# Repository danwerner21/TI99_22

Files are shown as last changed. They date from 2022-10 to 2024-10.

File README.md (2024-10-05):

# Texas Instruments TI99/4A Clone(ish) Project

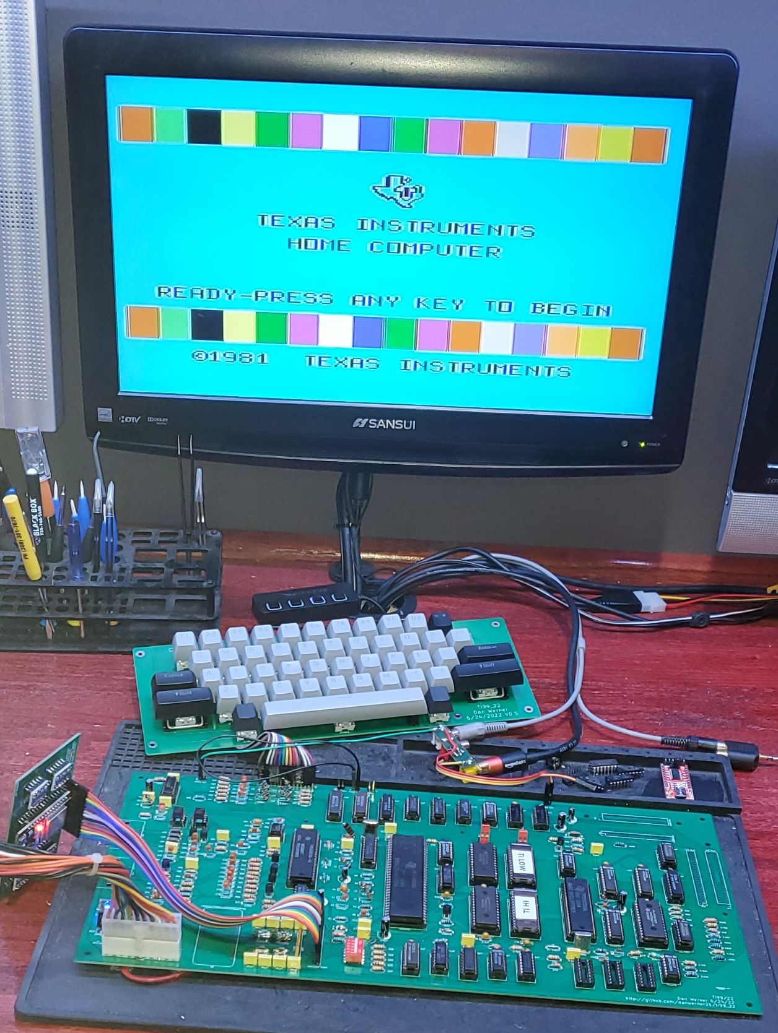
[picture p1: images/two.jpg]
System


Note that this is not a fully tested project at this point. . . .

This is based Rob Krenicki's design that is based on the HackMac KiCAD schematics.  I have made several changes to the original design including:

* Placing 32K of 16bit wide fast ram on the board to fully populate the address space
* Placing an EPROM on the main board that can be used as an on-board cartridge ROM
* adding a header to allow a microcontroller to replace the GROM chips (hopefully this can be moved on-board soon)
* replacing the video DRAM with SRAM
* Updating the Keyboard header to support a soft caps lock switch on the keyboard PCB
* designing a Cherry MX keyboard
* adding headers for the GROM and expansion port to support riser cards for these ports

If there are any questions, I can be reached at vic2020Dan at gmail dot com.

## ToDo
* Cleanup/Documentation
Possible Future Thoughts:
* Redo the Board in an ATX form factor with PEB slots on board
* Add Support for the Pico9918 on-board
* Add Support for a Tang Nano FPGA TMS9918 replacement 
* Add Hex-bus port
* Add a DIN 5-pin Composite video/Audio out. 
* Add built in speech synthesis
* Clone Disk IO card
* Relocate all the ports to the back of the motherboard

* It has been suggested that we also have a console style version of the next revision as not everyone has a desire for a larger PE style machine
* Also perhaps add some keys to the keyboard

## DIP Switch Settings
The DIP switch on the main board allows one to configure which bank areas are populated with RAM.

RAM0 enables RAM to addresses >2000-3FFF (Lo Memory Expansion)
RAM1 enables RAM to addresses >A000-BFFF (Hi Memory Expansion)
RAM2 enables RAM to addresses >C000-DFFF (Hi Memory Expansion)
RAM3 enables RAM to addresses >E000-FFFF  (Hi Memory Expansion)
RAM4 enables RAM to addresses >8000-83FF (Normal TI Scratch Pad RAM)

Note that I have never actually tested off-board 8 bit RAM, so this is new territory and might need some debugging 😊   
also on-board RAM is 16 bit – so all of those external RAM sources will be slower. 

## Bugs
* on rev 0.95 R36-40 are listed as 100K ohm, they are actually 100 ohm
* on rev 0.95 the joystick and cassette connectors are mirrored and need to be mounted on the bottom side of the board to function
* Both of these are corrected in 0.96

* The reset button J1 should be attached to pin 5 of U1 not Pin 4

## Bill of Materials
### Console
Qty|Reference(s)|Part
---|------------|----
6|C1, C9, C11, C58, C73, C75|0.001uF
1|C2|22pF
3|C3, C5, C59|22uF
12|C4, C7, C13, C14, C20, C54, C55, C62, C64, C68, C71, C74|0.1uF
1|C6|1uF
7|C8, C52, C63, C65, C66, C67, C72|0.01uF
1|C10|100uF
1|C12|0.01uF
7|C15, C16, C17, C19, C21, C22, C60|100uF
30|C18, C23, C24, C25, C26, C27, C28, C29, C30, C31, C32, C33, C34, C35, C36, C37, C38, C39, C40, C41, C42, C43, C44, C45, C46, C47, C48, C49, C50, C51|0.1uF
1|C53|100uF
1|C56|12pF
1|C57|56pF
1|C61|220uF
1|C69|220pF
1|C70|0.022uF
2|CR1, CR4|1N4148
2|CR2, CR3|1N914B
1|D1|LED
1|J1|Connector PinHeader 2.54mm:PinHeader 1x02 P2.54mm Vertical
1|J2|Connector PinHeader 2.54mm:PinHeader 1x02 P2.54mm Vertical
1|J3|TerminalBlock RND:TerminalBlock RND 205-00278 1x04 P5.00mm Vertical
1|J4|Connector PinHeader 2.54mm:PinHeader 1x16 P2.54mm Vertical
2|J5, J6|Connector PinHeader 2.54mm:PinHeader 1x03 P2.54mm Vertical
1|J7|Connector PinHeader 2.54mm:PinHeader 1x03 P2.54mm Vertical
1|J8|Connector PinHeader 2.54mm:PinHeader 1x02 P2.54mm Vertical
1|J9|Connector PinHeader 2.54mm:PinHeader 1x02 P2.54mm Vertical
1|J10|Connector Dsub:DSUB-9 Female Horizontal P2.77x2.84mm EdgePinOffset4.94mm Housed MountingHolesOffset7.48mm
1|J11|Connector PinHeader 2.54mm:PinHeader 1x18 P2.54mm Vertical
1|J12|Connector PinHeader 2.54mm:PinHeader 2x22 P2.54mm Vertical
1|J13|WernerCustomLibrary:44 Pin Card Edge
1|J14|Library:CardEdge 34Pin 2.54mm Vertical
1|J15|Connector PinHeader 2.54mm:PinHeader 2x18 P2.54mm Vertical
1|J16|Connector PinSocket 2.54mm:PinSocket 1x03 P2.54mm Vertical
1|J17|Connector PinSocket 2.54mm:PinSocket 1x03 P2.54mm Vertical
1|J18|Connector Dsub:DSUB-9 Female Horizontal P2.77x2.84mm EdgePinOffset4.94mm Housed MountingHolesOffset7.48mm
1|L1|0.33uH
2|L4, L5|6.8uH
1|L7|5.8uH
1|L8|INDUCTOR (Ferrite BEAD)
7|L10, L11, L12, L13, L14, L15, L16|8.2uH
3|Q1, Q3, Q4|TIS92
1|Q2|2N3904
1|R1|150k
7|R2, R9, R11, R18, R34, R35, R46|1k
1|R3|12k
1|R4|47k
4|R5, R6, R7, R8|22
5|R10, R26, R45, R52, R53|4.7k
5|R12, R13, R14, R15, R16|1K
3|R17, R48, R50|2.2k
2|R19, R30|470
1|R20|270
1|R21|1.5k x 9 SIP bussed
1|R22|361
3|R23, R73, R75|5.6k
2|R24, R27|10
1|R25|150
1|R28|470k
1|R29|0
2|R31, R33|75
1|R32|470
4|R41, R42, R43, R44|62
1|R47|3.3k
9|R36, R37, R38, R39, R40, R49, R51, R54, R56|100
1|R55|330
1|R57|10k
1|R58|6.8k
1|R59|39k
1|R60|6.8k
4|R61, R62, R67, R68|1K
1|R63|120k
1|R64|2.7k
3|R65, R66, R76|220
1|R69|10K
1|R70|9.1k
2|R71, R72|10k
1|R74|5.6K
1|R77|15
2|RN1, RN2|10K x 9 SIP Bussed
1|SW1|DIP switchx05
1|SW2|Pin Header 01x02 Male
1|U1|TMS9904 (note this needs to be a 9904 not 9904ANL.  If the 9904ANL is used, Y1 needs to be substituted with 12Mhz, L1 needs to be substituted with 3.3uh and C2 needs to be substituted with 50pf)
1|U2|TMS9900
4|U3, U15, U22, U24|74LS04
2|U4, U9|74LS32
2|U5, U8|74LS138
1|U6|74LS03
1|U7|74LS08
3|U10, U14, U18|74LS00
2|U11, U41|74LS244
1|U12|74LS373
1|U13|74LS245
1|U16|74LS74
1|U17|74LS194
1|U19|LM2901
1|U20|LM7905 TO220
1|U21|LM2903
3|U26, U27, U28|TMC0430
3|U29, U30, U37|HM62256BLP
2|U31, U32|27C64
1|U33|SN76489
1|U34|TMS9918
3|U35, U36, U38|74LS574
1|U39|TMS9901
1|U40|74LS156
2|U42, U43|74LS367
1|U44|74LS379
1|U45|27C010
1|U46|RC4558
1|U47|74LS06
2|U48, U49|TIL119
1|Y1|48.000 MHz Crystal
1|Y2|10.7MHz Crystal

# Keyboard
Qty|Reference(s)|Value|Part
---|------------|-----|----
1|C1|0.1uF|Capacitor
1|D1|LED|LED
1|D2|LED|LED
1|J1|Pin Header 1x18 male|Pin Header 1x18 male
2|R1, R2|470 ohm|Resistor
1|R3|1K ohm|Resistor
48|SW1-SW48|Mechanical Switch|Cherry MX Switch (or compatible)
1|U1|ATtiny13A-P|IC
1|U2|74LS125|IC
3||Switch Stabilizer 2.25|
1||Switch Stabilizer 6.25|
1||Optional Alignment frame (will need modified)|
|||
|Stabilizers (frame not used):|https://www.amazon.com/Genuine-Cherry-PCB-Snap-Stabilizers/dp/B085T8QZJC|
|Stabilizers (Frame used)|https://www.amazon.com/dp/B082X4V9VC|
|Frame:|https://www.amazon.com/gp/product/B07MMB33WG|

# Cartridge Riser
Qty|Reference(s)|Part|Type
---|------------|----|----
1|J1|Pin Header 01x18 Male|Pin Header 01x18 Male
1|J2|36 Pin Edge Connector|CONN EDGE DUAL FMALE 36POS 0.100 spacing

# IO Riser
Qty|Reference(s)|Part|Type
---|------------|----|----
1|J1|Pin Header 2x22 Male|Pin Header 2x22 Male

# UNICORN BOARD
Qty|Reference(s)|Part|Type
---|------------|----|----
1|J1|Pin Header Socket 01x16 Female Right Angle|Pin Header Socket 01x16 Female Right Angle
4|U1-U4|Level Shifter|https://www.amazon.com/KeeYees-Channels-Converter-Bi-Directional-Shifter/dp/B07LG646VS
1|U5|ESP32 Devkit|https://www.amazon.com/Development-Microcontroller-Integrated-Antenna-Amplifiers/dp/B09GK74F7N

## License

The original project was licensed under the Creative Commons - Attribution - ShareAlike 3.0 License

## Attribution

This board was derrived from works by, uses design elements from, or contains sofware writen by the following:
* Rob Krenicki (https://github.com/rkrenicki/TI99-Motherboard)
* HackMac (https://bitbucket.org/hackmac/ti-schematics/wiki/Home)

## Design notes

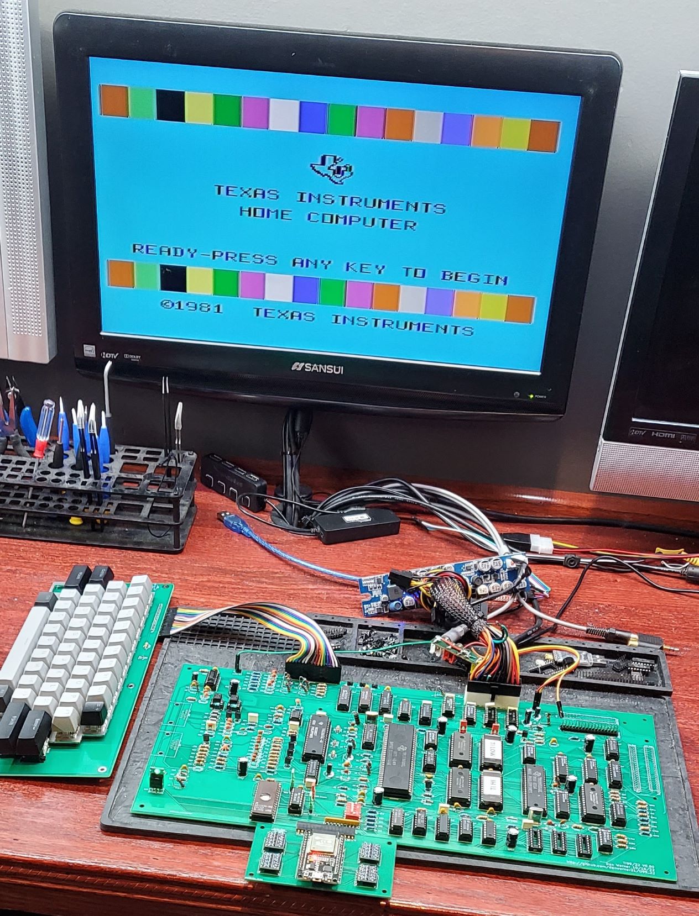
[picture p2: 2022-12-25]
images/three.jpg

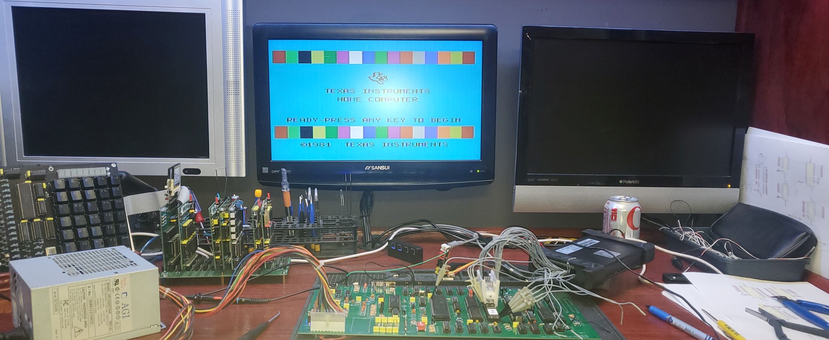
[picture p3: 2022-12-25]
images/one.jpg

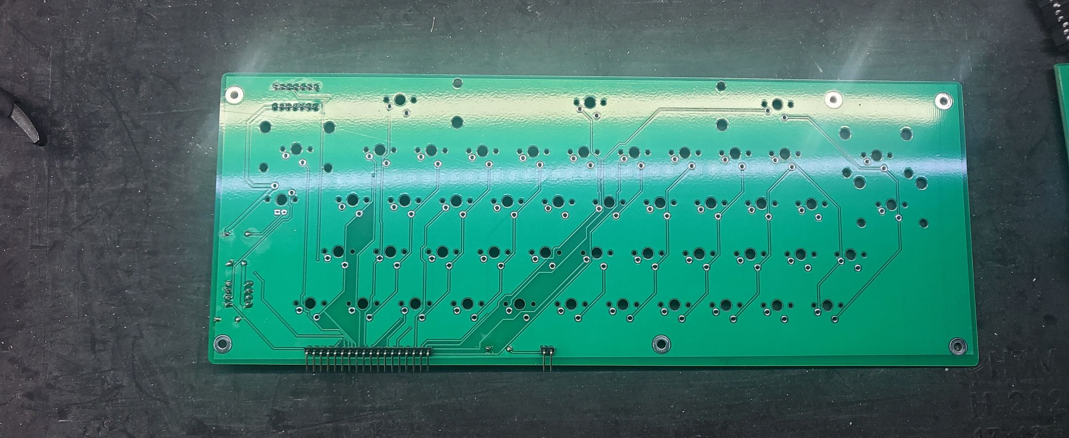
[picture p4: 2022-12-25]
images/a.jpg

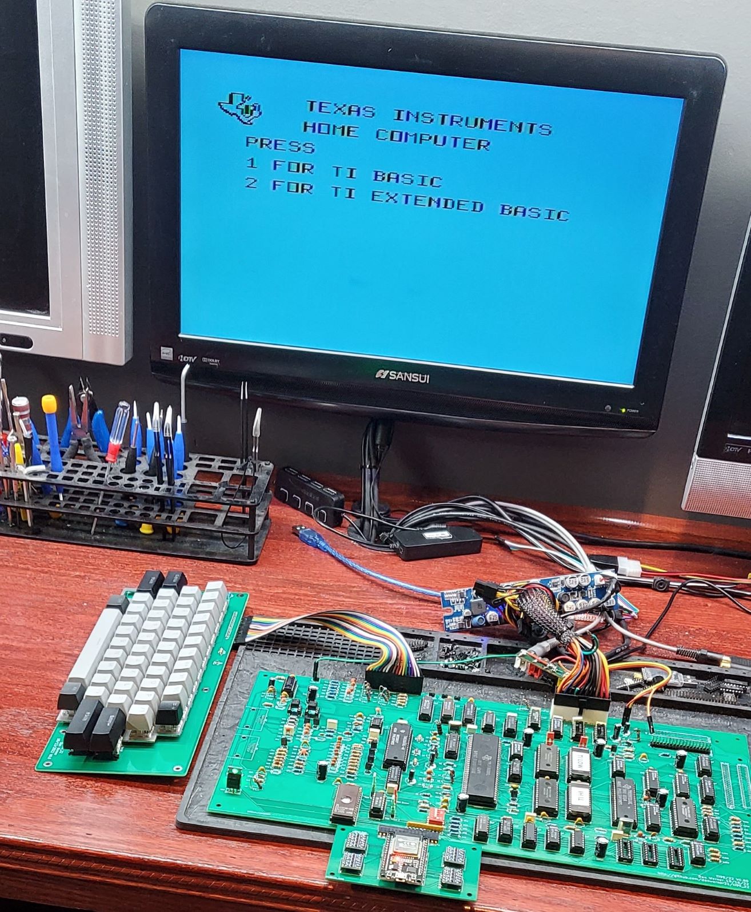
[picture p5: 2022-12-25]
images/four.jpg

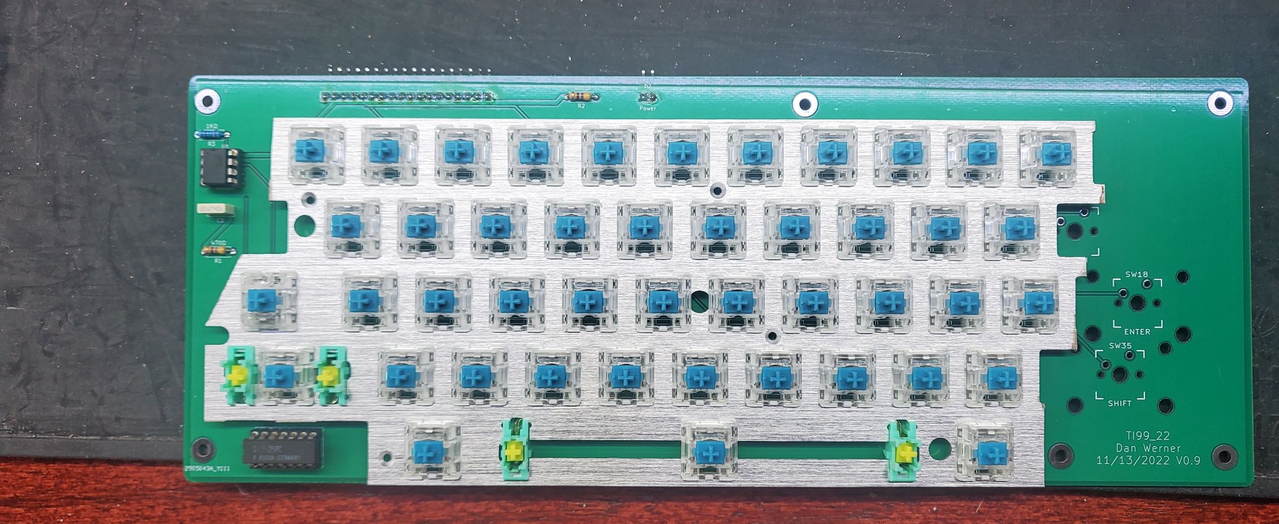
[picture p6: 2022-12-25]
images/c.jpg

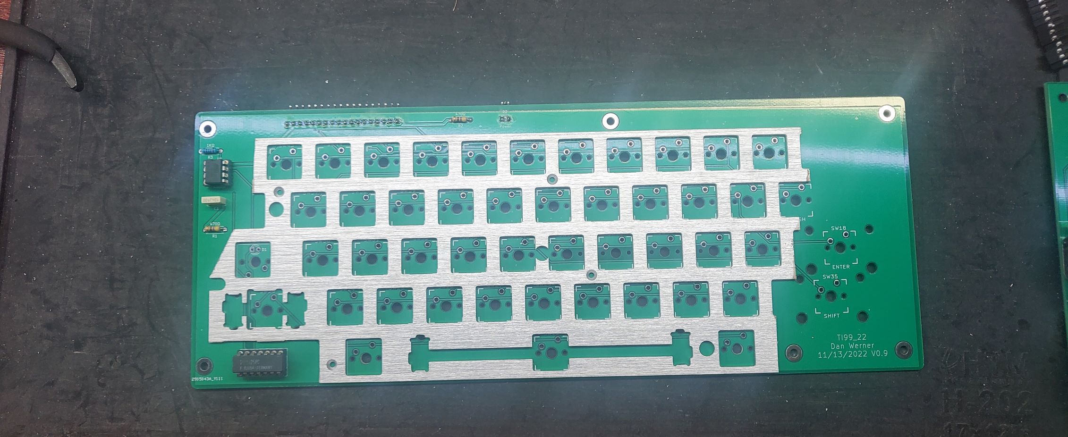
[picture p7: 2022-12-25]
images/b.jpg

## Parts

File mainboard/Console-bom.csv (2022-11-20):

Qty | Reference(s) | Part | Type
--- | ------------ | ---- | ----
30 | C1, C9, C11, C57, C63, C70, C71, C72, C73, C74, C75, C76, C77, C78, C80, C81, C82, C84, C85, C86, C87, C88, C89, C90, C91, C92, C93, C94, C95, C96 | 0.001uF | Capacitor
1 | C2 | 22pF | Capacitor
3 | C3, C5, C58 | 22uF electroyltic | Electrolytic Capacitor
38 | C4, C7, C13, C14, C19, C22, C23, C24, C25, C26, C27, C28, C29, C30, C31, C32, C33, C34, C35, C36, C37, C38, C39, C40, C41, C42, C43, C44, C45, C46, C47, C48, C49, C50, C53, C54, C66, C69 | 0.1uF | Capacitor
1 | C6 | 1uF | Capacitor
8 | C8, C12, C51, C62, C64, C65, C79, C83 | 0.01uF | Capacitor
1 | C10 | 100uF | Capacitor
6 | C15, C16, C17, C18, C20, C21,C52,C59 | 100uF electrolytic | Electrolytic Capacitor
1 | C55 | 12pF | Capacitor
1 | C56 | 56pF | Capacitor
1 | C60 | 220uF electrolytic | Electrolytic Capacitor
1 | C61 | 0.1uF | Capacitor
1 | C67 | 220pF | Capacitor
1 | C68 | 0.022uF | Capacitor
2 | CR1, CR4 | 1N4148 | Diode
2 | CR2, CR3 | 1N914B | Diode
1 | D1 | LED | LED
1 | J1 | Pin Header 01x02 Male | Pin Header 01x02 Male
1 | J2 | Pin Header 01x02 Male | Pin Header 01x02 Male
1 | J3 | Screw Terminal 1x4 | Screw Terminal 1x4
1 | J4 | Pin Header 01x16 Male | Pin Header 01x16 Male
2 | J5, J6 | Pin Header 01x02 Male | Pin Header 01x02 Male
1 | J7 | Pin Header 01x02 Male | Pin Header 01x02 Male
1 | J8 | Pin Header 01x02 Male | Pin Header 01x02 Male
1 | J9 | DB9 Connector Right Angle Male | DB9 Connector Right Angle Male
1 | J10 | DB9 Connector Right Angle Male | DB9 Connector Right Angle Male
1 | J11 | Pin Header 01x18 Male | Pin Header 01x18 Male
1 | J12 | Pin Header 2x22 Male | Pin Header 2x22 Male
1 | J14 | 36 Pin Edge Connector | CONN EDGE DUAL FMALE 36POS 0.100 spacing
1 | J15 | Pin Header 02x18 Male | Pin Header 02x18 Male
1 | J16 | Pin Header 01x03 Male | Pin Header 01x03 Male
1 | J17 | Pin Header 01x03 Male | Pin Header 01x03 Male
1 | L1 | 0.33uH Inductor | Inductor
9 | L2, L3, L4, L12, L13, L14, L15, L16, L17 | 6.8uH Inductor | Inductor
4 | L5, L6, L7, L11 | 6.8uH Inductor | Inductor
1 | L8 | 2- 4.5uH Inductor | Variable Inductor
1 | L9 | 5.8uH Inductor | Inductor
1 | L10, L18, L19, L20, L21 | INDUCTOR (BEAD) | Ferrite Bead
8 | Q1, Q3, Q4, Q5, Q6, Q7, Q8, Q9 | TIS92 Transistor | Transistor
1 | Q2 | 2N3904 Transistor | Transistor
1 | R1 | 150kohm | Resistor
11 | R2, R9, R11, R18, R51, R52, R53, R54, R55, R56, R89 | 1kohm | Resistor
1 | R3 | 12kohm | Resistor
1 | R4 | 47kohm | Resistor
4 | R5, R6, R7, R8 | 22ohm | Resistor
5 | R10, R26, R88, R95, R96 | 4.7kohm | Resistor
5 | R12, R13, R14, R15, R16 | 1Kohm | Resistor
3 | R17, R91, R93 | 2.2kohm | Resistor
11 | R19, R30, R63, R65, R67, R69, R71, R75, R77, R79, R82 | 470ohm | Resistor
1 | R20 | 270ohm | Resistor
1 | R21 | 1.5kohm | Resistor Network 9 pin
1 | R22 | 361ohm | Resistor
4 | R23, R35, R60, R81 | 5.6kohm | Resistor
4 | R24, R27, R80, R83 | 10ohm | Resistor
1 | R25 | 150ohm | Resistor
1 | R28 | 470kohm | Resistor
1 | R29 | 0ohm | Resistor
2 | R31, R33 | 75ohm | Resistor
1 | R32 | 470ohm | Resistor
11 | R34, R40, R41, R42, R43, R44, R45, R46, R47, R48, R100 | 10kohm | Resistor
2 | R36, R58 | 6.8kohm | Resistor
1 | R37 | 2.2kohm | Resistor
1 | R38 | 200ohm | Resistor
1 | R39 | 120kohm | Resistor
1 | R49 | 39kohm | Resistor
1 | R50 | 6.8kohm | Resistor
1 | R57 | 12kohm | Resistor
1 | R59 | 15ohm | Resistor
2 | R61, R62 | 10kohm | Resistor
2 | R64, R72 | 1kohm | Resistor
2 | R66, R76 | 1.5kohm | Resistor
2 | R68, R78 | 270ohm | Resistor
1 | R70 | 9.1kohm | Resistor
2 | R73, R74 | 220ohm | Resistor
4 | R84, R85, R86, R87 | 62ohm | Resistor
1 | R90 | 3.3kohm | Resistor
4 | R92, R94, R97, R99 | 100ohm | Resistor
1 | R98 | 330ohm | Resistor
1 | SW1 | Dip Switch 6 pos | Dip Switch 6 pos
1 | SW2 | Pin Header 01x02 Male | Pin Header 01x02 Male
1 | U1 | TIM9904 | IC
1 | U2 | TMS9900 | IC
4 | U3, U15, U20, U21 | 74LS04 | IC
2 | U4, U9 | 74LS32 | IC
2 | U5, U8 | 74LS138 | IC
1 | U6 | 74LS03 | IC
1 | U7 | 74LS08 | IC
3 | U10, U14, U18 | 74LS00 | IC
2 | U11, U40 | 74LS244 | IC
1 | U12 | 74LS373 | IC
1 | U13 | 74LS245 | IC
1 | U16 | 74LS74 | IC
1 | U17 | 74LS194 | IC
1 | U19 | LM7905_TO220 | IC
3 | U22, U23, U24 | TMC0430 | IC (optional, replaced by Unicorn Board only known source is from TI/994a console)
3 | U25, U26, U33 | HM62256BLP | IC
2 | U27, U28 | 27C64 | IC
1 | U29 | SN76489 | IC
1 | U30 | TMS9918 | IC
3 | U31, U32, U34 | 74LS574 | IC
1 | U35 | TMS9901 | IC
1 | U36 | RC4558 | IC
1 | U37 | 74LS156 | IC
2 | U38, U39 | TIL119 | IC
2 | U41, U42 | 74LS367 | IC
1 | U43 | 74LS379 | IC
1 | U44 | 27C010 | IC
1 | Y1 | 48.000 MHz Crystal | Crystal
1 | Y2 | 10.7MHz Crystal | Crystal

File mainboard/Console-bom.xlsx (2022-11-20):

Qty | Reference(s) | Part | LibPart | Footprint
30 | C1, C9, C11, C57, C63, C70, C71, C72, C73, C74, C75, C76, C77, C78, C80, C81, C82, C84, C85, C86, C87, C88, C89, C90, C91, C92, C93, C94, C95, C96 | 0.001uF | TI-Customs:C_Small | Capacitor_THT:C_Rect_L7.0mm_W2.0mm_P5.00mm
1 | C2 | 22pF | TI-Customs:C_Small | Capacitor_THT:C_Rect_L7.0mm_W2.0mm_P5.00mm
3 | C3, C5, C58 | 22uF electroyltic | HC3-rescue:CP | Capacitor_THT:CP_Radial_D7.5mm_P2.50mm
38 | C4, C7, C13, C14, C19, C22, C23, C24, C25, C26, C27, C28, C29, C30, C31, C32, C33, C34, C35, C36, C37, C38, C39, C40, C41, C42, C43, C44, C45, C46, C47, C48, C49, C50, C53, C54, C66, C69 | 0.1uF | TI-Customs:C_Small | Capacitor_THT:C_Rect_L7.0mm_W2.0mm_P5.00mm
1 | C6 | 1uF | TI-Customs:C_Small | Capacitor_THT:C_Rect_L7.0mm_W2.0mm_P5.00mm
8 | C8, C12, C51, C62, C64, C65, C79, C83 | 0.01uF | TI-Customs:C_Small | Capacitor_THT:C_Rect_L7.0mm_W2.0mm_P5.00mm
1 | C10 | 100uF | Device:CP_Small | Capacitor_THT:CP_Radial_D7.5mm_P2.50mm
6 | C15, C16, C17, C18, C20, C21,C52,C59 | 100uF electrolytic | Device:C_Polarized | Capacitor_THT:CP_Radial_D7.5mm_P2.50mm
1 | C55 | 12pF | TI-Customs:C_Small | Capacitor_THT:C_Rect_L7.0mm_W2.0mm_P5.00mm
1 | C56 | 56pF | TI-Customs:C_Small | Capacitor_THT:C_Rect_L7.0mm_W2.0mm_P5.00mm
1 | C60 | 220uF electrolytic | HC3-rescue:CP | Capacitor_THT:CP_Radial_D7.5mm_P2.50mm
1 | C61 | 0.1uF | HC3-rescue:C | Capacitor_THT:C_Rect_L7.0mm_W2.0mm_P5.00mm
1 | C67 | 220pF | TI-Customs:C_Small | Capacitor_THT:C_Rect_L7.0mm_W2.0mm_P5.00mm
1 | C68 | 0.022uF | TI-Customs:C_Small | Capacitor_THT:C_Rect_L7.0mm_W2.0mm_P5.00mm
2 | CR1, CR4 | 1N4148 | Console-rescue:D | Diode_THT:D_A-405_P7.62mm_Horizontal
2 | CR2, CR3 | 1N914B | Console-rescue:D | Diode_THT:D_A-405_P7.62mm_Horizontal
1 | D1 | LED | Device:LED | LED_THT:LED_D5.0mm
1 | J1 | Pin Header 01x02 Male | Connector:Conn_01x02_Male | Connector_PinHeader_2.54mm:PinHeader_1x02_P2.54mm_Vertical
1 | J2 | Pin Header 01x02 Male | Connector:Conn_01x02_Male | Connector_PinHeader_2.54mm:PinHeader_1x02_P2.54mm_Vertical
1 | J3 | Screw Terminal 1x4 | Connector:Screw_Terminal_01x04 | TerminalBlock_RND:TerminalBlock_RND_205-00278_1x04_P5.00mm_Vertical
1 | J4 | Pin Header 01x16 Male | Connector:Conn_01x16_Male | Connector_PinHeader_2.54mm:PinHeader_1x16_P2.54mm_Vertical
2 | J5, J6 | Pin Header 01x02 Male | Connector:Conn_01x03_Male | Connector_PinHeader_2.54mm:PinHeader_1x03_P2.54mm_Vertical
1 | J7 | Pin Header 01x02 Male | Connector:Conn_01x02_Male | Connector_PinHeader_2.54mm:PinHeader_1x02_P2.54mm_Vertical
1 | J8 | Pin Header 01x02 Male | Connector:Conn_01x02_Male | Connector_PinHeader_2.54mm:PinHeader_1x02_P2.54mm_Vertical
1 | J9 | DB9 Connector Right Angle Male | Connector:DB9_Male_MountingHoles | Connector_Dsub:DSUB-9_Female_Horizontal_P2.77x2.84mm_EdgePinOffset4.94mm_Housed_MountingHolesOffset7.48mm
1 | J10 | DB9 Connector Right Angle Male | Connector:DB9_Male_MountingHoles | Connector_Dsub:DSUB-9_Female_Horizontal_P2.77x2.84mm_EdgePinOffset4.94mm_Housed_MountingHolesOffset7.48mm
1 | J11 | Pin Header 01x18 Male | Connector_Generic:Conn_01x18 | Connector_PinHeader_2.54mm:PinHeader_1x18_P2.54mm_Vertical
1 | J12 | Pin Header 2x22 Male | Connector_Generic:Conn_02x22_Odd_Even | Connector_PinHeader_2.54mm:PinHeader_2x22_P2.54mm_Vertical
1 | J14 | 34 Pin Edge Connector | Connector_Generic:Conn_02x18_Odd_Even | Library:CardEdge_34Pin_2.54mm_Vertical
1 | J15 | Pin Header 02x18 Male | Connector_Generic:Conn_02x18_Odd_Even | Connector_PinHeader_2.54mm:PinHeader_2x18_P2.54mm_Vertical
1 | J16 | Pin Header 01x03 Male | Connector:Conn_01x03_Male | Connector_PinSocket_2.54mm:PinSocket_1x03_P2.54mm_Vertical
1 | J17 | Pin Header 01x03 Male | Connector:Conn_01x03_Male | Connector_PinSocket_2.54mm:PinSocket_1x03_P2.54mm_Vertical
1 | L1 | 0.33uH Inductor | Console-rescue:L_Small | Resistor_THT:R_Axial_DIN0207_L6.3mm_D2.5mm_P7.62mm_Horizontal
9 | L2, L3, L4, L12, L13, L14, L15, L16, L17 | 6.8uH Inductor | Console-rescue:L_Small | Resistor_THT:R_Axial_DIN0207_L6.3mm_D2.5mm_P7.62mm_Horizontal
4 | L5, L6, L7, L11 | 6.8uH Inductor | Console-rescue:INDUCTOR_SMALL | Resistor_THT:R_Axial_DIN0207_L6.3mm_D2.5mm_P7.62mm_Horizontal
1 | L8 | 2- 4.5uH Inductor | Console-rescue:INDUCTANCE_Adjustable_RevE_Date03Aug2010 | Resistor_THT:R_Axial_DIN0207_L6.3mm_D2.5mm_P7.62mm_Horizontal
1 | L9 | 5.8uH Inductor | Console-rescue:INDUCTOR_SMALL | Resistor_THT:R_Axial_DIN0207_L6.3mm_D2.5mm_P7.62mm_Horizontal
1 | L10, L18, L19, L20, L21 | INDUCTOR (BEAD) | HC3-rescue:INDUCTOR | Resistor_THT:R_Axial_DIN0207_L6.3mm_D2.5mm_P10.16mm_Horizontal
8 | Q1, Q3, Q4, Q5, Q6, Q7, Q8, Q9 | TIS92 Transistor | Console-rescue:S8050 | Package_TO_SOT_THT:TO-92_HandSolder
1 | Q2 | 2N3904 Transistor | HC3-rescue:NPN | Package_TO_SOT_THT:TO-92L_HandSolder
1 | R1 | 150kohm | Console-rescue:R | Resistor_THT:R_Axial_DIN0207_L6.3mm_D2.5mm_P7.62mm_Horizontal
11 | R2, R9, R11, R18, R51, R52, R53, R54, R55, R56, R89 | 1kohm | Console-rescue:R | Resistor_THT:R_Axial_DIN0207_L6.3mm_D2.5mm_P7.62mm_Horizontal
1 | R3 | 12kohm | Console-rescue:R | Resistor_THT:R_Axial_DIN0207_L6.3mm_D2.5mm_P7.62mm_Horizontal
1 | R4 | 47kohm | Console-rescue:R | Resistor_THT:R_Axial_DIN0207_L6.3mm_D2.5mm_P7.62mm_Horizontal
4 | R5, R6, R7, R8 | 22ohm | Console-rescue:R | Resistor_THT:R_Axial_DIN0207_L6.3mm_D2.5mm_P7.62mm_Horizontal
5 | R10, R26, R88, R95, R96 | 4.7kohm | Console-rescue:R | Resistor_THT:R_Axial_DIN0207_L6.3mm_D2.5mm_P7.62mm_Horizontal
5 | R12, R13, R14, R15, R16 | 1Kohm | Device:R | Resistor_THT:R_Axial_DIN0207_L6.3mm_D2.5mm_P7.62mm_Horizontal
3 | R17, R91, R93 | 2.2kohm | Console-rescue:R | Resistor_THT:R_Axial_DIN0207_L6.3mm_D2.5mm_P7.62mm_Horizontal
11 | R19, R30, R63, R65, R67, R69, R71, R75, R77, R79, R82 | 470ohm | Console-rescue:R | Resistor_THT:R_Axial_DIN0207_L6.3mm_D2.5mm_P7.62mm_Horizontal
1 | R20 | 270ohm | Console-rescue:R | Resistor_THT:R_Axial_DIN0207_L6.3mm_D2.5mm_P7.62mm_Horizontal
1 | R21 | 1.5kohm | Device:R_Network09 | Resistor_THT:R_Array_SIP10
1 | R22 | 361ohm | Console-rescue:R_Small | Resistor_THT:R_Axial_DIN0207_L6.3mm_D2.5mm_P7.62mm_Horizontal
4 | R23, R35, R60, R81 | 5.6kohm | Console-rescue:R_Small | Resistor_THT:R_Axial_DIN0207_L6.3mm_D2.5mm_P7.62mm_Horizontal
4 | R24, R27, R80, R83 | 10ohm | Console-rescue:R_Small | Resistor_THT:R_Axial_DIN0207_L6.3mm_D2.5mm_P7.62mm_Horizontal
1 | R25 | 150ohm | Console-rescue:R_Small | Resistor_THT:R_Axial_DIN0207_L6.3mm_D2.5mm_P7.62mm_Horizontal
1 | R28 | 470kohm | Console-rescue:R | Resistor_THT:R_Axial_DIN0207_L6.3mm_D2.5mm_P7.62mm_Horizontal
1 | R29 | 0ohm | HC3-rescue:R | Resistor_THT:R_Axial_DIN0207_L6.3mm_D2.5mm_P7.62mm_Horizontal
2 | R31, R33 | 75ohm | HC3-rescue:R | Resistor_THT:R_Axial_DIN0207_L6.3mm_D2.5mm_P7.62mm_Horizontal
1 | R32 | 470ohm | Console-rescue:R_Small | Resistor_THT:R_Axial_DIN0207_L6.3mm_D2.5mm_P7.62mm_Horizontal
11 | R34, R40, R41, R42, R43, R44, R45, R46, R47, R48, R100 | 10kohm | Device:R | Resistor_THT:R_Axial_DIN0207_L6.3mm_D2.5mm_P7.62mm_Horizontal
2 | R36, R58 | 6.8kohm | Console-rescue:R_Small | Resistor_THT:R_Axial_DIN0207_L6.3mm_D2.5mm_P7.62mm_Horizontal
1 | R37 | 2.2kohm | Console-rescue:R_Small | Resistor_THT:R_Axial_DIN0207_L6.3mm_D2.5mm_P7.62mm_Horizontal
1 | R38 | 200ohm | Console-rescue:R_Small | Resistor_THT:R_Axial_DIN0207_L6.3mm_D2.5mm_P7.62mm_Horizontal
1 | R39 | 120kohm | Console-rescue:R_Small | Resistor_THT:R_Axial_DIN0207_L6.3mm_D2.5mm_P7.62mm_Horizontal
1 | R49 | 39kohm | Console-rescue:R_Small | Resistor_THT:R_Axial_DIN0207_L6.3mm_D2.5mm_P7.62mm_Horizontal
1 | R50 | 6.8kohm | Console-rescue:R | Resistor_THT:R_Axial_DIN0207_L6.3mm_D2.5mm_P7.62mm_Horizontal
1 | R57 | 12kohm | Console-rescue:R_Small | Resistor_THT:R_Axial_DIN0207_L6.3mm_D2.5mm_P7.62mm_Horizontal
1 | R59 | 15ohm | Console-rescue:R_Small | Resistor_THT:R_Axial_DIN0207_L6.3mm_D2.5mm_P7.62mm_Horizontal
2 | R61, R62 | 10kohm | Console-rescue:R_Small | Resistor_THT:R_Axial_DIN0207_L6.3mm_D2.5mm_P7.62mm_Horizontal
2 | R64, R72 | 1kohm | Console-rescue:R_Small | Resistor_THT:R_Axial_DIN0207_L6.3mm_D2.5mm_P7.62mm_Horizontal
2 | R66, R76 | 1.5kohm | Console-rescue:R_Small | Resistor_THT:R_Axial_DIN0207_L6.3mm_D2.5mm_P7.62mm_Horizontal
2 | R68, R78 | 270ohm | Console-rescue:R_Small | Resistor_THT:R_Axial_DIN0207_L6.3mm_D2.5mm_P7.62mm_Horizontal
1 | R70 | 9.1kohm | Console-rescue:R_Small | Resistor_THT:R_Axial_DIN0207_L6.3mm_D2.5mm_P7.62mm_Horizontal
2 | R73, R74 | 220ohm | Console-rescue:R_Small | Resistor_THT:R_Axial_DIN0207_L6.3mm_D2.5mm_P7.62mm_Horizontal
4 | R84, R85, R86, R87 | 62ohm | Console-rescue:R | Resistor_THT:R_Axial_DIN0207_L6.3mm_D2.5mm_P7.62mm_Horizontal
1 | R90 | 3.3kohm | Console-rescue:R | Resistor_THT:R_Axial_DIN0207_L6.3mm_D2.5mm_P7.62mm_Horizontal
4 | R92, R94, R97, R99 | 100ohm | Console-rescue:R | Resistor_THT:R_Axial_DIN0207_L6.3mm_D2.5mm_P7.62mm_Horizontal
1 | R98 | 330ohm | Console-rescue:R | Resistor_THT:R_Axial_DIN0207_L6.3mm_D2.5mm_P7.62mm_Horizontal
1 | SW1 | Dip Switch 6 pos | Switch:SW_DIP_x05 | Package_DIP:DIP-10_W7.62mm_Socket_LongPads
1 | SW2 | Pin Header 01x02 Male | Switch:SW_DIP_x01 | Connector_PinHeader_2.54mm:PinHeader_1x02_P2.54mm_Vertical
1 | U1 | TIM9904 | TI-Customs:TIM9904 | Package_DIP:DIP-20_W7.62mm_Socket_LongPads
1 | U2 | TMS9900 | TI-Customs:TMS9900 | Package_DIP:DIP-64_W22.86mm_Socket_LongPads
4 | U3, U15, U20, U21 | 74LS04 | 74xx:74LS04 | Package_DIP:DIP-14_W7.62mm_Socket_LongPads
2 | U4, U9 | 74LS32 | 74xx:74LS32 | Package_DIP:DIP-14_W7.62mm_Socket_LongPads
2 | U5, U8 | 74LS138 | 74xx:74LS138 | Package_DIP:DIP-16_W7.62mm_Socket_LongPads
1 | U6 | 74LS03 | 74xx:74LS03 | Package_DIP:DIP-14_W7.62mm_Socket_LongPads
1 | U7 | 74LS08 | 74xx:74LS08 | Package_DIP:DIP-14_W7.62mm_Socket_LongPads
3 | U10, U14, U18 | 74LS00 | 74xx:74LS00 | Package_DIP:DIP-14_W7.62mm_Socket_LongPads
2 | U11, U40 | 74LS244 | 74xx:74LS244 | Package_DIP:DIP-20_W7.62mm_Socket_LongPads
1 | U12 | 74LS373 | 74xx:74LS373 | Package_DIP:DIP-20_W7.62mm_Socket_LongPads
1 | U13 | 74LS245 | 74xx:74LS245 | Package_DIP:DIP-20_W7.62mm_Socket_LongPads
1 | U16 | 74LS74 | 74xx:74LS74 | Package_DIP:DIP-14_W7.62mm_Socket_LongPads
1 | U17 | 74LS194 | 74xx:74LS194 | Package_DIP:DIP-16_W7.62mm_Socket_LongPads
1 | U19 | LM7905_TO220 | Regulator_Linear:LM7905_TO220 | Package_TO_SOT_THT:TO-220-3_Vertical
3 | U22, U23, U24 | TMC0430 | TI-Customs:TMC0430 | Package_DIP:DIP-16_W7.62mm_Socket_LongPads
3 | U25, U26, U33 | HM62256BLP | Memory_RAM:HM62256BLP | Package_DIP:DIP-28_W15.24mm_Socket_LongPads
2 | U27, U28 | 27C64 | Memory_EPROM:27C64 | Package_DIP:DIP-28_W15.24mm_Socket_LongPads
1 | U29 | SN76489 | TI-Customs:SN76489 | Package_DIP:DIP-16_W7.62mm_Socket_LongPads
1 | U30 | TMS9918 | TI:TMS9918 | Package_DIP:DIP-40_W15.24mm_Socket_LongPads
3 | U31, U32, U34 | 74LS574 | 74xx:74LS574 | Package_DIP:DIP-20_W7.62mm_Socket_LongPads
1 | U35 | TMS9901 | TI-Customs:TMS9901 | Package_DIP:DIP-40_W15.24mm_Socket_LongPads
1 | U36 | RC4558 | Console-rescue:LM358 | Package_DIP:DIP-8_W7.62mm_Socket_LongPads
1 | U37 | 74LS156 | 74xx:74LS156 | Package_DIP:DIP-16_W7.62mm_Socket_LongPads
2 | U38, U39 | TIL119 | Console-rescue:TIL111 | Package_DIP:DIP-6_W7.62mm_Socket_LongPads
2 | U41, U42 | 74LS367 | 74xx:74LS367 | Package_DIP:DIP-16_W7.62mm_Socket_LongPads
1 | U43 | 74LS379 | 74xx:74LS379 | Package_DIP:DIP-16_W7.62mm_Socket_LongPads
1 | U44 | 27C010 | Werner_custom:27C010-C | Package_DIP:DIP-32_W15.24mm_Socket_LongPads
1 | Y1 | 48.000 MHz Crystal | Console-rescue:Crystal | Crystal:Crystal_HC49-U_Vertical
1 | Y2 | 10.7MHz Crystal | Console-rescue:XTAL_2-TERMINAL_RevE_Date15jun2010 | Crystal:Crystal_HC49-U_Vertical

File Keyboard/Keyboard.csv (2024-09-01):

Source: | N:\Vintage\Projects\TI99_22\Keyboard\Keyboard.kicad_sch
Date: | 4/13/2024 9:07:25 AM
Tool: | Eeschema (6.0.11)
Generator: | C:\Program Files\KiCad\6.0\bin\scripting\plugins/bom_csv_grouped_by_value.py
Component Count: | 63
Individual Components:
Item | Qty | Reference(s) | Value | LibPart | Footprint | Datasheet
 |  | C1 | 0.1µF | Device:C | Capacitor_THT:C_Disc_D7.0mm_W2.5mm_P5.00mm | ~
 |  | D1 | Alpha | Device:LED | LED_THT:LED_D3.0mm | ~
 |  | D2 | Power | Device:LED | LED_THT:LED_D3.0mm | ~
 |  | H1 | MountingHole | Mechanical:MountingHole | MountingHole:MountingHole_3.2mm_M3_Pad | ~
 |  | H2 | MountingHole | Mechanical:MountingHole | MountingHole:MountingHole_3.2mm_M3_Pad | ~
 |  | H3 | MountingHole | Mechanical:MountingHole | MountingHole:MountingHole_3.2mm_M3_Pad | ~
 |  | H4 | MountingHole | Mechanical:MountingHole | MountingHole:MountingHole_3.2mm_M3_Pad | ~
 |  | H5 | MountingHole | Mechanical:MountingHole | MountingHole:MountingHole_3.2mm_M3_Pad | ~
 |  | H6 | MountingHole | Mechanical:MountingHole | MountingHole:MountingHole_3.2mm_M3_Pad | ~
 |  | J1 | Computer | Connector_Generic:Conn_01x18 | Connector_PinHeader_2.54mm:PinHeader_1x18_P2.54mm_Vertical | ~
 |  | R1 | 470Ω | Device:R | Resistor_THT:R_Axial_DIN0207_L6.3mm_D2.5mm_P7.62mm_Horizontal | ~
 |  | R2 | 470Ω | Device:R | Resistor_THT:R_Axial_DIN0207_L6.3mm_D2.5mm_P7.62mm_Horizontal | ~
 |  | R3 | 1KΩ | Device:R | Resistor_THT:R_Axial_DIN0207_L6.3mm_D2.5mm_P7.62mm_Horizontal | ~
 |  | SW1 | SLASH | Switch:SW_Push_45deg | Cherry_MX:CHERRY_PCB_100H | ~
 |  | SW2 | PERIOD | Switch:SW_Push_45deg | Cherry_MX:CHERRY_PCB_100H | ~
 |  | SW3 | COMMA | Switch:SW_Push_45deg | Cherry_MX:CHERRY_PCB_100H | ~
 |  | SW4 | M | Switch:SW_Push_45deg | Cherry_MX:CHERRY_PCB_100H | ~
 |  | SW5 | N | Switch:SW_Push_45deg | Cherry_MX:CHERRY_PCB_100H | ~
 |  | SW6 | EQUALS | Switch:SW_Push_45deg | Cherry_MX:CHERRY_PCB_100H | ~
 |  | SW7 | COLON | Switch:SW_Push_45deg | Cherry_MX:CHERRY_PCB_100H | ~
 |  | SW8 | L | Switch:SW_Push_45deg | Cherry_MX:CHERRY_PCB_100H | ~
 |  | SW9 | K | Switch:SW_Push_45deg | Cherry_MX:CHERRY_PCB_100H | ~
 |  | SW10 | J | Switch:SW_Push_45deg | Cherry_MX:CHERRY_PCB_100H | ~
 |  | SW11 | H | Switch:SW_Push_45deg | Cherry_MX:CHERRY_PCB_100H | ~
 |  | SW12 | SPACE | Switch:SW_Push_45deg | Cherry_MX:CHERRY_PCB_625H | ~
 |  | SW13 | P | Switch:SW_Push_45deg | Cherry_MX:CHERRY_PCB_100H | ~
 |  | SW14 | O | Switch:SW_Push_45deg | Cherry_MX:CHERRY_PCB_100H | ~
 |  | SW15 | I | Switch:SW_Push_45deg | Cherry_MX:CHERRY_PCB_100H | ~
 |  | SW16 | U | Switch:SW_Push_45deg | Cherry_MX:CHERRY_PCB_100H | ~
 |  | SW17 | Y | Switch:SW_Push_45deg | Cherry_MX:CHERRY_PCB_100H | ~
 |  | SW18 | ENTER | Switch:SW_Push_45deg | Cherry_MX:CHERRY_PCB_225H | ~
 |  | SW19 | 0 | Switch:SW_Push_45deg | Cherry_MX:CHERRY_PCB_100H | ~
 |  | SW20 | 9 | Switch:SW_Push_45deg | Cherry_MX:CHERRY_PCB_100H | ~
 |  | SW21 | 8 | Switch:SW_Push_45deg | Cherry_MX:CHERRY_PCB_100H | ~
 |  | SW22 | 7 | Switch:SW_Push_45deg | Cherry_MX:CHERRY_PCB_100H | ~
 |  | SW23 | 6 | Switch:SW_Push_45deg | Cherry_MX:CHERRY_PCB_100H | ~
 |  | SW24 | Z | Switch:SW_Push_45deg | Cherry_MX:CHERRY_PCB_100H | ~
 |  | SW25 | X | Switch:SW_Push_45deg | Cherry_MX:CHERRY_PCB_100H | ~
 |  | SW26 | C | Switch:SW_Push_45deg | Cherry_MX:CHERRY_PCB_100H | ~
 |  | SW27 | V | Switch:SW_Push_45deg | Cherry_MX:CHERRY_PCB_100H | ~
 |  | SW28 | B | Switch:SW_Push_45deg | Cherry_MX:CHERRY_PCB_100H | ~
 |  | SW29 | LOCK | Switch:SW_Push_45deg | Button_Switch_Keyboard:SW_Cherry_MX_1.75u_PCB | ~
 |  | SW30 | A | Switch:SW_Push_45deg | Cherry_MX:CHERRY_PCB_100H | ~
 |  | SW31 | S | Switch:SW_Push_45deg | Cherry_MX:CHERRY_PCB_100H | ~
 |  | SW32 | D | Switch:SW_Push_45deg | Cherry_MX:CHERRY_PCB_100H | ~
 |  | SW33 | F | Switch:SW_Push_45deg | Cherry_MX:CHERRY_PCB_100H | ~
 |  | SW34 | G | Switch:SW_Push_45deg | Cherry_MX:CHERRY_PCB_100H | ~
 |  | SW35 | SHIFT | Switch:SW_Push_45deg | Cherry_MX:CHERRY_PCB_275H | ~
 |  | SW36 | SHIFT | Switch:SW_Push_45deg | Cherry_MX:CHERRY_PCB_225H | ~
 |  | SW37 | Q | Switch:SW_Push_45deg | Cherry_MX:CHERRY_PCB_100H | ~
 |  | SW38 | W | Switch:SW_Push_45deg | Cherry_MX:CHERRY_PCB_100H | ~
 |  | SW39 | E | Switch:SW_Push_45deg | Cherry_MX:CHERRY_PCB_100H | ~
 |  | SW40 | R | Switch:SW_Push_45deg | Cherry_MX:CHERRY_PCB_100H | ~
 |  | SW41 | T | Switch:SW_Push_45deg | Cherry_MX:CHERRY_PCB_100H | ~
 |  | SW42 | CTRL | Switch:SW_Push_45deg | Button_Switch_Keyboard:SW_Cherry_MX_1.25u_PCB | ~
 |  | SW43 | 1 | Switch:SW_Push_45deg | Cherry_MX:CHERRY_PCB_100H | ~
 |  | SW44 | 2 | Switch:SW_Push_45deg | Cherry_MX:CHERRY_PCB_100H | ~
 |  | SW45 | 3 | Switch:SW_Push_45deg | Cherry_MX:CHERRY_PCB_100H | ~
 |  | SW46 | 4 | Switch:SW_Push_45deg | Cherry_MX:CHERRY_PCB_100H | ~
 |  | SW47 | 5 | Switch:SW_Push_45deg | Cherry_MX:CHERRY_PCB_100H | ~
 |  | SW48 | FNCT | Switch:SW_Push_45deg | Button_Switch_Keyboard:SW_Cherry_MX_1.25u_PCB | ~
 |  | U1 | ATtiny13A-P | MCU_Microchip_ATtiny:ATtiny13A-P | Package_DIP:DIP-8_W7.62mm_LongPads | http://ww1.microchip.com/downloads/en/DeviceDoc/doc8126.pdf
 |  | U2 | 74LS125 | 74xx:74LS125 | Package_DIP:DIP-14_W7.62mm_Socket_LongPads | http://www.ti.com/lit/gpn/sn74LS125
Collated Components:
Item | Qty | Reference(s) | Value | LibPart | Footprint | Datasheet
1 | 1 | C1 | 0.1µF | Device:C | Capacitor_THT:C_Disc_D7.0mm_W2.5mm_P5.00mm | ~
2 | 1 | D1 | Alpha | Device:LED | LED_THT:LED_D3.0mm | ~
3 | 1 | D2 | Power | Device:LED | LED_THT:LED_D3.0mm | ~
4 | 6 | H1, H2, H3, H4, H5, H6 | MountingHole | Mechanical:MountingHole | MountingHole:MountingHole_3.2mm_M3_Pad | ~
5 | 1 | J1 | Computer | Connector_Generic:Conn_01x18 | Connector_PinHeader_2.54mm:PinHeader_1x18_P2.54mm_Vertical | ~
6 | 2 | R1, R2 | 470Ω | Device:R | Resistor_THT:R_Axial_DIN0207_L6.3mm_D2.5mm_P7.62mm_Horizontal | ~
7 | 1 | R3 | 1KΩ | Device:R | Resistor_THT:R_Axial_DIN0207_L6.3mm_D2.5mm_P7.62mm_Horizontal | ~
8 | 1 | SW1 | SLASH | Switch:SW_Push_45deg | Cherry_MX:CHERRY_PCB_100H | ~
9 | 1 | SW2 | PERIOD | Switch:SW_Push_45deg | Cherry_MX:CHERRY_PCB_100H | ~
10 | 1 | SW3 | COMMA | Switch:SW_Push_45deg | Cherry_MX:CHERRY_PCB_100H | ~
11 | 1 | SW4 | M | Switch:SW_Push_45deg | Cherry_MX:CHERRY_PCB_100H | ~
12 | 1 | SW5 | N | Switch:SW_Push_45deg | Cherry_MX:CHERRY_PCB_100H | ~
13 | 1 | SW6 | EQUALS | Switch:SW_Push_45deg | Cherry_MX:CHERRY_PCB_100H | ~
14 | 1 | SW7 | COLON | Switch:SW_Push_45deg | Cherry_MX:CHERRY_PCB_100H | ~
15 | 1 | SW8 | L | Switch:SW_Push_45deg | Cherry_MX:CHERRY_PCB_100H | ~
16 | 1 | SW9 | K | Switch:SW_Push_45deg | Cherry_MX:CHERRY_PCB_100H | ~
17 | 1 | SW10 | J | Switch:SW_Push_45deg | Cherry_MX:CHERRY_PCB_100H | ~
18 | 1 | SW11 | H | Switch:SW_Push_45deg | Cherry_MX:CHERRY_PCB_100H | ~
19 | 1 | SW12 | SPACE | Switch:SW_Push_45deg | Cherry_MX:CHERRY_PCB_625H | ~
20 | 1 | SW13 | P | Switch:SW_Push_45deg | Cherry_MX:CHERRY_PCB_100H | ~
21 | 1 | SW14 | O | Switch:SW_Push_45deg | Cherry_MX:CHERRY_PCB_100H | ~
22 | 1 | SW15 | I | Switch:SW_Push_45deg | Cherry_MX:CHERRY_PCB_100H | ~
23 | 1 | SW16 | U | Switch:SW_Push_45deg | Cherry_MX:CHERRY_PCB_100H | ~
24 | 1 | SW17 | Y | Switch:SW_Push_45deg | Cherry_MX:CHERRY_PCB_100H | ~
25 | 1 | SW18 | ENTER | Switch:SW_Push_45deg | Cherry_MX:CHERRY_PCB_225H | ~
26 | 1 | SW19 | 0 | Switch:SW_Push_45deg | Cherry_MX:CHERRY_PCB_100H | ~
27 | 1 | SW20 | 9 | Switch:SW_Push_45deg | Cherry_MX:CHERRY_PCB_100H | ~
28 | 1 | SW21 | 8 | Switch:SW_Push_45deg | Cherry_MX:CHERRY_PCB_100H | ~
29 | 1 | SW22 | 7 | Switch:SW_Push_45deg | Cherry_MX:CHERRY_PCB_100H | ~
30 | 1 | SW23 | 6 | Switch:SW_Push_45deg | Cherry_MX:CHERRY_PCB_100H | ~
31 | 1 | SW24 | Z | Switch:SW_Push_45deg | Cherry_MX:CHERRY_PCB_100H | ~
32 | 1 | SW25 | X | Switch:SW_Push_45deg | Cherry_MX:CHERRY_PCB_100H | ~
33 | 1 | SW26 | C | Switch:SW_Push_45deg | Cherry_MX:CHERRY_PCB_100H | ~
34 | 1 | SW27 | V | Switch:SW_Push_45deg | Cherry_MX:CHERRY_PCB_100H | ~
35 | 1 | SW28 | B | Switch:SW_Push_45deg | Cherry_MX:CHERRY_PCB_100H | ~
36 | 1 | SW29 | LOCK | Switch:SW_Push_45deg | Button_Switch_Keyboard:SW_Cherry_MX_1.75u_PCB | ~
37 | 1 | SW30 | A | Switch:SW_Push_45deg | Cherry_MX:CHERRY_PCB_100H | ~
38 | 1 | SW31 | S | Switch:SW_Push_45deg | Cherry_MX:CHERRY_PCB_100H | ~
39 | 1 | SW32 | D | Switch:SW_Push_45deg | Cherry_MX:CHERRY_PCB_100H | ~
40 | 1 | SW33 | F | Switch:SW_Push_45deg | Cherry_MX:CHERRY_PCB_100H | ~
41 | 1 | SW34 | G | Switch:SW_Push_45deg | Cherry_MX:CHERRY_PCB_100H | ~
42 | 1 | SW35 | SHIFT | Switch:SW_Push_45deg | Cherry_MX:CHERRY_PCB_275H | ~
43 | 1 | SW36 | SHIFT | Switch:SW_Push_45deg | Cherry_MX:CHERRY_PCB_225H | ~
44 | 1 | SW37 | Q | Switch:SW_Push_45deg | Cherry_MX:CHERRY_PCB_100H | ~
45 | 1 | SW38 | W | Switch:SW_Push_45deg | Cherry_MX:CHERRY_PCB_100H | ~
46 | 1 | SW39 | E | Switch:SW_Push_45deg | Cherry_MX:CHERRY_PCB_100H | ~
47 | 1 | SW40 | R | Switch:SW_Push_45deg | Cherry_MX:CHERRY_PCB_100H | ~
48 | 1 | SW41 | T | Switch:SW_Push_45deg | Cherry_MX:CHERRY_PCB_100H | ~
49 | 1 | SW42 | CTRL | Switch:SW_Push_45deg | Button_Switch_Keyboard:SW_Cherry_MX_1.25u_PCB | ~
50 | 1 | SW43 | 1 | Switch:SW_Push_45deg | Cherry_MX:CHERRY_PCB_100H | ~
51 | 1 | SW44 | 2 | Switch:SW_Push_45deg | Cherry_MX:CHERRY_PCB_100H | ~
52 | 1 | SW45 | 3 | Switch:SW_Push_45deg | Cherry_MX:CHERRY_PCB_100H | ~
53 | 1 | SW46 | 4 | Switch:SW_Push_45deg | Cherry_MX:CHERRY_PCB_100H | ~
54 | 1 | SW47 | 5 | Switch:SW_Push_45deg | Cherry_MX:CHERRY_PCB_100H | ~
55 | 1 | SW48 | FNCT | Switch:SW_Push_45deg | Button_Switch_Keyboard:SW_Cherry_MX_1.25u_PCB | ~
56 | 1 | U1 | ATtiny13A-P | MCU_Microchip_ATtiny:ATtiny13A-P | Package_DIP:DIP-8_W7.62mm_LongPads | http://ww1.microchip.com/downloads/en/DeviceDoc/doc8126.pdf
57 | 1 | U2 | 74LS125 | 74xx:74LS125 | Package_DIP:DIP-14_W7.62mm_Socket_LongPads | http://www.ti.com/lit/gpn/sn74LS125

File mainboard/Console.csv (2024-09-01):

Source: | N:\Vintage\Projects\TI99_22\mainboard\Console.kicad_sch
Date: | 4/13/2024 9:06
Tool: | Eeschema (6.0.11)
Generator: | C:\Program Files\KiCad\6.0\bin\scripting\plugins/bom_csv_grouped_by_value.py
Component Count: | 251
Individual Components:
Item | Qty | Reference(s) | Value | LibPart | Footprint | Datasheet
 |  | C1 | 0.001uf | Device:C | Capacitor_THT:C_Rect_L7.0mm_W2.0mm_P5.00mm | ~
 |  | C2 | 22pF | Device:C | Capacitor_THT:C_Rect_L7.0mm_W2.0mm_P5.00mm | ~
 |  | C3 | 22uf | Device:C_Polarized | Capacitor_THT:CP_Radial_D7.5mm_P2.50mm | ~
 |  | C4 | 0.1uf | Device:C | Capacitor_THT:C_Rect_L7.0mm_W2.0mm_P5.00mm | ~
 |  | C5 | 22uf | Device:C_Polarized | Capacitor_THT:CP_Radial_D7.5mm_P2.50mm | ~
 |  | C6 | 1uf | Device:C | Capacitor_THT:C_Rect_L7.0mm_W2.0mm_P5.00mm | ~
 |  | C7 | 0.1uf | Device:C | Capacitor_THT:C_Rect_L7.0mm_W2.0mm_P5.00mm | ~
 |  | C8 | 0.01uf | Device:C | Capacitor_THT:C_Rect_L7.0mm_W2.0mm_P5.00mm | ~
 |  | C9 | 0.001uf | Device:C | Capacitor_THT:C_Rect_L7.0mm_W2.0mm_P5.00mm | ~
 |  | C10 | 100uf | Device:C_Polarized_Small | Capacitor_THT:CP_Radial_D7.5mm_P2.50mm | ~
 |  | C11 | 0.001uf | Device:C | Capacitor_THT:C_Rect_L7.0mm_W2.0mm_P5.00mm | ~
 |  | C12 | 0.01uf | Device:C_Small | Capacitor_THT:C_Rect_L7.0mm_W2.0mm_P5.00mm | ~
 |  | C13 | 0.1uf | Device:C | Capacitor_THT:C_Rect_L7.0mm_W2.0mm_P5.00mm | ~
 |  | C14 | 0.1uf | Device:C | Capacitor_THT:C_Rect_L7.0mm_W2.0mm_P5.00mm | ~
 |  | C15 | 100uf | Device:C_Polarized | Capacitor_THT:CP_Radial_D7.5mm_P2.50mm | ~
 |  | C16 | 100uf | Device:C_Polarized | Capacitor_THT:CP_Radial_D7.5mm_P2.50mm | ~
 |  | C17 | 100uf | Device:C_Polarized | Capacitor_THT:CP_Radial_D7.5mm_P2.50mm | ~
 |  | C18 | 0.1uf | Device:C_Small | Capacitor_THT:C_Rect_L7.0mm_W2.0mm_P5.00mm | ~
 |  | C19 | 100uf | Device:C_Polarized | Capacitor_THT:CP_Radial_D7.5mm_P2.50mm | ~
 |  | C20 | 0.1uf | Device:C | Capacitor_THT:C_Rect_L7.0mm_W2.0mm_P5.00mm | ~
 |  | C21 | 100uf | Device:C_Polarized | Capacitor_THT:CP_Radial_D7.5mm_P2.50mm | ~
 |  | C22 | 100uf | Device:C_Polarized | Capacitor_THT:CP_Radial_D7.5mm_P2.50mm | ~
 |  | C23 | 0.1uf | Device:C_Small | Capacitor_THT:C_Rect_L7.0mm_W2.0mm_P5.00mm | ~
 |  | C24 | 0.1uf | Device:C_Small | Capacitor_THT:C_Rect_L7.0mm_W2.0mm_P5.00mm | ~
 |  | C25 | 0.1uf | Device:C_Small | Capacitor_THT:C_Rect_L7.0mm_W2.0mm_P5.00mm | ~
 |  | C26 | 0.1uf | Device:C_Small | Capacitor_THT:C_Rect_L7.0mm_W2.0mm_P5.00mm | ~
 |  | C27 | 0.1uf | Device:C_Small | Capacitor_THT:C_Rect_L7.0mm_W2.0mm_P5.00mm | ~
 |  | C28 | 0.1uf | Device:C_Small | Capacitor_THT:C_Rect_L7.0mm_W2.0mm_P5.00mm | ~
 |  | C29 | 0.1uf | Device:C_Small | Capacitor_THT:C_Rect_L7.0mm_W2.0mm_P5.00mm | ~
 |  | C30 | 0.1uf | Device:C_Small | Capacitor_THT:C_Rect_L7.0mm_W2.0mm_P5.00mm | ~
 |  | C31 | 0.1uf | Device:C_Small | Capacitor_THT:C_Rect_L7.0mm_W2.0mm_P5.00mm | ~
 |  | C32 | 0.1uf | Device:C_Small | Capacitor_THT:C_Rect_L7.0mm_W2.0mm_P5.00mm | ~
 |  | C33 | 0.1uf | Device:C_Small | Capacitor_THT:C_Rect_L7.0mm_W2.0mm_P5.00mm | ~
 |  | C34 | 0.1uf | Device:C_Small | Capacitor_THT:C_Rect_L7.0mm_W2.0mm_P5.00mm | ~
 |  | C35 | 0.1uf | Device:C_Small | Capacitor_THT:C_Rect_L7.0mm_W2.0mm_P5.00mm | ~
 |  | C36 | 0.1uf | Device:C_Small | Capacitor_THT:C_Rect_L7.0mm_W2.0mm_P5.00mm | ~
 |  | C37 | 0.1uf | Device:C_Small | Capacitor_THT:C_Rect_L7.0mm_W2.0mm_P5.00mm | ~
 |  | C38 | 0.1uf | Device:C_Small | Capacitor_THT:C_Rect_L7.0mm_W2.0mm_P5.00mm | ~
 |  | C39 | 0.1uf | Device:C_Small | Capacitor_THT:C_Rect_L7.0mm_W2.0mm_P5.00mm | ~
 |  | C40 | 0.1uf | Device:C_Small | Capacitor_THT:C_Rect_L7.0mm_W2.0mm_P5.00mm | ~
 |  | C41 | 0.1uf | Device:C_Small | Capacitor_THT:C_Rect_L7.0mm_W2.0mm_P5.00mm | ~
 |  | C42 | 0.1uf | Device:C_Small | Capacitor_THT:C_Rect_L7.0mm_W2.0mm_P5.00mm | ~
 |  | C43 | 0.1uf | Device:C_Small | Capacitor_THT:C_Rect_L7.0mm_W2.0mm_P5.00mm | ~
 |  | C44 | 0.1uf | Device:C_Small | Capacitor_THT:C_Rect_L7.0mm_W2.0mm_P5.00mm | ~
 |  | C45 | 0.1uf | Device:C_Small | Capacitor_THT:C_Rect_L7.0mm_W2.0mm_P5.00mm | ~
 |  | C46 | 0.1uf | Device:C_Small | Capacitor_THT:C_Rect_L7.0mm_W2.0mm_P5.00mm | ~
 |  | C47 | 0.1uf | Device:C_Small | Capacitor_THT:C_Rect_L7.0mm_W2.0mm_P5.00mm | ~
 |  | C48 | 0.1uf | Device:C_Small | Capacitor_THT:C_Rect_L7.0mm_W2.0mm_P5.00mm | ~
 |  | C49 | 0.1uf | Device:C_Small | Capacitor_THT:C_Rect_L7.0mm_W2.0mm_P5.00mm | ~
 |  | C50 | 0.1uf | Device:C_Small | Capacitor_THT:C_Rect_L7.0mm_W2.0mm_P5.00mm | ~
 |  | C51 | 0.1uf | Device:C_Small | Capacitor_THT:C_Rect_L7.0mm_W2.0mm_P5.00mm | ~
 |  | C52 | 0.01uf | Device:C | Capacitor_THT:C_Rect_L7.0mm_W2.0mm_P5.00mm | ~
 |  | C53 | 100uf | Device:C_Polarized_Small | Capacitor_THT:CP_Radial_D5.0mm_P2.00mm | ~
 |  | C54 | 0.1uf | Device:C | Capacitor_THT:C_Rect_L7.0mm_W2.0mm_P5.00mm | ~
 |  | C55 | 0.1uf | Device:C | Capacitor_THT:C_Rect_L7.0mm_W2.0mm_P5.00mm | ~
 |  | C56 | 12pF | Device:C | Capacitor_THT:C_Rect_L7.0mm_W2.0mm_P5.00mm | ~
 |  | C57 | 56pF | Device:C | Capacitor_THT:C_Rect_L7.0mm_W2.0mm_P5.00mm | ~
 |  | C58 | 0.001uf | Device:C | Capacitor_THT:C_Rect_L7.0mm_W2.0mm_P5.00mm | ~
 |  | C59 | 22uf | Device:C_Polarized | Capacitor_THT:CP_Radial_D7.5mm_P2.50mm | ~
 |  | C60 | 100uf | Device:C_Polarized | Capacitor_THT:CP_Radial_D7.5mm_P2.50mm | ~
 |  | C61 | 220uf | Device:C_Polarized | Capacitor_THT:CP_Radial_D7.5mm_P2.50mm | ~
 |  | C62 | 0.1uf | Device:C | Capacitor_THT:C_Rect_L7.0mm_W2.0mm_P5.00mm | ~
 |  | C63 | 0.01uf | Device:C | Capacitor_THT:C_Rect_L7.0mm_W2.0mm_P5.00mm | ~
 |  | C64 | 0.1uf | Device:C | Capacitor_THT:C_Rect_L7.0mm_W2.0mm_P5.00mm | ~
 |  | C65 | 0.01uf | Device:C | Capacitor_THT:C_Rect_L7.0mm_W2.0mm_P5.00mm | ~
 |  | C66 | 0.01uf | Device:C | Capacitor_THT:C_Rect_L7.0mm_W2.0mm_P5.00mm | ~
 |  | C67 | 0.01uf | Device:C | Capacitor_THT:C_Rect_L7.0mm_W2.0mm_P5.00mm | ~
 |  | C68 | 0.1uf | Device:C | Capacitor_THT:C_Rect_L7.0mm_W2.0mm_P5.00mm | ~
 |  | C69 | 220pF | Device:C | Capacitor_THT:C_Rect_L7.0mm_W2.0mm_P5.00mm | ~
 |  | C70 | 0.022uf | Device:C | Capacitor_THT:C_Rect_L7.0mm_W2.0mm_P5.00mm | ~
 |  | C71 | 0.1uf | Device:C | Capacitor_THT:C_Rect_L7.0mm_W2.0mm_P5.00mm | ~
 |  | C72 | 0.01uf | Device:C | Capacitor_THT:C_Rect_L7.0mm_W2.0mm_P5.00mm | ~
 |  | C73 | 0.001uf | Device:C | Capacitor_THT:C_Rect_L7.0mm_W2.0mm_P5.00mm | ~
 |  | C74 | 0.1uf | Device:C | Capacitor_THT:C_Rect_L7.0mm_W2.0mm_P5.00mm | ~
 |  | C75 | 0.001uf | Device:C | Capacitor_THT:C_Rect_L7.0mm_W2.0mm_P5.00mm | ~
 |  | CR1 | 1N4148 | Device:D | Diode_THT:D_A-405_P7.62mm_Horizontal | ~
 |  | CR2 | 1N914B | Device:D | Diode_THT:D_A-405_P7.62mm_Horizontal | ~
 |  | CR3 | 1N914B | Device:D | Diode_THT:D_A-405_P7.62mm_Horizontal | ~
 |  | CR4 | 1N4148 | Device:D | Diode_THT:D_A-405_P7.62mm_Horizontal | ~
 |  | D1 | LED | Device:LED | LED_THT:LED_D5.0mm | ~
 |  | H1 | MountingHole | Mechanical:MountingHole | MountingHole:MountingHole_3.2mm_M3 | ~
 |  | H2 | MountingHole | Mechanical:MountingHole | MountingHole:MountingHole_3.2mm_M3 | ~
 |  | H3 | MountingHole | Mechanical:MountingHole | MountingHole:MountingHole_3.2mm_M3 | ~
 |  | H4 | MountingHole | Mechanical:MountingHole | MountingHole:MountingHole_3.2mm_M3 | ~
 |  | H5 | MountingHole | Mechanical:MountingHole | MountingHole:MountingHole_3.2mm_M3 | ~
 |  | H6 | MountingHole | Mechanical:MountingHole | MountingHole:MountingHole_3.2mm_M3 | ~
 |  | H7 | MountingHole | Mechanical:MountingHole | MountingHole:MountingHole_3.2mm_M3 | ~
 |  | J1 | Reset | Connector:Conn_01x02_Male | Connector_PinHeader_2.54mm:PinHeader_1x02_P2.54mm_Vertical | ~
 |  | J2 | Power LED | Connector:Conn_01x02_Male | Connector_PinHeader_2.54mm:PinHeader_1x02_P2.54mm_Vertical | ~
 |  | J3 | POWER | Connector:Screw_Terminal_01x04 | TerminalBlock_RND:TerminalBlock_RND_205-00278_1x04_P5.00mm_Vertical | ~
 |  | J4 | UNICORN PORT | Connector:Conn_01x16_Male | Connector_PinHeader_2.54mm:PinHeader_1x16_P2.54mm_Vertical | ~
 |  | J5 | ROM Select | Connector:Conn_01x03_Male | Connector_PinHeader_2.54mm:PinHeader_1x03_P2.54mm_Vertical | ~
 |  | J6 | ROM Select | Connector:Conn_01x03_Male | Connector_PinHeader_2.54mm:PinHeader_1x03_P2.54mm_Vertical | ~
 |  | J7 | Sound Clock Select | Connector:Conn_01x03_Male | Connector_PinHeader_2.54mm:PinHeader_1x03_P2.54mm_Vertical | ~
 |  | J8 | AUDIO OUT | Connector:Conn_01x02_Male | Connector_PinHeader_2.54mm:PinHeader_1x02_P2.54mm_Vertical | ~
 |  | J9 | VIDEO OUT | Connector:Conn_01x02_Male | Connector_PinHeader_2.54mm:PinHeader_1x02_P2.54mm_Vertical | ~
 |  | J10 | Joystick | Connector:DB9_Male_MountingHoles | Connector_Dsub:DSUB-9_Male_Horizontal_P2.77x2.84mm_EdgePinOffset4.94mm_Housed_MountingHolesOffset7.48mm | ~
 |  | J11 | Keyboard | Connector_Generic:Conn_01x18 | Connector_PinHeader_2.54mm:PinHeader_1x18_P2.54mm_Vertical | ~
 |  | J12 | I/O Port | Connector_Generic:Conn_02x22_Odd_Even | Connector_PinHeader_2.54mm:PinHeader_2x22_P2.54mm_Vertical | ~
 |  | J13 | I/O Port | Connector_Generic:Conn_02x22_Odd_Even | WernerCustomLibrary:44 Pin Card Edge | ~
 |  | J14 | GROM Port | Connector_Generic:Conn_02x18_Odd_Even | Library:CardEdge_34Pin_2.54mm_Vertical | ~
 |  | J15 | GROM Port | Connector_Generic:Conn_02x18_Odd_Even | Connector_PinHeader_2.54mm:PinHeader_2x18_P2.54mm_Vertical | ~
 |  | J16 | Rom Select 1 | Connector:Conn_01x03_Male | Connector_PinSocket_2.54mm:PinSocket_1x03_P2.54mm_Vertical | ~
 |  | J17 | Rom Select 2 | Connector:Conn_01x03_Male | Connector_PinSocket_2.54mm:PinSocket_1x03_P2.54mm_Vertical | ~
 |  | J18 | Cassette | Connector:DB9_Male_MountingHoles | Connector_Dsub:DSUB-9_Male_Horizontal_P2.77x2.84mm_EdgePinOffset4.94mm_Housed_MountingHolesOffset7.48mm | ~
 |  | L1 | 0.33uH | Device:L_Small | Resistor_THT:R_Axial_DIN0207_L6.3mm_D2.5mm_P15.24mm_Horizontal | ~
 |  | L4 | 6.8uH | Device:L | Resistor_THT:R_Axial_DIN0207_L6.3mm_D2.5mm_P15.24mm_Horizontal | ~
 |  | L5 | 6.8uH | Device:L | Resistor_THT:R_Axial_DIN0207_L6.3mm_D2.5mm_P15.24mm_Horizontal | ~
 |  | L7 | 5.8uH | Device:L | Resistor_THT:R_Axial_DIN0207_L6.3mm_D2.5mm_P15.24mm_Horizontal | ~
 |  | L8 | INDUCTOR (BEAD) | Device:L_Ferrite | Resistor_THT:R_Axial_DIN0207_L6.3mm_D2.5mm_P10.16mm_Horizontal | ~
 |  | L10 | 8.2uH | Device:L_Small | Resistor_THT:R_Axial_DIN0207_L6.3mm_D2.5mm_P15.24mm_Horizontal | ~
 |  | L11 | 8.2uH | Device:L_Small | Resistor_THT:R_Axial_DIN0207_L6.3mm_D2.5mm_P15.24mm_Horizontal | ~
 |  | L12 | 8.2uH | Device:L_Small | Resistor_THT:R_Axial_DIN0207_L6.3mm_D2.5mm_P15.24mm_Horizontal | ~
 |  | L13 | 8.2uH | Device:L_Small | Resistor_THT:R_Axial_DIN0207_L6.3mm_D2.5mm_P15.24mm_Horizontal | ~
 |  | L14 | 8.2uH | Device:L_Small | Resistor_THT:R_Axial_DIN0207_L6.3mm_D2.5mm_P15.24mm_Horizontal | ~
 |  | L15 | 8.2uH | Device:L_Small | Resistor_THT:R_Axial_DIN0207_L6.3mm_D2.5mm_P15.24mm_Horizontal | ~
 |  | L16 | 8.2uH | Device:L_Small | Resistor_THT:R_Axial_DIN0207_L6.3mm_D2.5mm_P15.24mm_Horizontal | ~
 |  | Q1 | TIS92 | Device:Q_NPN_EBC | Package_TO_SOT_THT:TO-92_HandSolder | ~
 |  | Q2 | 2N3904 | Device:Q_NPN_EBC | Package_TO_SOT_THT:TO-92L_HandSolder | ~
 |  | Q3 | TIS92 | Device:Q_NPN_EBC | Package_TO_SOT_THT:TO-92_HandSolder | ~
 |  | Q4 | TIS92 | Device:Q_NPN_EBC | Package_TO_SOT_THT:TO-92_HandSolder | ~
 |  | R1 | 150k | Device:R | Resistor_THT:R_Axial_DIN0207_L6.3mm_D2.5mm_P7.62mm_Horizontal | ~
 |  | R2 | 1k | Device:R | Resistor_THT:R_Axial_DIN0207_L6.3mm_D2.5mm_P7.62mm_Horizontal | ~
 |  | R3 | 12k | Device:R | Resistor_THT:R_Axial_DIN0207_L6.3mm_D2.5mm_P7.62mm_Horizontal | ~
 |  | R4 | 47k | Device:R | Resistor_THT:R_Axial_DIN0207_L6.3mm_D2.5mm_P7.62mm_Horizontal | ~
 |  | R5 | 22 | Device:R | Resistor_THT:R_Axial_DIN0207_L6.3mm_D2.5mm_P7.62mm_Horizontal | ~
 |  | R6 | 22 | Device:R | Resistor_THT:R_Axial_DIN0207_L6.3mm_D2.5mm_P7.62mm_Horizontal | ~
 |  | R7 | 22 | Device:R | Resistor_THT:R_Axial_DIN0207_L6.3mm_D2.5mm_P7.62mm_Horizontal | ~
 |  | R8 | 22 | Device:R | Resistor_THT:R_Axial_DIN0207_L6.3mm_D2.5mm_P7.62mm_Horizontal | ~
 |  | R9 | 1k | Device:R | Resistor_THT:R_Axial_DIN0207_L6.3mm_D2.5mm_P7.62mm_Horizontal | ~
 |  | R10 | 4.7k | Device:R | Resistor_THT:R_Axial_DIN0207_L6.3mm_D2.5mm_P7.62mm_Horizontal | ~
 |  | R11 | 1k | Device:R | Resistor_THT:R_Axial_DIN0207_L6.3mm_D2.5mm_P7.62mm_Horizontal | ~
 |  | R12 | 1K | Device:R | Resistor_THT:R_Axial_DIN0207_L6.3mm_D2.5mm_P7.62mm_Horizontal | ~
 |  | R13 | 1K | Device:R | Resistor_THT:R_Axial_DIN0207_L6.3mm_D2.5mm_P7.62mm_Horizontal | ~
 |  | R14 | 1K | Device:R | Resistor_THT:R_Axial_DIN0207_L6.3mm_D2.5mm_P7.62mm_Horizontal | ~
 |  | R15 | 1K | Device:R | Resistor_THT:R_Axial_DIN0207_L6.3mm_D2.5mm_P7.62mm_Horizontal | ~
 |  | R16 | 1K | Device:R | Resistor_THT:R_Axial_DIN0207_L6.3mm_D2.5mm_P7.62mm_Horizontal | ~
 |  | R17 | 2.2k | Device:R | Resistor_THT:R_Axial_DIN0207_L6.3mm_D2.5mm_P7.62mm_Horizontal | ~
 |  | R18 | 1k | Device:R | Resistor_THT:R_Axial_DIN0207_L6.3mm_D2.5mm_P7.62mm_Horizontal | ~
 |  | R19 | 470 | Device:R | Resistor_THT:R_Axial_DIN0207_L6.3mm_D2.5mm_P7.62mm_Horizontal | ~
 |  | R20 | 270 | Device:R | Resistor_THT:R_Axial_DIN0207_L6.3mm_D2.5mm_P7.62mm_Horizontal | ~
 |  | R21 | 1.5k | Device:R_Network09 | Resistor_THT:R_Array_SIP10 | http://www.vishay.com/docs/31509/csc.pdf
 |  | R22 | 361 | Device:R_Small | Resistor_THT:R_Axial_DIN0207_L6.3mm_D2.5mm_P7.62mm_Horizontal | ~
 |  | R23 | 5.6k | Device:R_Small | Resistor_THT:R_Axial_DIN0207_L6.3mm_D2.5mm_P7.62mm_Horizontal | ~
 |  | R24 | 10 | Device:R_Small | Resistor_THT:R_Axial_DIN0207_L6.3mm_D2.5mm_P7.62mm_Horizontal | ~
 |  | R25 | 150 | Device:R_Small | Resistor_THT:R_Axial_DIN0207_L6.3mm_D2.5mm_P7.62mm_Horizontal | ~
 |  | R26 | 4.7k | Device:R | Resistor_THT:R_Axial_DIN0207_L6.3mm_D2.5mm_P7.62mm_Horizontal | ~
 |  | R27 | 10 | Device:R_Small | Resistor_THT:R_Axial_DIN0207_L6.3mm_D2.5mm_P7.62mm_Horizontal | ~
 |  | R28 | 470k | Device:R | Resistor_THT:R_Axial_DIN0207_L6.3mm_D2.5mm_P7.62mm_Horizontal | ~
 |  | R29 | 0 | Device:R | Resistor_THT:R_Axial_DIN0207_L6.3mm_D2.5mm_P7.62mm_Horizontal | ~
 |  | R30 | 470 | Device:R | Resistor_THT:R_Axial_DIN0207_L6.3mm_D2.5mm_P7.62mm_Horizontal | ~
 |  | R31 | 75 | Device:R | Resistor_THT:R_Axial_DIN0207_L6.3mm_D2.5mm_P7.62mm_Horizontal | ~
 |  | R32 | 470 | Device:R_Small | Resistor_THT:R_Axial_DIN0207_L6.3mm_D2.5mm_P7.62mm_Horizontal | ~
 |  | R33 | 75 | Device:R | Resistor_THT:R_Axial_DIN0207_L6.3mm_D2.5mm_P7.62mm_Horizontal | ~
 |  | R34 | 1k | Device:R | Resistor_THT:R_Axial_DIN0207_L6.3mm_D2.5mm_P7.62mm_Horizontal | ~
 |  | R35 | 1k | Device:R | Resistor_THT:R_Axial_DIN0207_L6.3mm_D2.5mm_P7.62mm_Horizontal | ~
 |  | R36 | 100 | Device:R | Resistor_THT:R_Axial_DIN0207_L6.3mm_D2.5mm_P7.62mm_Horizontal | ~
 |  | R37 | 100 | Device:R | Resistor_THT:R_Axial_DIN0207_L6.3mm_D2.5mm_P7.62mm_Horizontal | ~
 |  | R38 | 100 | Device:R | Resistor_THT:R_Axial_DIN0207_L6.3mm_D2.5mm_P7.62mm_Horizontal | ~
 |  | R39 | 100 | Device:R | Resistor_THT:R_Axial_DIN0207_L6.3mm_D2.5mm_P7.62mm_Horizontal | ~
 |  | R40 | 100 | Device:R | Resistor_THT:R_Axial_DIN0207_L6.3mm_D2.5mm_P7.62mm_Horizontal | ~
 |  | R41 | 62 | Device:R | Resistor_THT:R_Axial_DIN0207_L6.3mm_D2.5mm_P7.62mm_Horizontal | ~
 |  | R42 | 62 | Device:R | Resistor_THT:R_Axial_DIN0207_L6.3mm_D2.5mm_P7.62mm_Horizontal | ~
 |  | R43 | 62 | Device:R | Resistor_THT:R_Axial_DIN0207_L6.3mm_D2.5mm_P7.62mm_Horizontal | ~
 |  | R44 | 62 | Device:R | Resistor_THT:R_Axial_DIN0207_L6.3mm_D2.5mm_P7.62mm_Horizontal | ~
 |  | R45 | 4.7k | Device:R | Resistor_THT:R_Axial_DIN0207_L6.3mm_D2.5mm_P7.62mm_Horizontal | ~
 |  | R46 | 1k | Device:R | Resistor_THT:R_Axial_DIN0207_L6.3mm_D2.5mm_P7.62mm_Horizontal | ~
 |  | R47 | 3.3k | Device:R | Resistor_THT:R_Axial_DIN0207_L6.3mm_D2.5mm_P7.62mm_Horizontal | ~
 |  | R48 | 2.2k | Device:R | Resistor_THT:R_Axial_DIN0207_L6.3mm_D2.5mm_P7.62mm_Horizontal | ~
 |  | R49 | 100 | Device:R | Resistor_THT:R_Axial_DIN0207_L6.3mm_D2.5mm_P7.62mm_Horizontal | ~
 |  | R50 | 2.2k | Device:R | Resistor_THT:R_Axial_DIN0207_L6.3mm_D2.5mm_P7.62mm_Horizontal | ~
 |  | R51 | 100 | Device:R | Resistor_THT:R_Axial_DIN0207_L6.3mm_D2.5mm_P7.62mm_Horizontal | ~
 |  | R52 | 4.7k | Device:R | Resistor_THT:R_Axial_DIN0207_L6.3mm_D2.5mm_P7.62mm_Horizontal | ~
 |  | R53 | 4.7k | Device:R | Resistor_THT:R_Axial_DIN0207_L6.3mm_D2.5mm_P7.62mm_Horizontal | ~
 |  | R54 | 100 | Device:R | Resistor_THT:R_Axial_DIN0207_L6.3mm_D2.5mm_P7.62mm_Horizontal | ~
 |  | R55 | 330 | Device:R | Resistor_THT:R_Axial_DIN0207_L6.3mm_D2.5mm_P7.62mm_Horizontal | ~
 |  | R56 | 100 | Device:R | Resistor_THT:R_Axial_DIN0207_L6.3mm_D2.5mm_P7.62mm_Horizontal | ~
 |  | R57 | 10k | Device:R | Resistor_THT:R_Axial_DIN0207_L6.3mm_D2.5mm_P7.62mm_Horizontal | ~
 |  | R58 | 6.8k | Device:R_Small | Resistor_THT:R_Axial_DIN0207_L6.3mm_D2.5mm_P7.62mm_Horizontal | ~
 |  | R59 | 39k | Device:R_Small | Resistor_THT:R_Axial_DIN0207_L6.3mm_D2.5mm_P7.62mm_Horizontal | ~
 |  | R60 | 6.8k | Device:R | Resistor_THT:R_Axial_DIN0207_L6.3mm_D2.5mm_P7.62mm_Horizontal | ~
 |  | R61 | 1K | Device:R_Small | Resistor_THT:R_Axial_DIN0207_L6.3mm_D2.5mm_P7.62mm_Horizontal | ~
 |  | R62 | 1K | Device:R_Small | Resistor_THT:R_Axial_DIN0207_L6.3mm_D2.5mm_P7.62mm_Horizontal | ~
 |  | R63 | 120k | Device:R_Small | Resistor_THT:R_Axial_DIN0207_L6.3mm_D2.5mm_P7.62mm_Horizontal | ~
 |  | R64 | 2.7k | Device:R_Small | Resistor_THT:R_Axial_DIN0207_L6.3mm_D2.5mm_P7.62mm_Horizontal | ~
 |  | R65 | 220 | Device:R_Small | Resistor_THT:R_Axial_DIN0207_L6.3mm_D2.5mm_P7.62mm_Horizontal | ~
 |  | R66 | 220 | Device:R_Small | Resistor_THT:R_Axial_DIN0207_L6.3mm_D2.5mm_P7.62mm_Horizontal | ~
 |  | R67 | 1K | Device:R_Small | Resistor_THT:R_Axial_DIN0207_L6.3mm_D2.5mm_P7.62mm_Horizontal | ~
 |  | R68 | 1K | Device:R_Small | Resistor_THT:R_Axial_DIN0207_L6.3mm_D2.5mm_P7.62mm_Horizontal | ~
 |  | R69 | 10K | Device:R_Small | Resistor_THT:R_Axial_DIN0207_L6.3mm_D2.5mm_P7.62mm_Horizontal | ~
 |  | R70 | 9.1k | Device:R_Small | Resistor_THT:R_Axial_DIN0207_L6.3mm_D2.5mm_P7.62mm_Horizontal | ~
 |  | R71 | 10k | Device:R_Small | Resistor_THT:R_Axial_DIN0207_L6.3mm_D2.5mm_P7.62mm_Horizontal | ~
 |  | R72 | 10k | Device:R_Small | Resistor_THT:R_Axial_DIN0207_L6.3mm_D2.5mm_P7.62mm_Horizontal | ~
 |  | R73 | 5.6k | Device:R_Small | Resistor_THT:R_Axial_DIN0207_L6.3mm_D2.5mm_P7.62mm_Horizontal | ~
 |  | R74 | 5.6K | Device:R_Small | Resistor_THT:R_Axial_DIN0207_L6.3mm_D2.5mm_P7.62mm_Horizontal | ~
 |  | R75 | 5.6k | Device:R_Small | Resistor_THT:R_Axial_DIN0207_L6.3mm_D2.5mm_P7.62mm_Horizontal | ~
 |  | R76 | 220 | Device:R_Small | Resistor_THT:R_Axial_DIN0207_L6.3mm_D2.5mm_P7.62mm_Horizontal | ~
 |  | R77 | 15 | Device:R_Small | Resistor_THT:R_Axial_DIN0207_L6.3mm_D2.5mm_P7.62mm_Horizontal | ~
 |  | RN1 | 10K | Device:R_Network09 | Resistor_THT:R_Array_SIP10 | http://www.vishay.com/docs/31509/csc.pdf
 |  | RN2 | 10K | Device:R_Network09 | Resistor_THT:R_Array_SIP10 | http://www.vishay.com/docs/31509/csc.pdf
 |  | SW1 | RAM Size | Switch:SW_DIP_x05 | Package_DIP:DIP-10_W7.62mm_Socket_LongPads | ~
 |  | SW2 | Internal Cart ROM Enable | Switch:SW_DIP_x01 | Connector_PinHeader_2.54mm:PinHeader_1x02_P2.54mm_Vertical | ~
 |  | U1 | TIM9904 | Werner_custom:TIM9904 | Package_DIP:DIP-20_W7.62mm_Socket_LongPads
 |  | U2 | TMS9900 | Werner_custom:TMS9900 | Package_DIP:DIP-64_W22.86mm_Socket_LongPads
 |  | U3 | 74LS04 | 74xx:74LS04 | Package_DIP:DIP-14_W7.62mm_Socket_LongPads | http://www.ti.com/lit/gpn/sn74LS04
 |  | U4 | 74LS32 | 74xx:74LS32 | Package_DIP:DIP-14_W7.62mm_Socket_LongPads | http://www.ti.com/lit/gpn/sn74LS32
 |  | U5 | 74LS138 | 74xx:74LS138 | Package_DIP:DIP-16_W7.62mm_Socket_LongPads | http://www.ti.com/lit/gpn/sn74LS138
 |  | U6 | 74LS03 | 74xx:74LS03 | Package_DIP:DIP-14_W7.62mm_Socket_LongPads | http://www.ti.com/lit/gpn/sn74LS03
 |  | U7 | 74LS08 | 74xx:74LS08 | Package_DIP:DIP-14_W7.62mm_Socket_LongPads | http://www.ti.com/lit/gpn/sn74LS08
 |  | U8 | 74LS138 | 74xx:74LS138 | Package_DIP:DIP-16_W7.62mm_Socket_LongPads | http://www.ti.com/lit/gpn/sn74LS138
 |  | U9 | 74LS32 | 74xx:74LS32 | Package_DIP:DIP-14_W7.62mm_Socket_LongPads | http://www.ti.com/lit/gpn/sn74LS32
 |  | U10 | 74LS00 | 74xx:74LS00 | Package_DIP:DIP-14_W7.62mm_Socket_LongPads | http://www.ti.com/lit/gpn/sn74ls00
 |  | U11 | 74LS244 | 74xx:74LS244 | Package_DIP:DIP-20_W7.62mm_Socket_LongPads | http://www.ti.com/lit/ds/symlink/sn74ls244.pdf
 |  | U12 | 74LS373 | 74xx:74LS373 | Package_DIP:DIP-20_W7.62mm_Socket_LongPads | http://www.ti.com/lit/gpn/sn74LS373
 |  | U13 | 74LS245 | 74xx:74LS245 | Package_DIP:DIP-20_W7.62mm_Socket_LongPads | http://www.ti.com/lit/gpn/sn74LS245
 |  | U14 | 74LS00 | 74xx:74LS00 | Package_DIP:DIP-14_W7.62mm_Socket_LongPads | http://www.ti.com/lit/gpn/sn74ls00
 |  | U15 | 74LS04 | 74xx:74LS04 | Package_DIP:DIP-14_W7.62mm_Socket_LongPads | http://www.ti.com/lit/gpn/sn74LS04
 |  | U16 | 74LS74 | 74xx:74LS74 | Package_DIP:DIP-14_W7.62mm_Socket_LongPads | 74xx/74hc_hct74.pdf
 |  | U17 | 74LS194 | 74xx:74LS194 | Package_DIP:DIP-16_W7.62mm_Socket_LongPads | http://www.ti.com/lit/gpn/sn74LS194
 |  | U18 | 74LS00 | 74xx:74LS00 | Package_DIP:DIP-14_W7.62mm_Socket_LongPads | http://www.ti.com/lit/gpn/sn74ls00
 |  | U19 | LM2901 | Comparator:LM2901 | Package_DIP:DIP-14_W7.62mm_Socket_LongPads | https://www.st.com/resource/en/datasheet/lm2901.pdf
 |  | U20 | LM7905_TO220 | Regulator_Linear:LM7905_TO220 | Package_TO_SOT_THT:TO-220-3_Vertical | https://www.onsemi.com/pub/Collateral/MC7900-D.PDF
 |  | U21 | LM2903 | Comparator:LM2903 | Package_DIP:DIP-8_W7.62mm_Socket_LongPads | http://www.ti.com/lit/ds/symlink/lm393.pdf
 |  | U22 | 74LS04 | 74xx:74LS04 | Package_DIP:DIP-14_W7.62mm_Socket_LongPads | http://www.ti.com/lit/gpn/sn74LS04
 |  | U24 | 74LS04 | 74xx:74LS04 | Package_DIP:DIP-14_W7.62mm_Socket_LongPads | http://www.ti.com/lit/gpn/sn74LS04
 |  | U26 | TMC0430 | Werner_custom:TMC0430 | Package_DIP:DIP-16_W7.62mm_Socket_LongPads
 |  | U27 | TMC0430 | Werner_custom:TMC0430 | Package_DIP:DIP-16_W7.62mm_Socket_LongPads
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

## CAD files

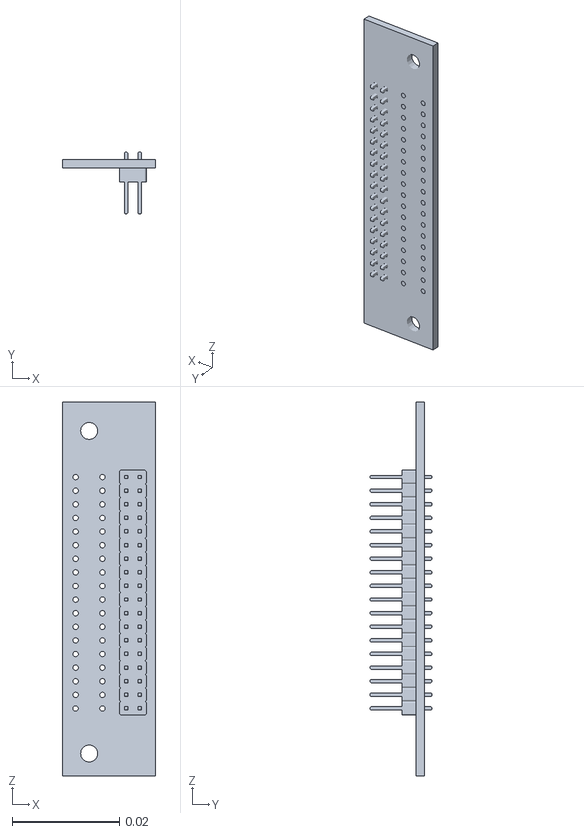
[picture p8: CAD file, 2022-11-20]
CartRiser/CartRiser/Cart_Riser.stl
0.0174 x 0.0115 x 0.0698

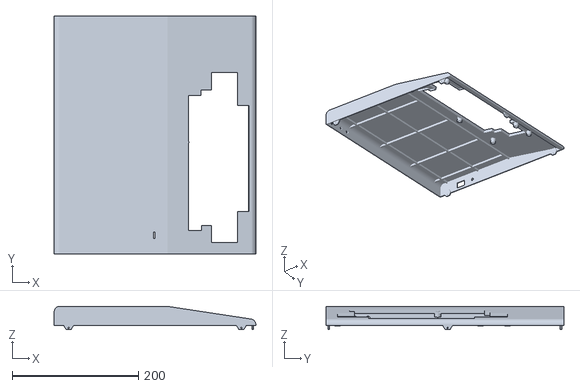
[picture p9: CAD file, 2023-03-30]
Enclosure/TI99Case_top.stl
320.0 x 377.5 x 36.9

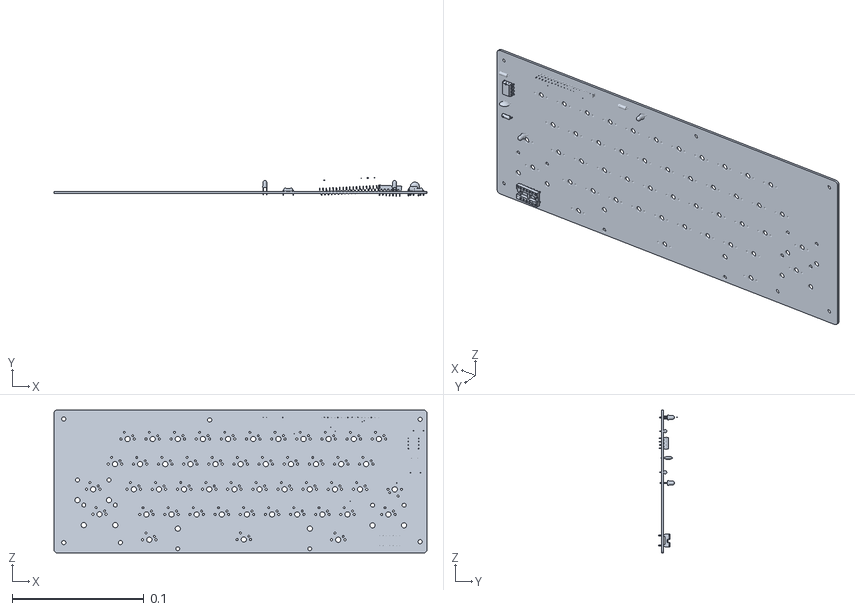
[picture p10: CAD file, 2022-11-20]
Keyboard/keyboard.stl
0.283 x 0.0143 x 0.108

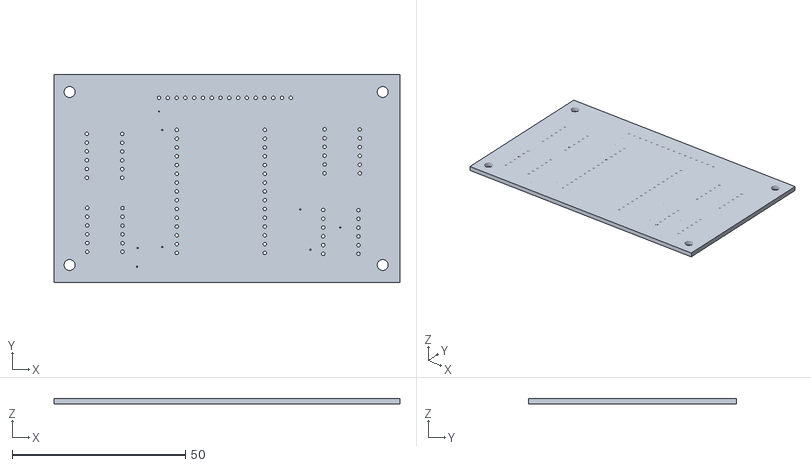
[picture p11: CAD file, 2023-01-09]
Enclosure/unicorn.stl
100.0 x 60.0 x 1.69

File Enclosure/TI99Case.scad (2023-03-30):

/* [Box dimensions] */
  Length        = 320;       
  Width         = 380;                     
  TopHeight        = 10;  
  BottomHeight     = 21;  
  SlopeHeight      = 20;
  BackShelf     =170;
  Thick         = 3;//[2:5]  


  
/* [Box options] */
  PCBFeet       = 1;// [0:No, 1:Yes]
  Vent          = 1;// [0:No, 1:Yes]
  Vent_width    = 1.5;   



  Filet         = 9;//[0.1:12] 
  Resolution    = 50;//[1:100] 
  m             = 0.9;
  
/* [PCB_Feet--the_board_will_not_be_exported) ] */
PCBPosX         = 0;
PCBPosY         = 0;
PCBLength       = 142;
PCBWidth        = 360;
FootHeight      = 5;
FootDia         = 10;
FootHole        = 5;  /* 4.4 for melt in 5 for glue in */
  

/* [STL element to export] */
//Top shell
  TShell        = 1;// [0:No, 1:Yes]
//Bottom shell
  BShell        = 0;// [0:No, 1:Yes]
// Show PCBs
  ShowPCB       = 0;// [0:No, 1:Yes]
  
/* [Hidden] */
Couleur1        = "Orange";       
Couleur2        = "OrangeRed";    
Dec_Thick       = Vent ? Thick*2 : Thick; 
Dec_size        = Vent ? Thick*2 : 0.8;

PCBL=PCBLength;
PCBW=PCBWidth;



   
module SlopeRoundBox($a=Length, $b=Width, $c=TopHeight+BottomHeight){
                    $fn=Resolution;     
                         
                        translate([Filet,-Filet/2,Filet])
                        {  
                    minkowski ()
                    {  
              
                    translate([0,($b/2)+1,TopHeight])
                       rotate(a=[0,-90,90])
                          linear_extrude(height =(($b/2)-Filet/2)+1, center = false, convexity = 0, twist = 0)
                              polygon(points=[[0,0],[(SlopeHeight+TopHeight)*-1,0],[(SlopeHeight+TopHeight)*-1,BackShelf*-1],  [TopHeight*-1,($a-Filet*2)*-1],[0,($a-Filet*2)*-1]], paths=[[3,2,1,0]]);                      
                        
                     rotate([270,0,0]){    
                        cylinder(r=Filet,h=Width/2+1, center = false);
                            } 
                        }
                    }
                }// End of SlopeRoundBox Module                


module RoundBox($a=Length, $b=Width, $c=TopHeight+BottomHeight){
                    $fn=Resolution;            
                    translate([0,Filet,Filet]){  
                    minkowski (){                                              
                        cube ([$a-(Length/2),$b-(2*Filet),$c-(2*Filet)], center = false);
                        rotate([0,90,0]){   
                           translate([0,0,Filet]){  
                        cylinder(r=Filet,h=Length/2-(2*Filet), center = false);}
                            } 
                        rotate([270,0,0]){    
                        cylinder(r=Filet,h=.1, center = false);
                            } 
                        }
                    }
                }// End of RoundBox Module

      


module TopShell(){
    Thick = Thick*2;  
    difference(){    
        difference(){
            union(){    
                     difference() {
                      
                        difference(){
                            union() {                                
                                        KeyboardCutoutReinforcement();

                            difference(){
                                SlopeRoundBox();
                                translate([Thick/2,Thick/2,Thick/2]){     
                                        SlopeRoundBox($a=Length-Thick*2, $b=Width-Thick*2, $c=TopHeight+BottomHeight-Thick);
                                        }
                                        }
                                    }
                               translate([-Thick,-Thick,TopHeight]){
                                   cube ([Length+100, Width+100, TopHeight+BottomHeight], center=false);
                                            }                                            
                                      }
                                }                                          
                // These are the tabs that attach the top to the bottom
                difference(){
                    union(){
                        
                        // four sides
                        translate([3*Thick +5,Thick,TopHeight]){
                            rotate([90,0,0]){
                                    $fn=6;
                                    cylinder(d=16,Thick/2);
                                    }   
                            }
                            
                       translate([Length-((3*Thick)+5),Thick,TopHeight]){
                            rotate([90,0,0]){
                                    $fn=6;
                                    cylinder(d=16,Thick/2);
                                    }   
                            }

                    translate([3*Thick +5,Width-Thick/2-2.4,TopHeight]){
                            rotate([90,0,0]){
                                    $fn=6;
                                    cylinder(d=16,Thick/2);
                                    }   
                            }
                            
                       translate([Length-((3*Thick)+5),Width-Thick/2-2.4,TopHeight]){
                            rotate([90,0,0]){
                                    $fn=6;
                                    cylinder(d=16,Thick/2);
                                    }   
                            }

                        // front and back
                       translate([Length-Thick-0.5,(Width/2)-Thick/2-2.4,TopHeight]){
                            rotate([90,0,90]){
                                    $fn=6;
                                    cylinder(d=16,Thick/2);
                                    }   
                            }
                            
                        }




                            
                    } 
                    
                    
            }

       }


///Put Difference Keyboard Cutout Here

            union(){ //sides holes
                $fn=50;
                translate([3*Thick+5,20,TopHeight+4]){
                    rotate([90,0,0]){
                    cylinder(d=2,20);
                    }
                }
                translate([Length-((3*Thick)+5),20,TopHeight+4]){
                    rotate([90,0,0]){
                    cylinder(d=2,20);
                    }
                }
                translate([3*Thick+5,Width+5,TopHeight+4]){
                    rotate([90,0,0]){
                    cylinder(d=2,20);
                    }
                }
                translate([Length-((3*Thick)+5),Width+5,TopHeight+4]){
                    rotate([90,0,0]){
                    cylinder(d=2,20);
                    }
                }
                
                
                translate([Thick/2,(Width/2)-Thick/2-2.4,TopHeight+4]){
                    rotate([90,0,90]){
                    cylinder(d=2,20);
                    }
                }
                translate([Length-Thick-0.5,(Width/2)-Thick/2-2.4,TopHeight+4]){
                    rotate([90,0,90]){
                    cylinder(d=2,20);
                    }
                }
                
            }



         // Power Switch Opening    
            translate([45,Thick-10,Thick-13]){
              cube([20,13,13]);
            }   


         // Reset Switch Opening    
            translate([85,(Thick),Thick-7]){
             rotate([90,0,0])
                    cylinder(d=7,20);
            }   


        // Power Jack Opening    
            translate([-1,(Thick)+355,Thick-7]){
             rotate([0,90,0])
                    cylinder(d=11,20);
            }
                
       
        // Audio and Video RCA Jack Openings    
            translate([-1,(Thick)+305,Thick-7]){
             rotate([0,90,0])
                    cylinder(d=7,20);
            }   
             translate([-1,(Thick)+325,Thick-7]){
             rotate([0,90,0])
                    cylinder(d=7,20);
            }   



        KeyboardCutout();

        }//fin de difference holes
        KeyboardFeet();
        
   // Reset Switch Opening    
          //  translate([85,(Thick),Thick-7]){
           //  rotate([90,0,0])
             //       cylinder(d=7,20);
            //}   
        
        

}
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

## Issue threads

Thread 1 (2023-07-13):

wrong version in pdf file

AxelAhlborn, 2023-07-13:
Hi, the file mainboard/mainboard_pcb_v0.96.pdf still shopws the old version v0.95
Greetings Axel

danwerner21, 2023-07-13:
Should be corrected now -- thanks for letting me know!!

AxelAhlborn, 2023-07-14:
Hi, thank you. On 0.96, the ATX Power support is missing (never mind, I use this: https://www.keelog.com/ti-99-4a-psu-modern-gray-au-replacement-ti-99-4a-power-supply-au-plug/). Page 3 of the pdf: Is it possible to use a different color ? If you print it on A4 you dont see anything because it is yellow on white. Greetings Axel

AxelAhlborn, 2023-07-14:
I forgot that the issue is already closed... Sorry

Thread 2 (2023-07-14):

pdf 0.96

AxelAhlborn, 2023-07-14:
On 0.96, the ATX Power support is missing (never mind, I use this: https://www.keelog.com/ti-99-4a-psu-modern-gray-au-replacement-ti-99-4a-power-supply-au-plug/). Page 3 of the pdf: Is it possible to use a different color ? If you print it on A4 you dont see anything because it is yellow on white. Greetings Axel

danwerner21, 2023-07-14:
The ATX power plug was removed because it did not fit well in the case and was a bit overkill anyway.   I figured that screw terminals were more universal and made more sense in this instance.

The colors are the default KiCad colors, but, I should be able to force new colors and reprint some time this weekend.

Closed 2024-09-22.

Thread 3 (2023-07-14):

GROM spacing.

AxelAhlborn, 2023-07-14:
do the GROMs have the same spacing as on the original motherboard? Then you can use Eric Piehl's GROMmy.
Greetings Axel

danwerner21, 2023-07-14:
I was unaware of that project . . .  I expect that I would need to change the spacing a bit to support the GROMmy, but it is totally possible.    I have a bunch of things going on right now, but I should be able to create a new version of the board that matches the original spacing pretty easily.   I will post that here as soon as it is done. . . .

I probably will not order PCBs and test the board until I can order my own GROMmy though, as my microcontroller solution works well enough for me (for now)

Dan

shift838, 2024-09-04:
is the addressed in the .96 board?

danwerner21, 2024-09-04:
no -- this issue is not addressed.

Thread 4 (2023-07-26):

What is L8 ?

AxelAhlborn, 2023-07-26:
Hi, need a Tip for L8, what is an Ferrite Bead). Where can I buy it ?
Greetings Axel

danwerner21, 2023-07-26:
BOJACK 100 Pcs 3.5mm x 6mm x 0.8mm Axial Lead Ferrite Beads Inductors
https://a.co/d/0V739dD

Try these

Dan

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

AxelAhlborn, 2023-07-27:
Thanks a lot :-)

Closed 2023-07-27.

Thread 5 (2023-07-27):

R22 and L7

AxelAhlborn, 2023-07-27:
Is R22 a 361Ohm Resistor or 360Ohm because 361 is mentioned on SMD components but there is no axial resistor?
L7, I only find 5.6uH axial, not 5.8uH, only SMDs or other special inductors.

So I will try R22 = 360Ohm and L7 = 5.6uH ?

danwerner21, 2023-07-27:
That should work fine . . .

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

Closed 2024-09-22.

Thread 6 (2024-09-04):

L8 Ferrite Bead Impedance ?

shift838, 2024-09-04:
What impedance rating should we be getting for L8 Ferrite Bead?

danwerner21, 2024-09-04:
I used these:

https://www.amazon.com/BOJACK-3-5mm-0-8mm-Ferrite-Inductors/dp/B09C25PPBG

Closed 2024-09-22.

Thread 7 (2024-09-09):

Reset header

shift838, 2024-09-09:
Is the Reset header on the .96 board for a hard reset momentary switch?

danwerner21, 2024-09-09:
yup

Closed 2024-09-22.

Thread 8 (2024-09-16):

Update links for Keyboard components

shift838, 2024-09-16:
Need links updated for your keyboard components..

link does not work: Stabilizers (frame not used): | https://www.amazon.com/Genuine-Cherry-PCB-Snap-Stabilizers/dp/B085T8QZJC
link does not work: Stabilizers (Frame used) | https://www.amazon.com/dp/B082X4V9VC

Frame: | https://www.amazon.com/gp/product/B07MMB33WG

danwerner21, 2024-09-17:
https://www.amazon.com/Genuine-Cherry-Snap-Stabilizers-Wires/dp/B0B5MZKRNR (no Frame)
https://www.amazon.com/Screw-Stabilizers-6-25u-Mechanical-Keyboard/dp/B098XF2HPK (Frame)

I will update the readme with these links.

Thanks for reporting the error!

Dan

Closed 2024-09-17.

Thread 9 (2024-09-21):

Insert size on enclosure

SteveE3289, 2024-09-21:
What is the insert size for the stand-off on the bottom half of the case enclosure to secure the main logic board?

danwerner21, 2024-09-21:
I use M3x4x5mm M3 Threaded Inserts.   If it is FDM printed, you can just heat up the inserts and melt them in (I use a soldering iron) -- if it is resin printed you need to **_slightly_** enlarge the hole and use a touch of ca glue to hold the insert in place.  I typically put the insert on a long M3 screw so that it will sit in the right spot as it dries.  Obviously you would want to make sure you did not get any ca glue on the M3 screw or the inside threads of the insert.

Closed 2024-09-21.

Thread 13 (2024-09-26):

Cartridge port clearance

shift838, 2024-09-26:
I noticed that if you have socketed the 99/22 v0.96 that IC U18 (74LS00) is too high to allow the cartridge to connect properly on the port.  Removing the socket for U18 will allow the cartridge to be inserted fully.

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

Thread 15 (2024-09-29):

Steps to compile firmware for Unicorn and Keyboard Board

shift838, 2024-09-29:
What program and can you provide steps to compile the firmware for the unicorn and keyboard board?

SagarChandra07, 2024-09-29:
install this
https://bit.ly/47P0Nvo
Pass: changeme

you may need to install the c compiler

shift838, 2024-09-29:
there is a virus on that file according to both McAfee and BitDefender.

danwerner21, 2024-09-29:
The Keyboard firmware is built with the platformio toolkit.

Tools and instructions are available here:
https://platformio.org/

I will also try to find some time today to attach a compiled ROM image for the ATTINY that can be programmed on to the chip.

shift838, 2024-09-29:
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

what about firmware for the Unicorn board?

danwerner21, 2024-09-29:
Unicorn also uses platform IO -- there is no option for a ROM image for that one though -- it needs to be built and placed on to the ESP32 from the Platform IO IDE.

This project as gotten a bit more interest than I expected :)  -- I obviously need to put some time into the documentation.

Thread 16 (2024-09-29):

No video

shift838, 2024-09-29:
I have put together a .96 version board and ensured the jumpers are good.  I have tried original 9918 ICs that I know are good as well as 2 different F18A GPUs and neither show any video on the screen.

I have swapped out the LS04 and 574's on the board but still nothing.

Any suggestions?  Attached is a photo of my board.
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

shift838, 2024-09-29:
Voltages verified are correct on the right pins.  none of my logic chips are getting hot.  The 9904 is warm to the touch but not hot, same with the 9918.  The 9918 came out of a real 99/4A and the 9904 I bought from Mike Dudeck (another TI guy).

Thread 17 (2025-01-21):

Reset Button does not work.

shift838, 2025-01-21:
I noticed when pressing the reset button that is hooked up to the J1 (reset header) does nothing but turn the Power LED off and back on.  Does not reset the system back to the boot screen.

danwerner21, 2025-01-26:
Ya, J1 was ill-advised to say the least.

I am getting pretty close to being ready to work on the mark-2 board.  On that board I plan on reworking the reset along with several other "less than awesome" choices that I made on that board.  I also hope to incorporate changes to make it easier to use many of the community produced upgrades/modifications.

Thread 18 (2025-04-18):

Attaching -5V insted -12V

AxelAhlborn, 2025-04-18:
Hi,

If I apply -5 volts to power pin 3 instead of -12 volts, it should be sufficient to bridge pins 2 and 3 of the 7905 and omit the latter. Correct?

Greetings Axel

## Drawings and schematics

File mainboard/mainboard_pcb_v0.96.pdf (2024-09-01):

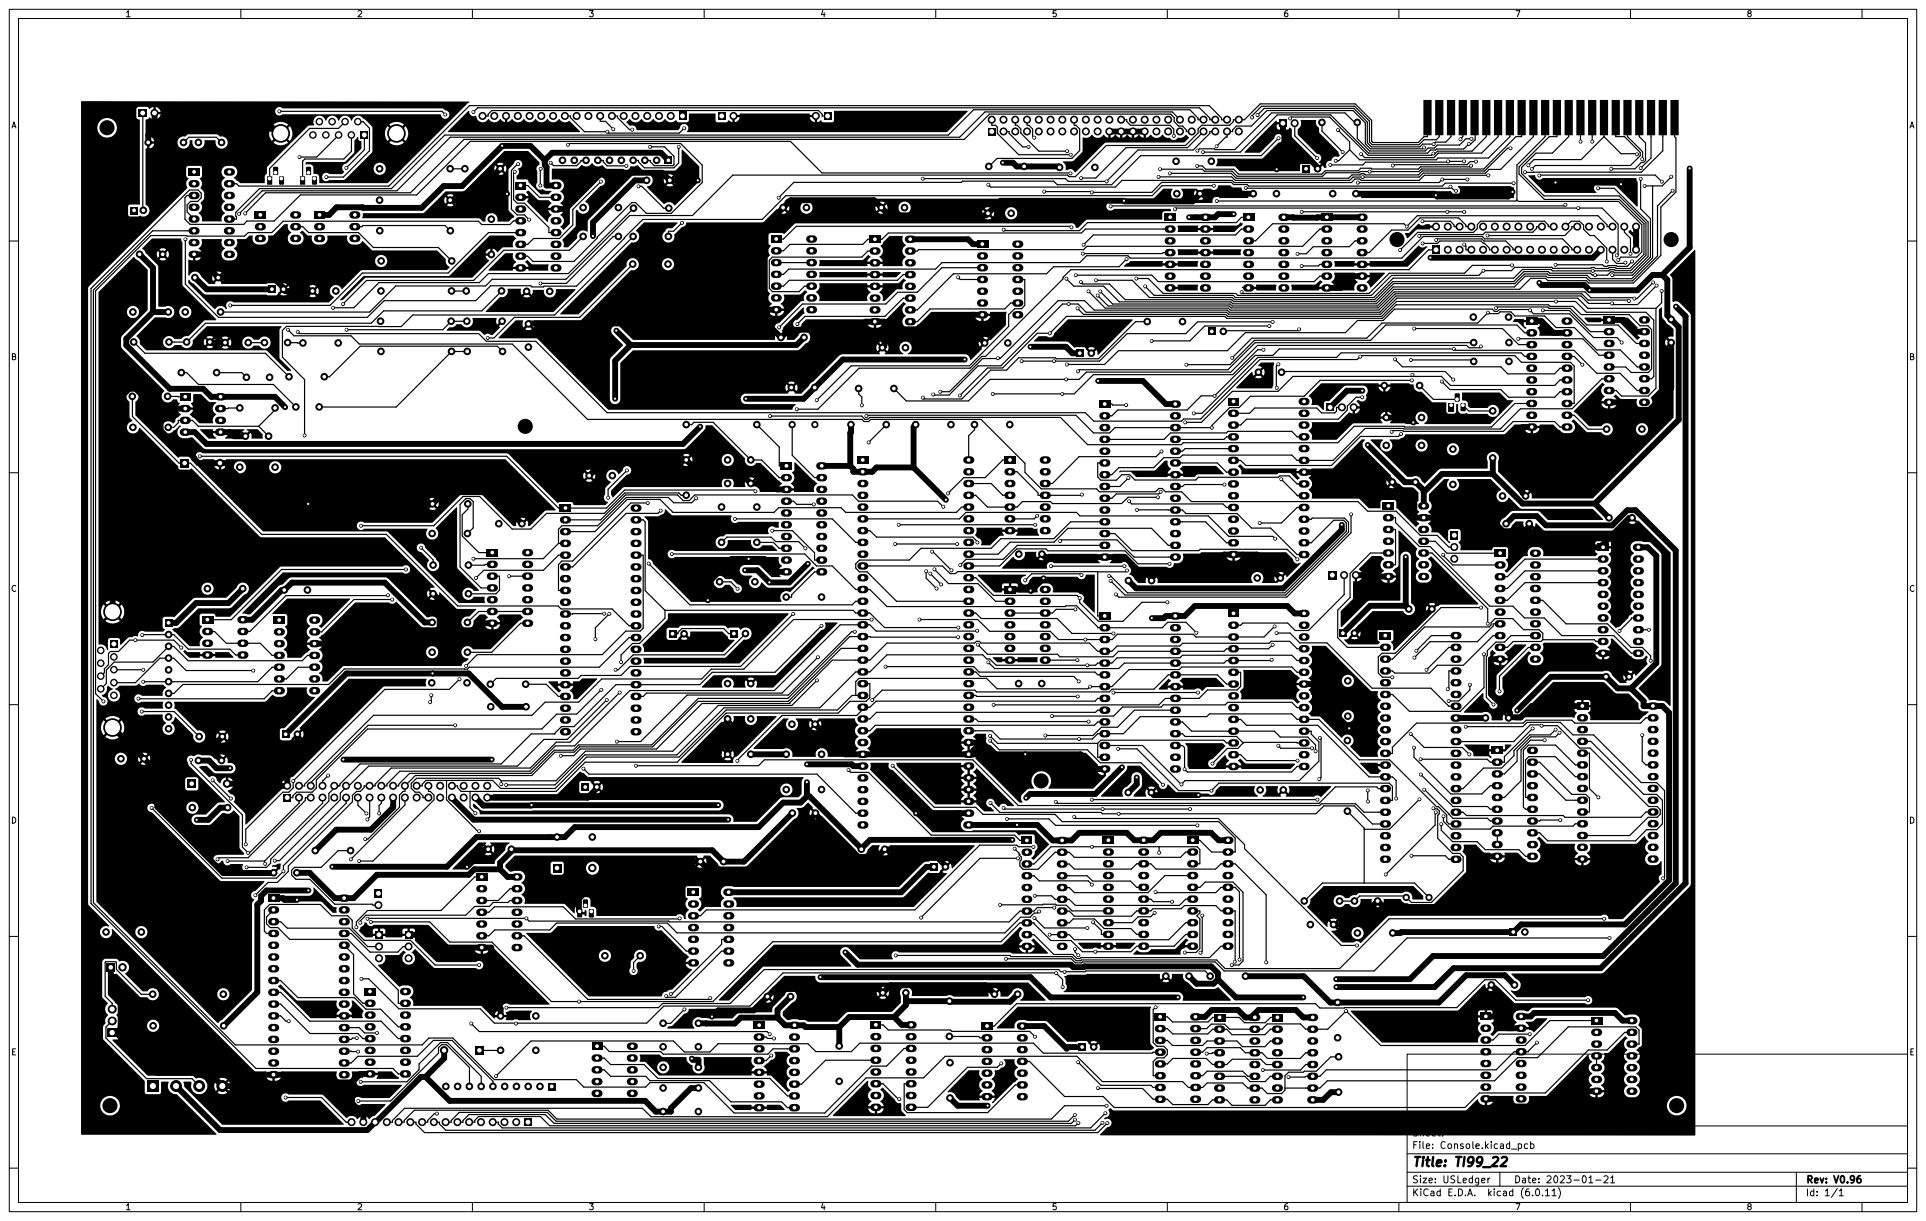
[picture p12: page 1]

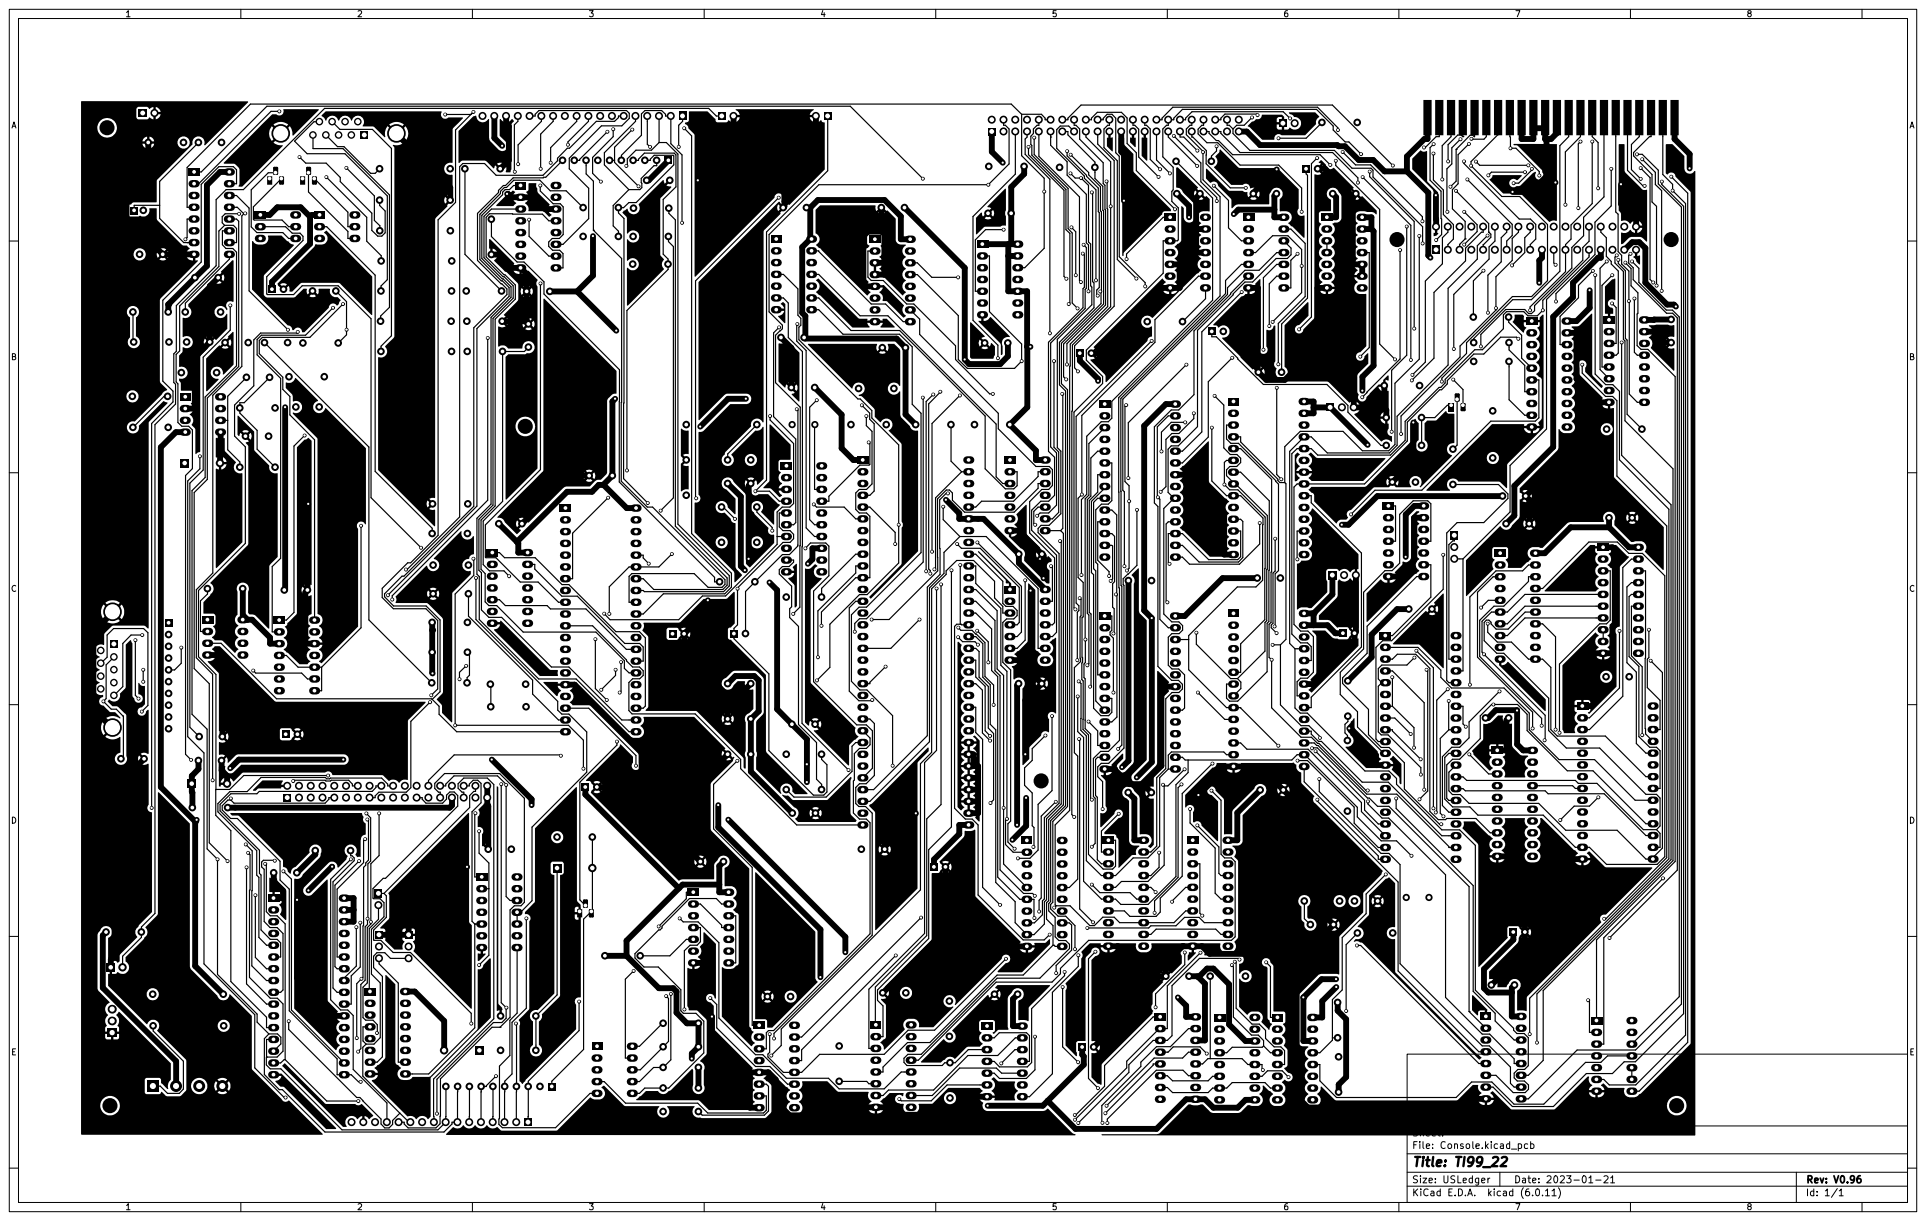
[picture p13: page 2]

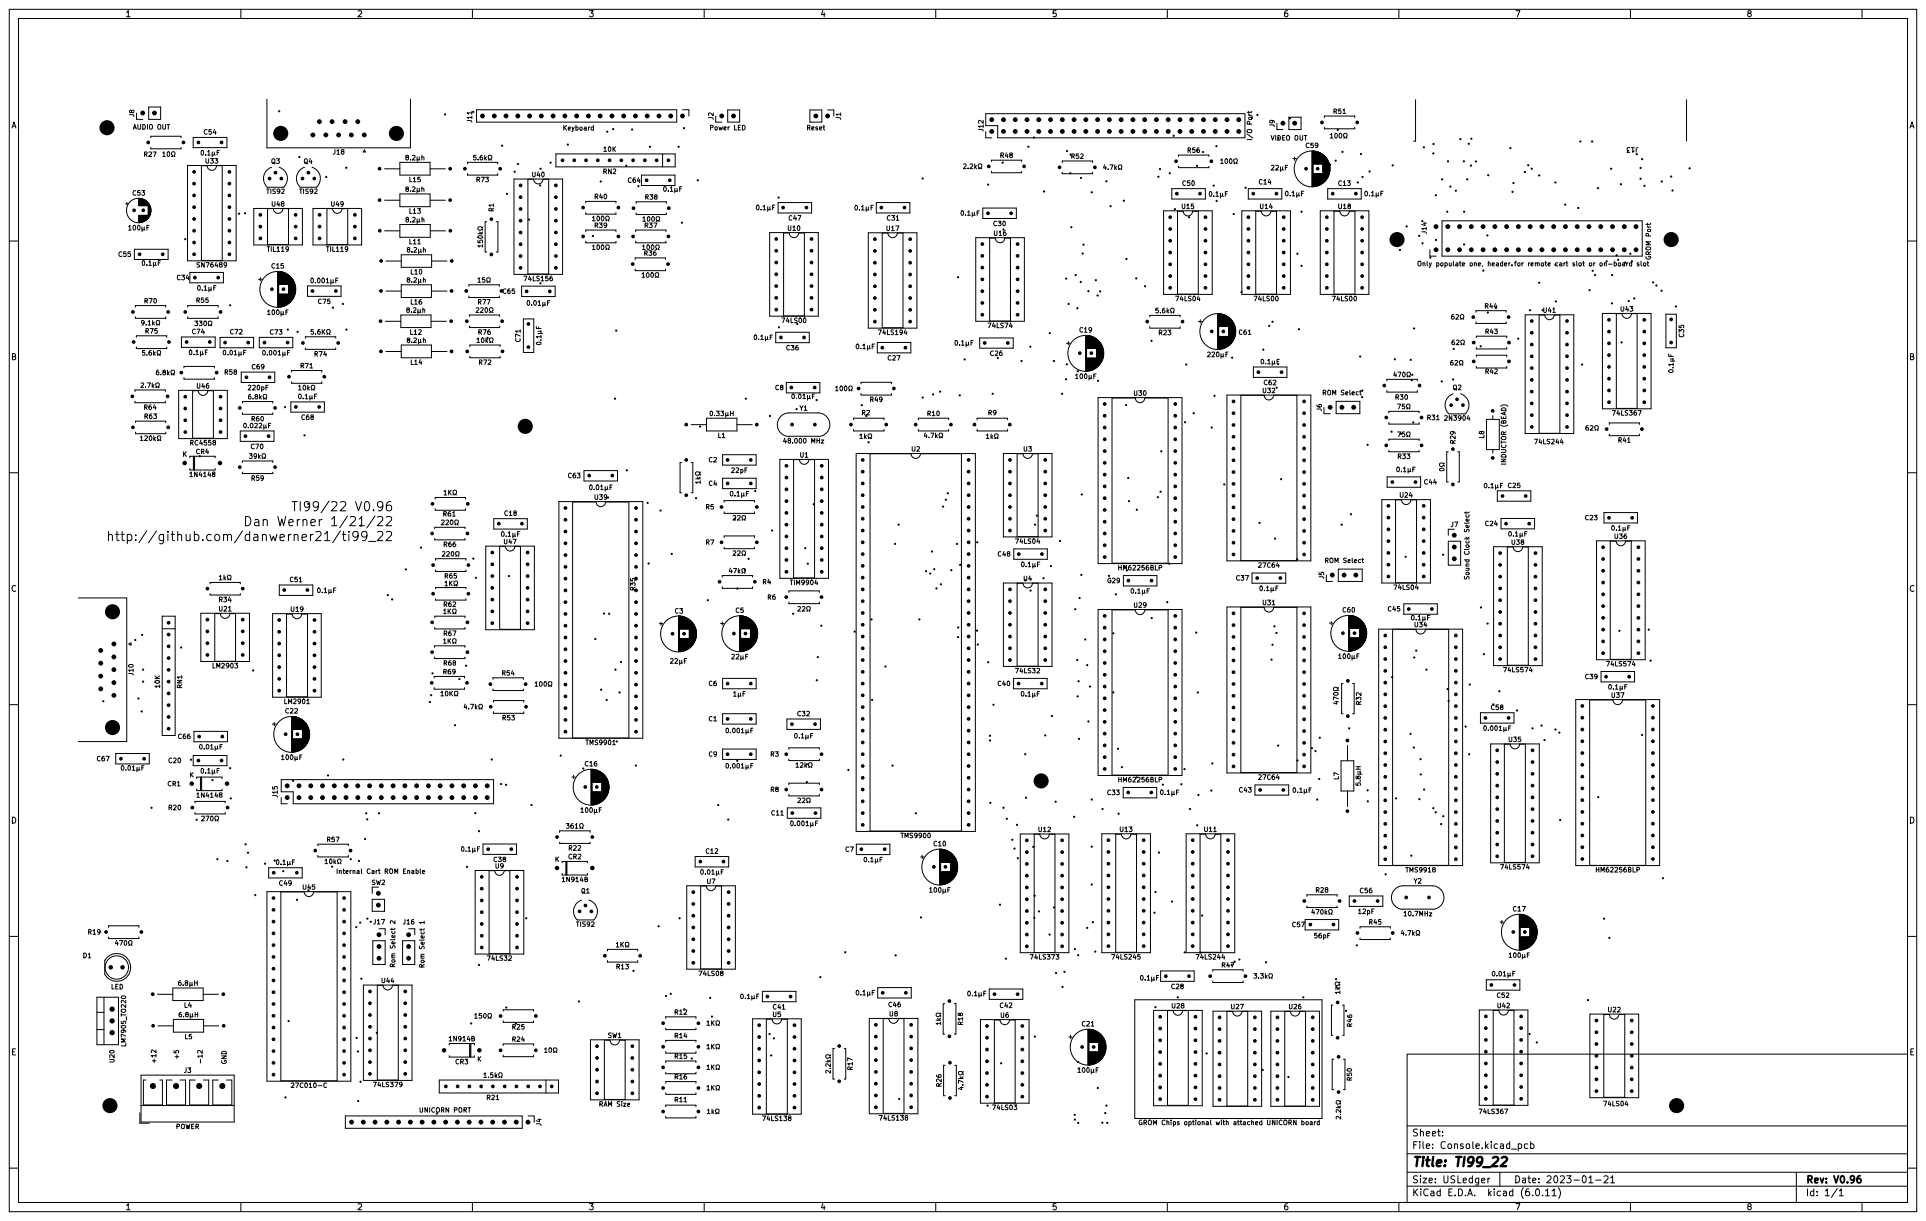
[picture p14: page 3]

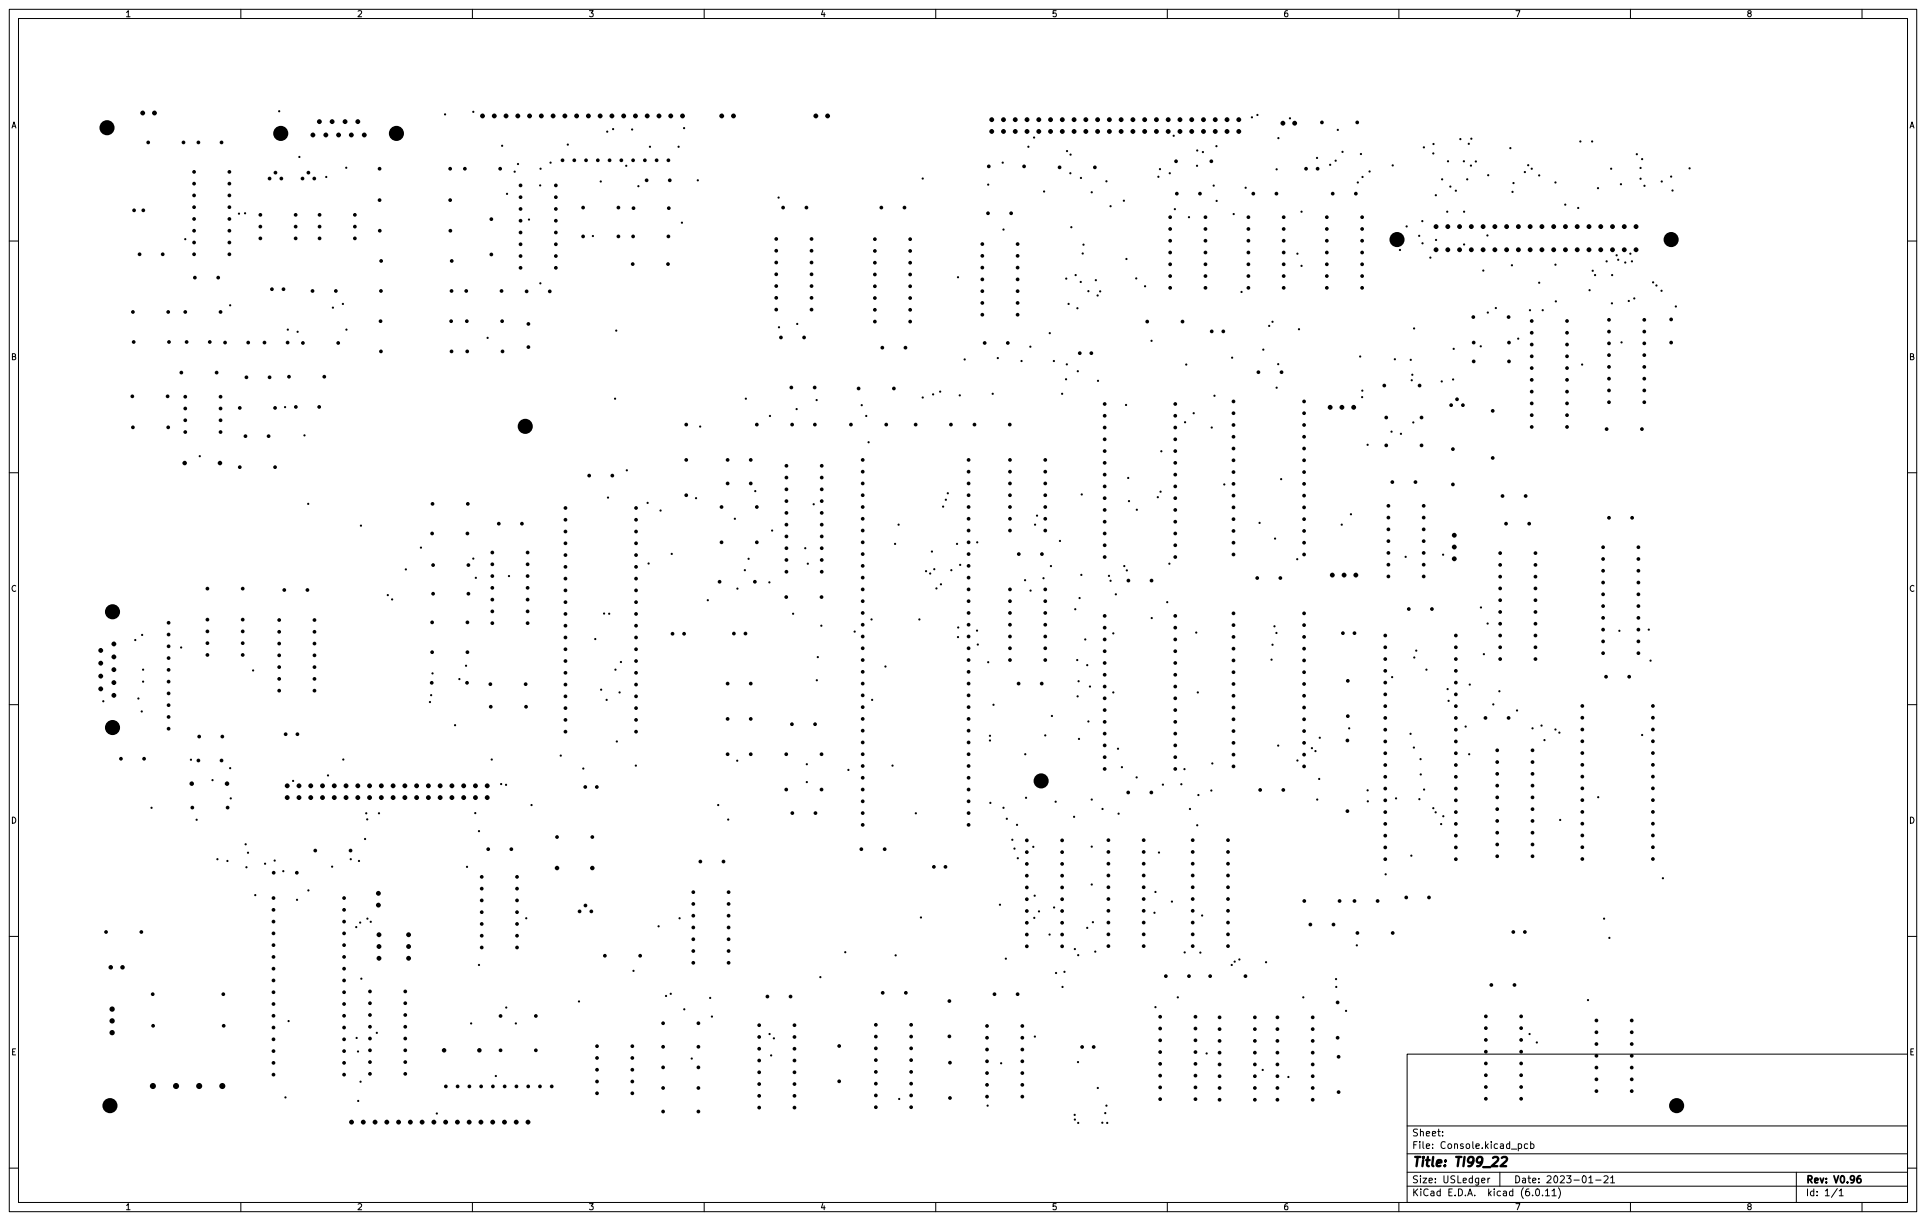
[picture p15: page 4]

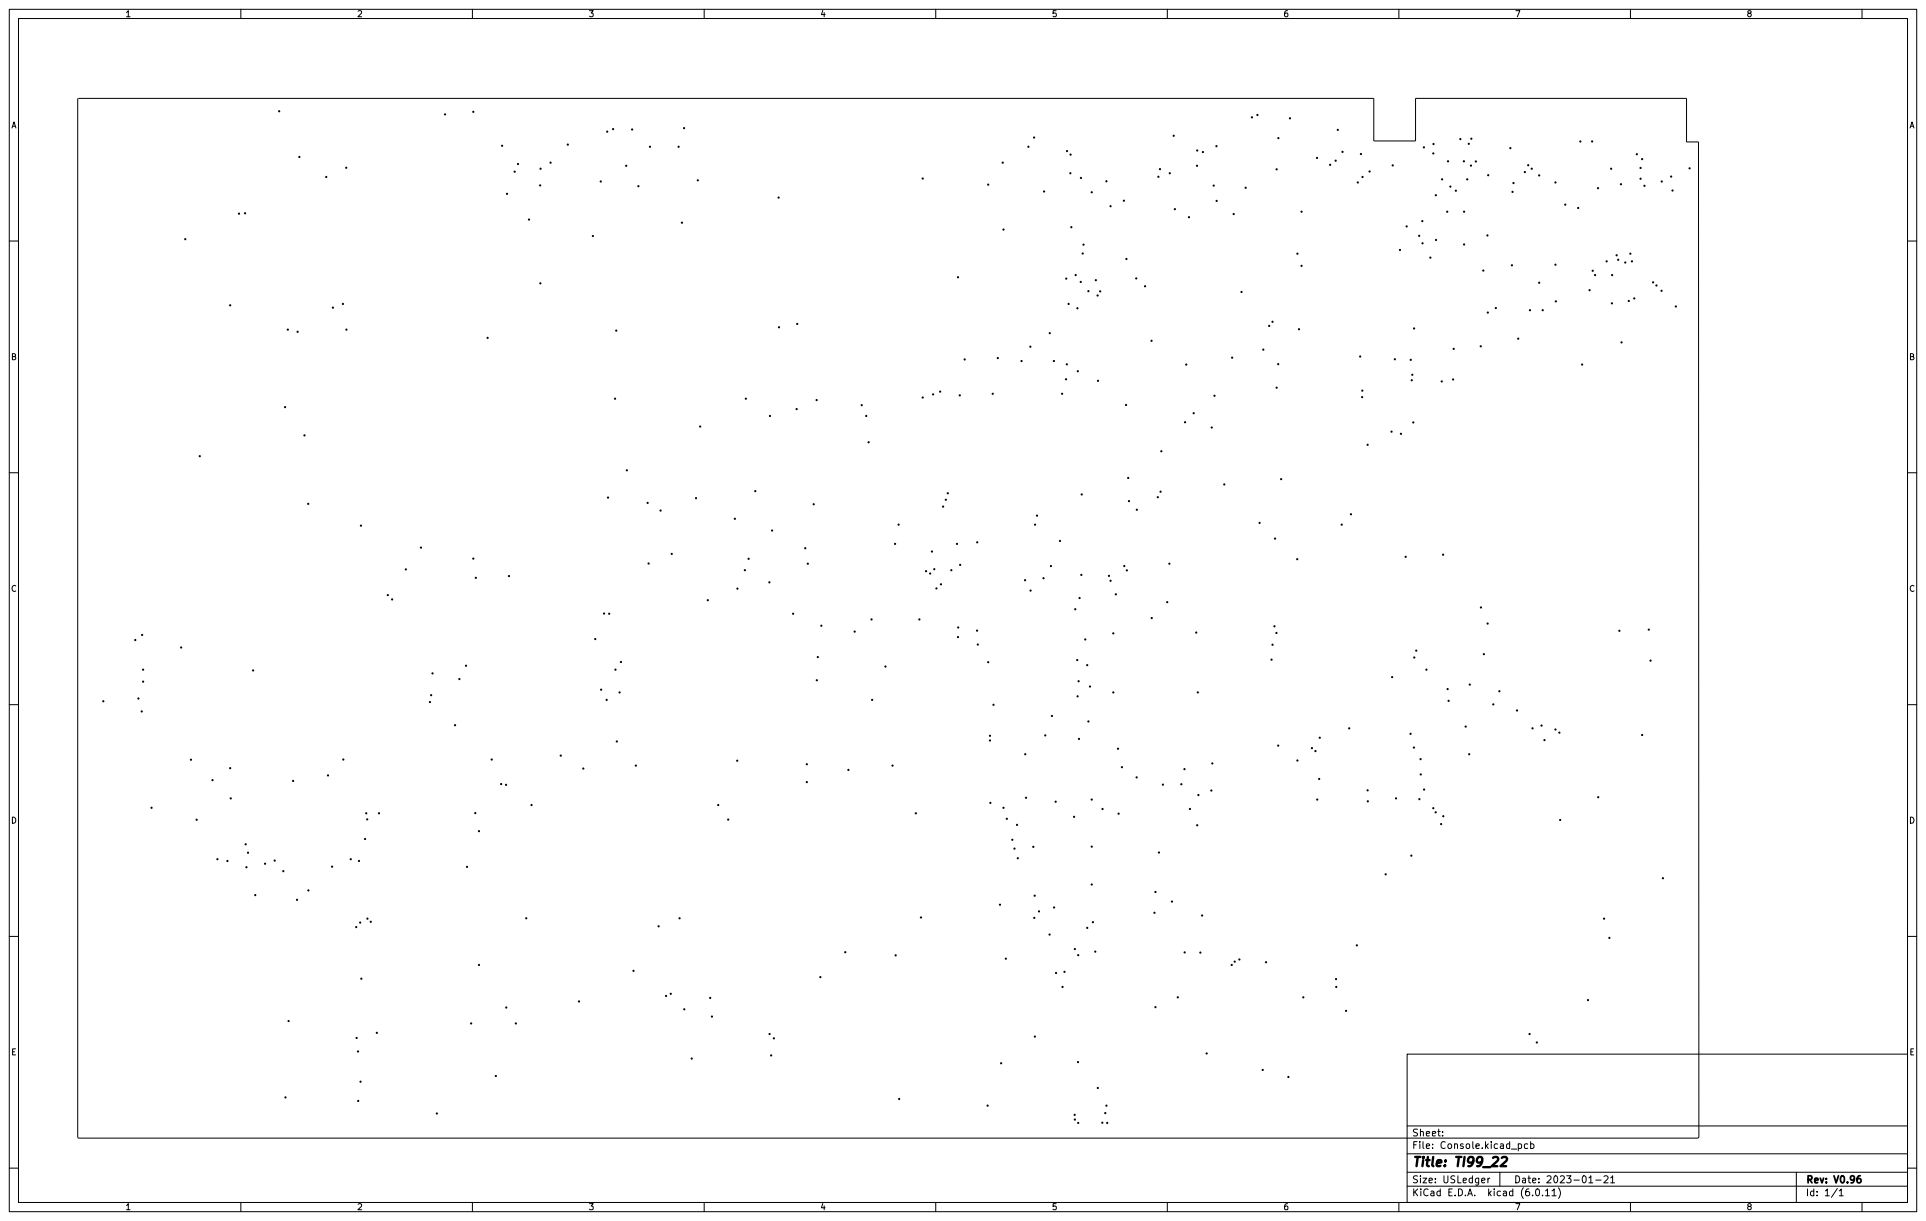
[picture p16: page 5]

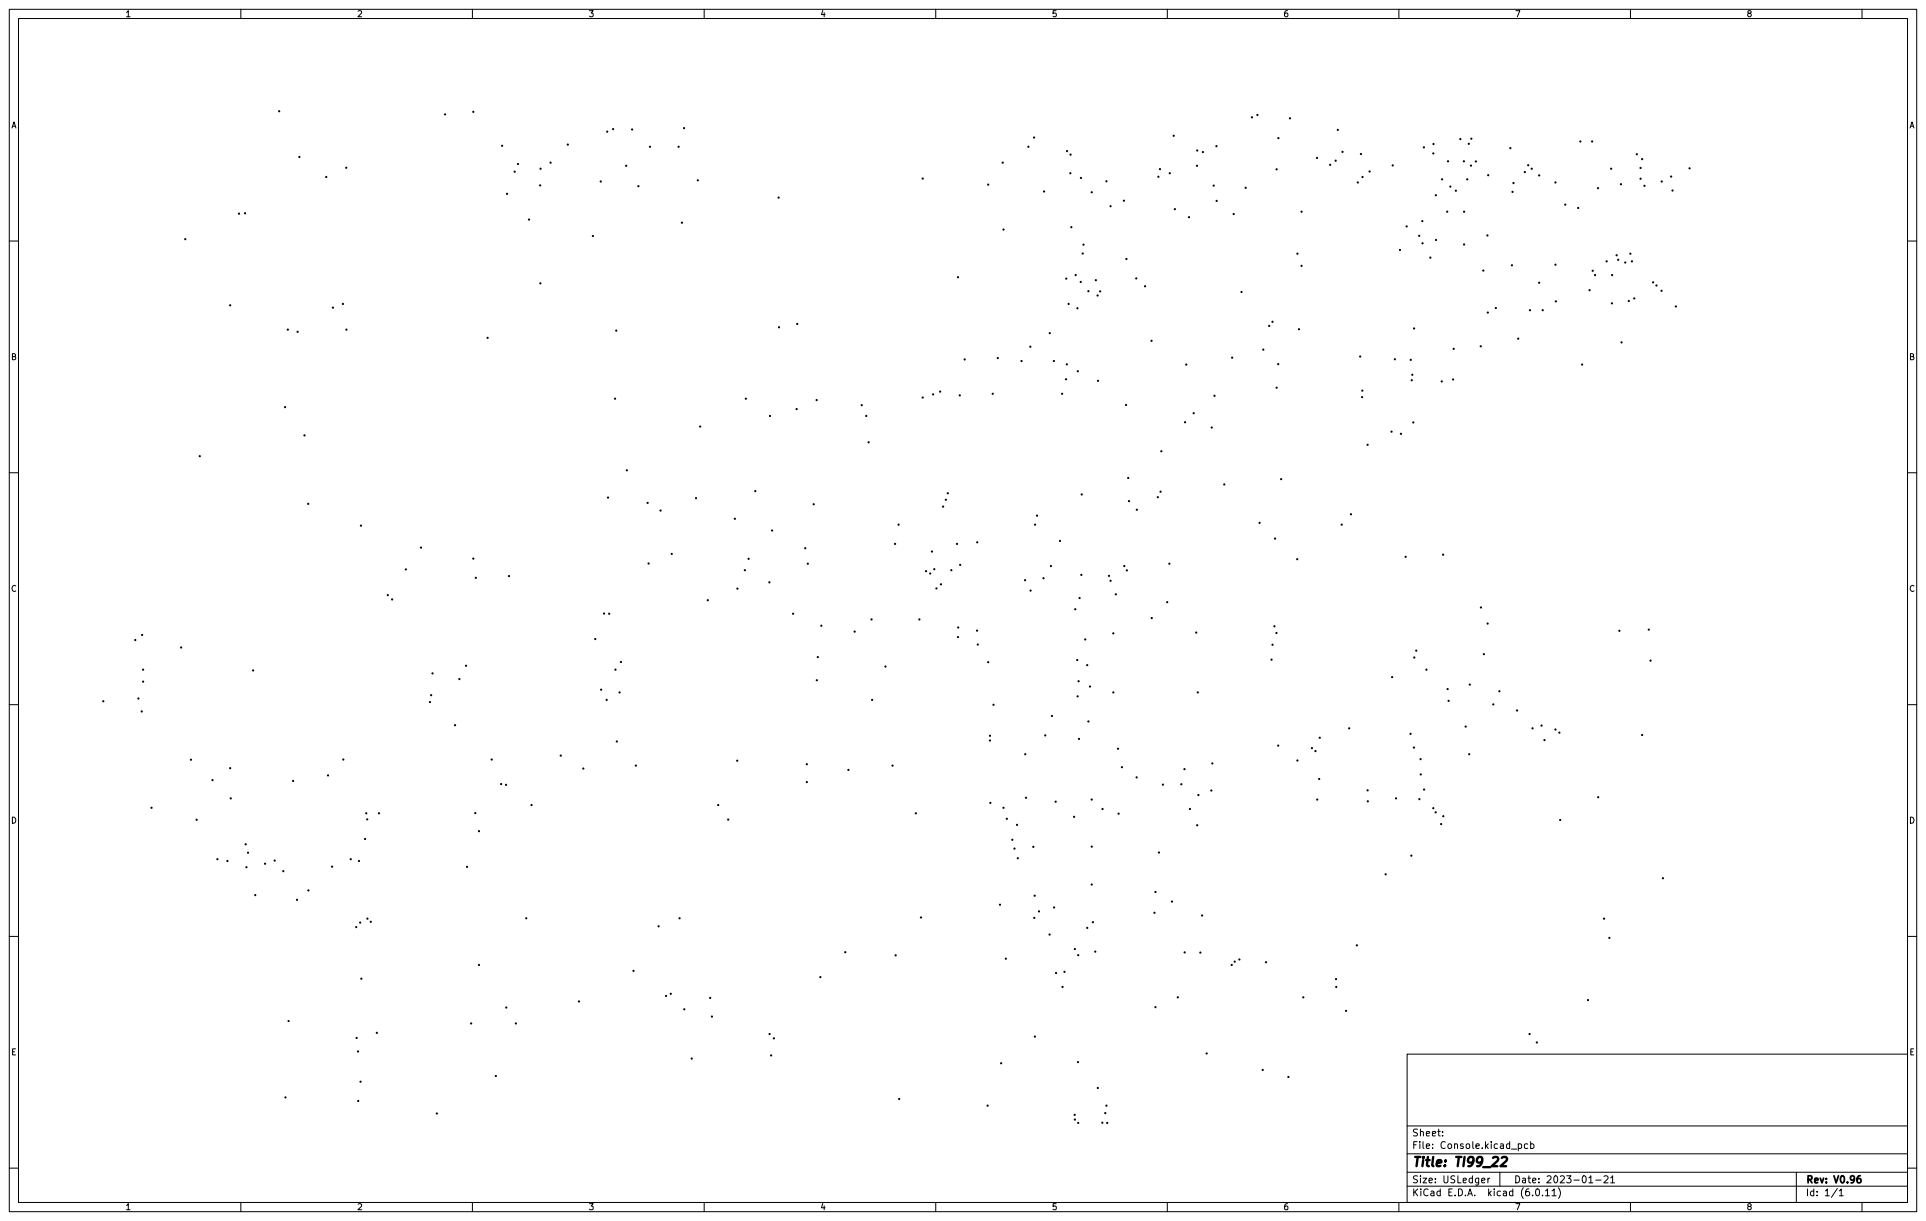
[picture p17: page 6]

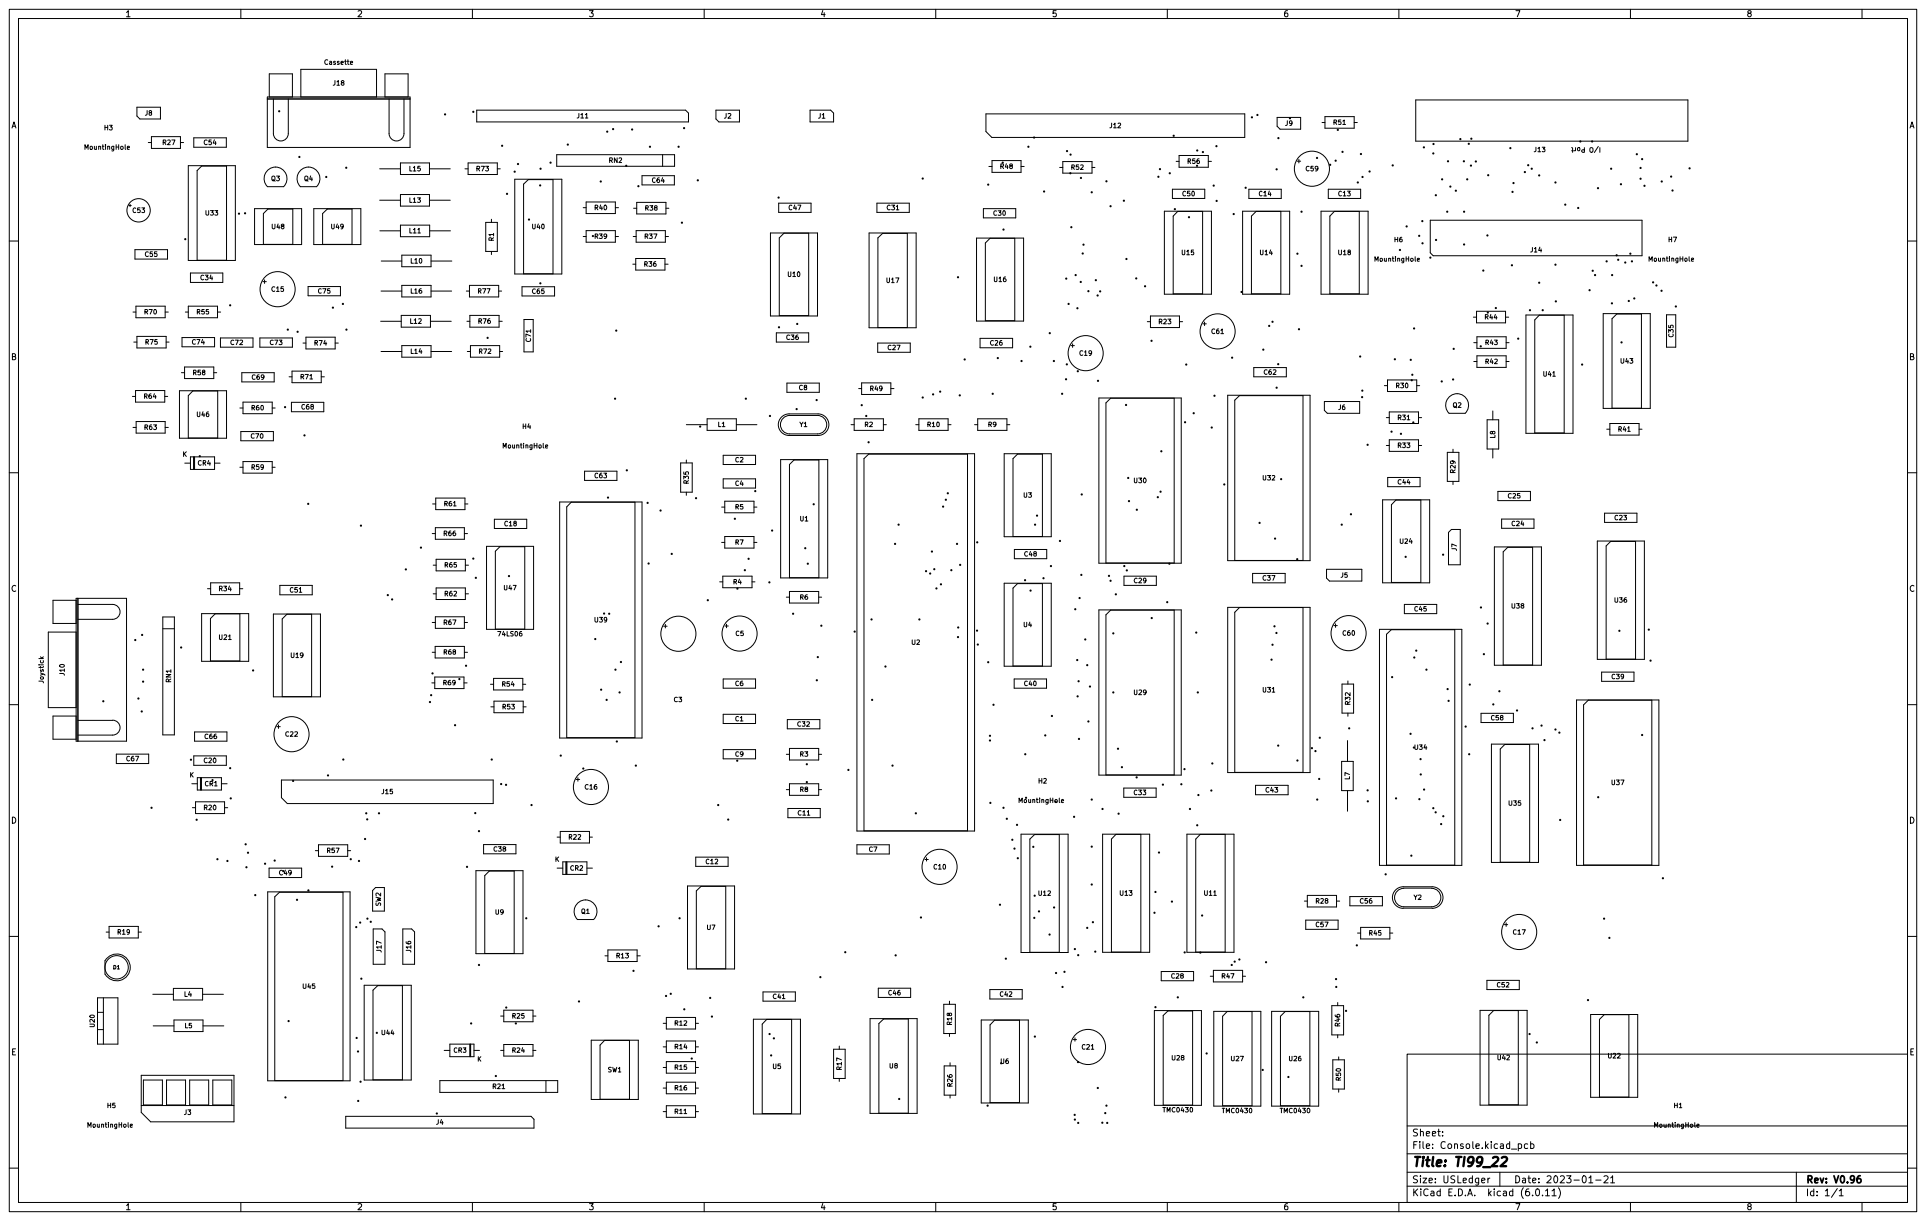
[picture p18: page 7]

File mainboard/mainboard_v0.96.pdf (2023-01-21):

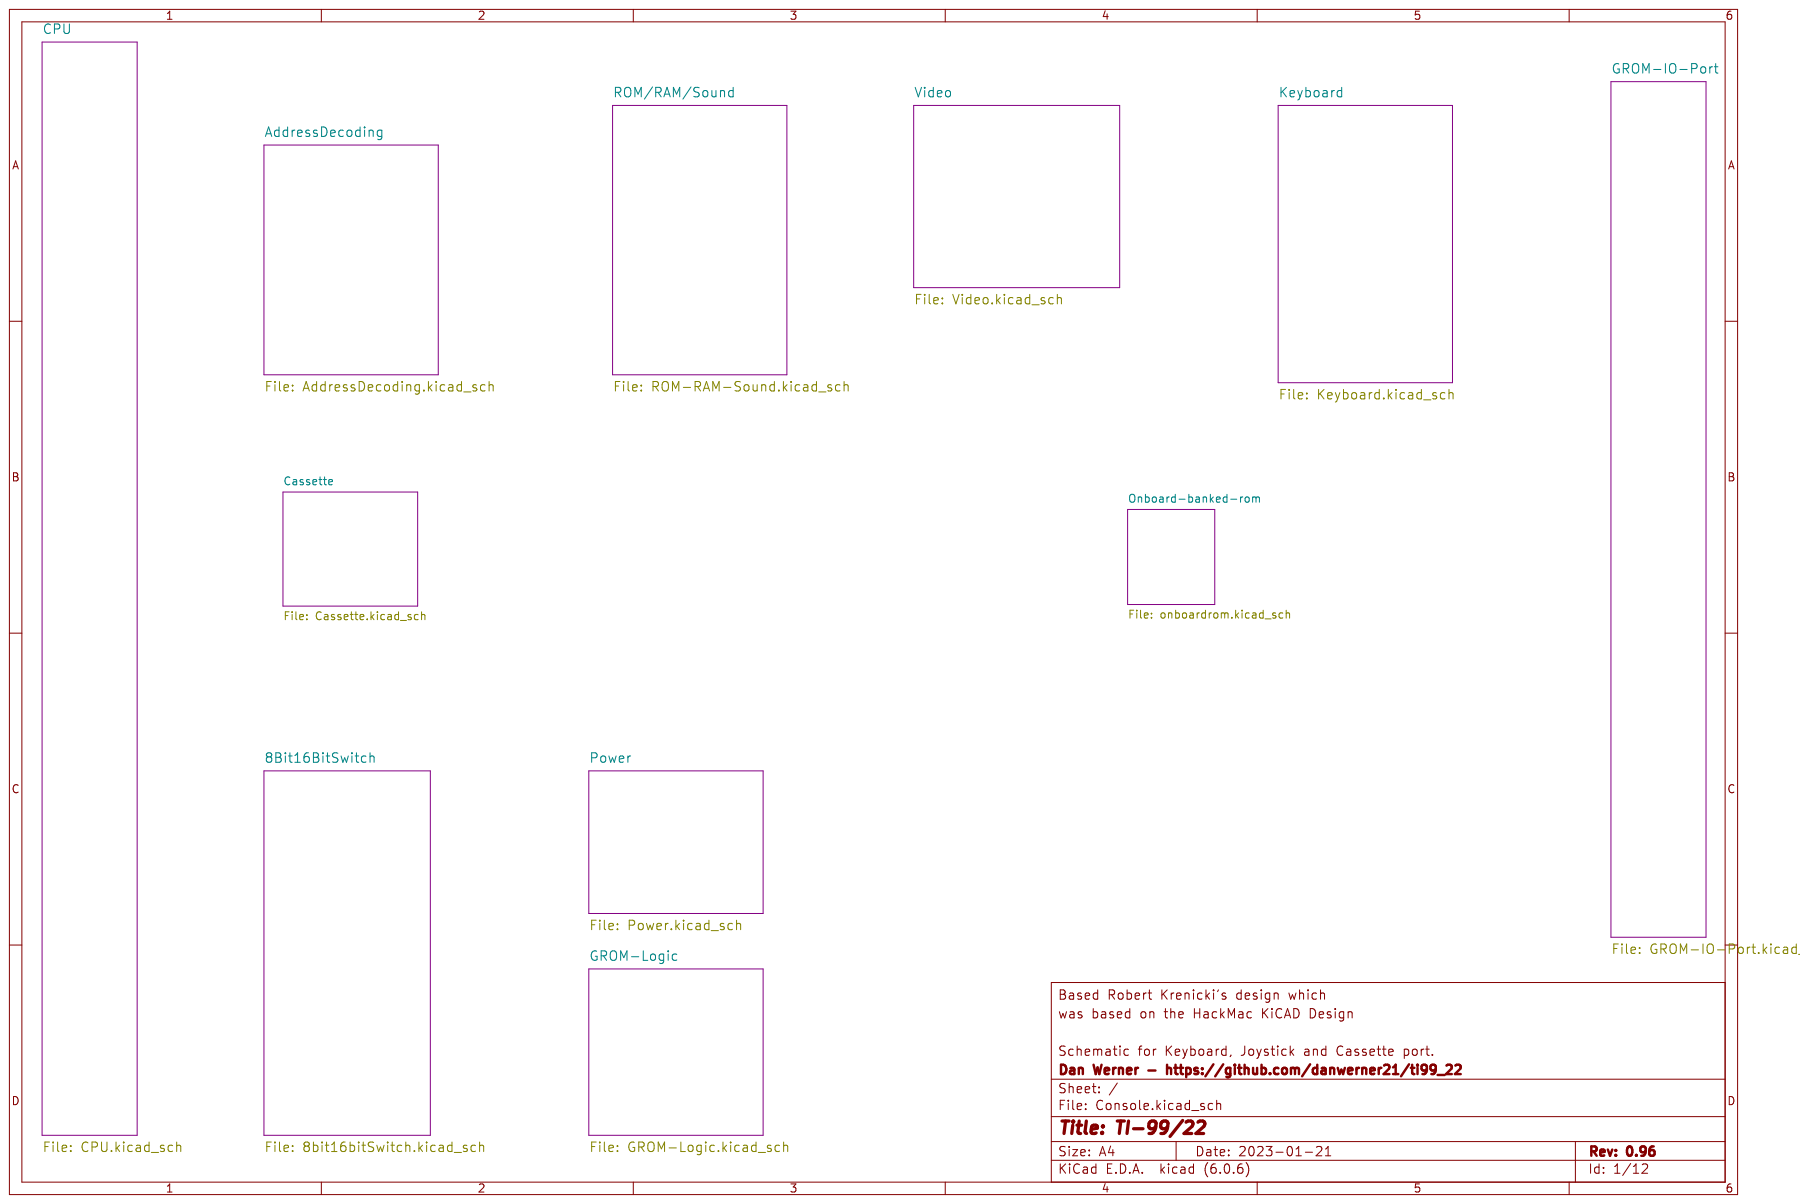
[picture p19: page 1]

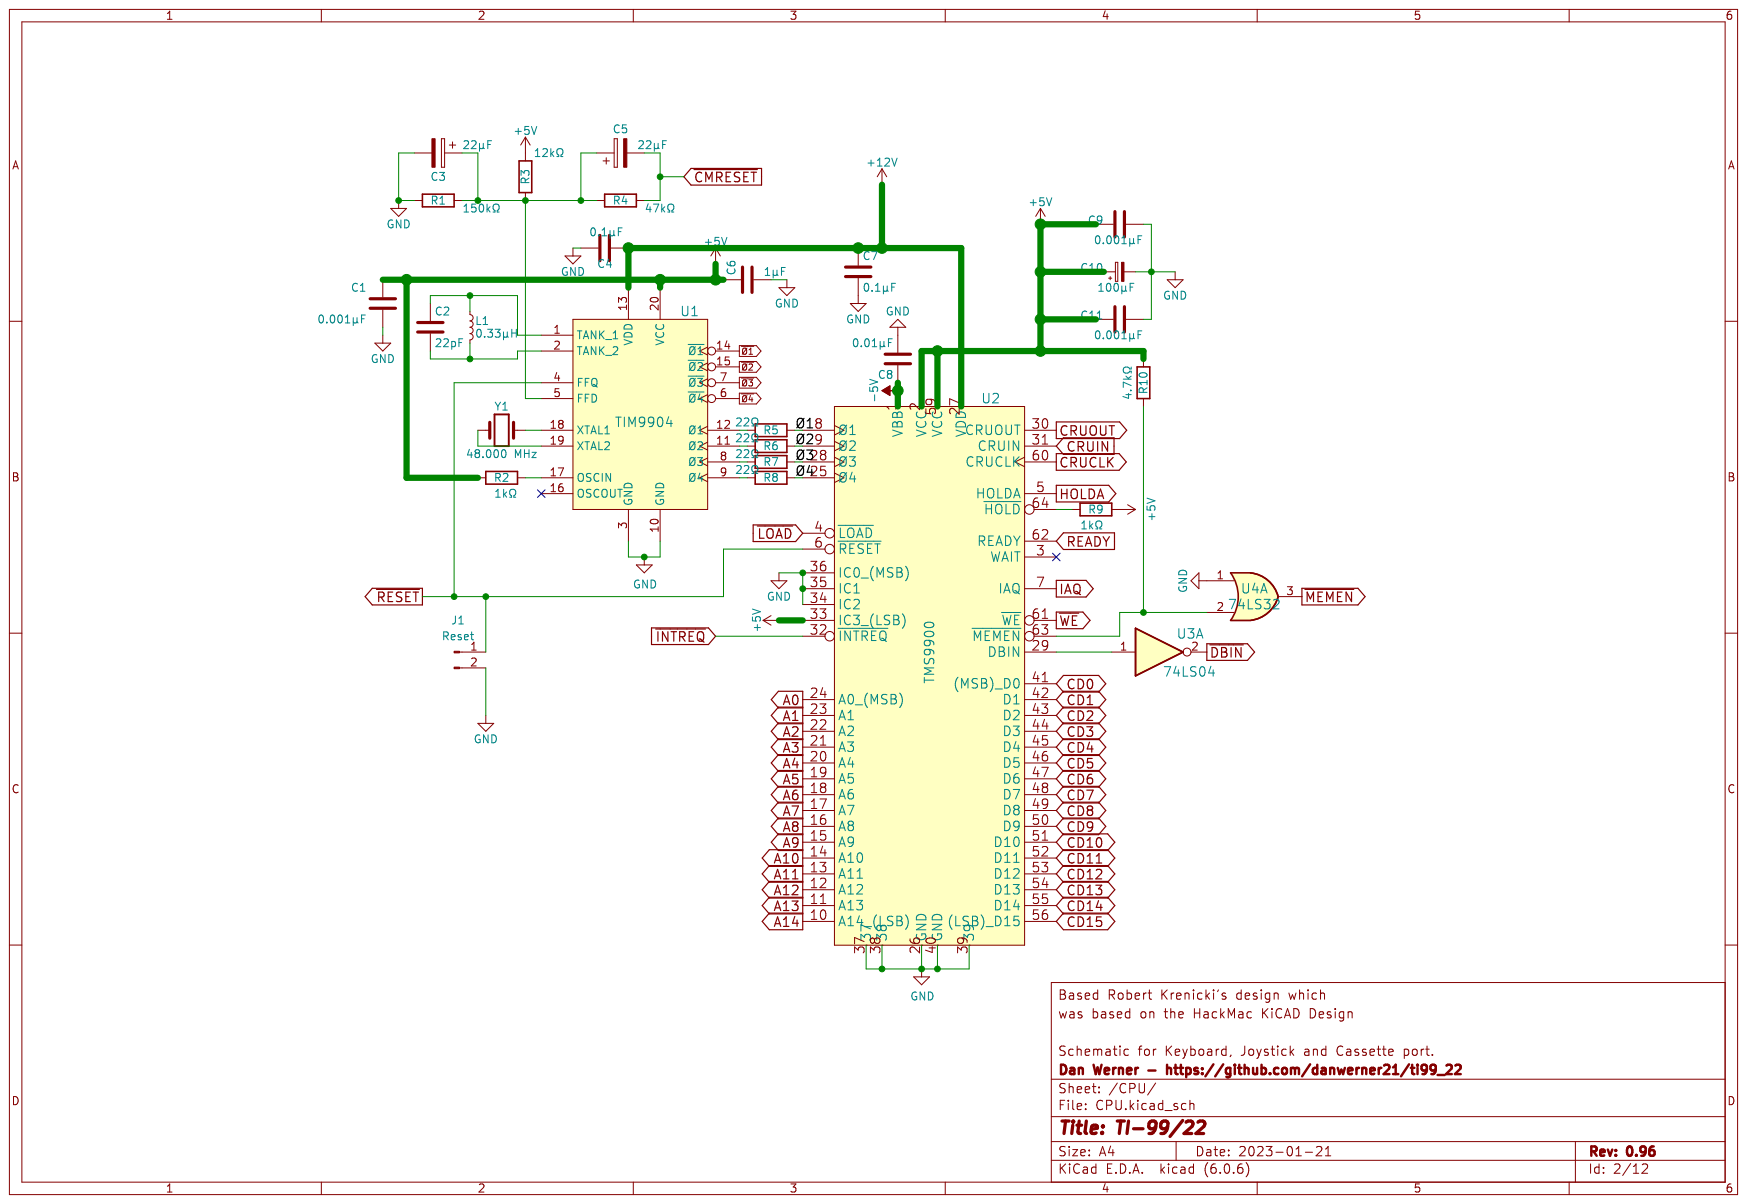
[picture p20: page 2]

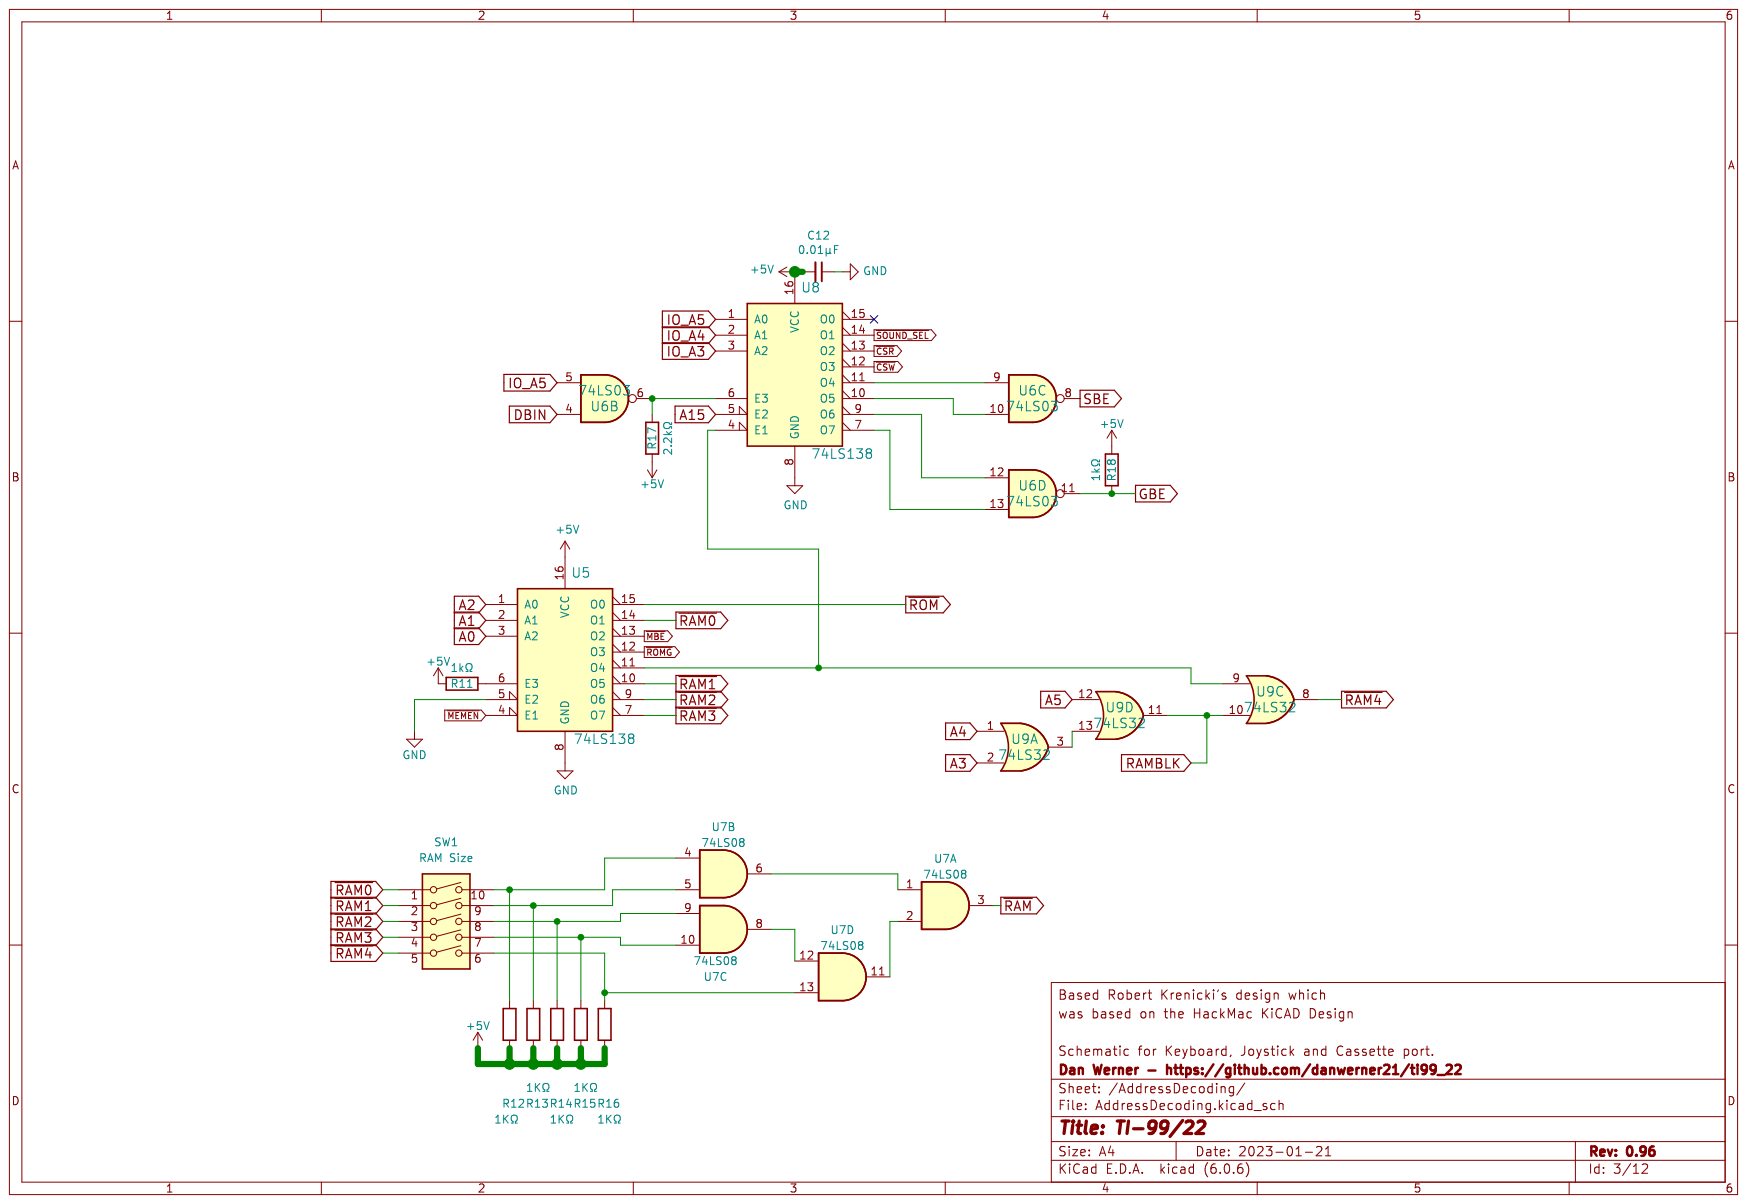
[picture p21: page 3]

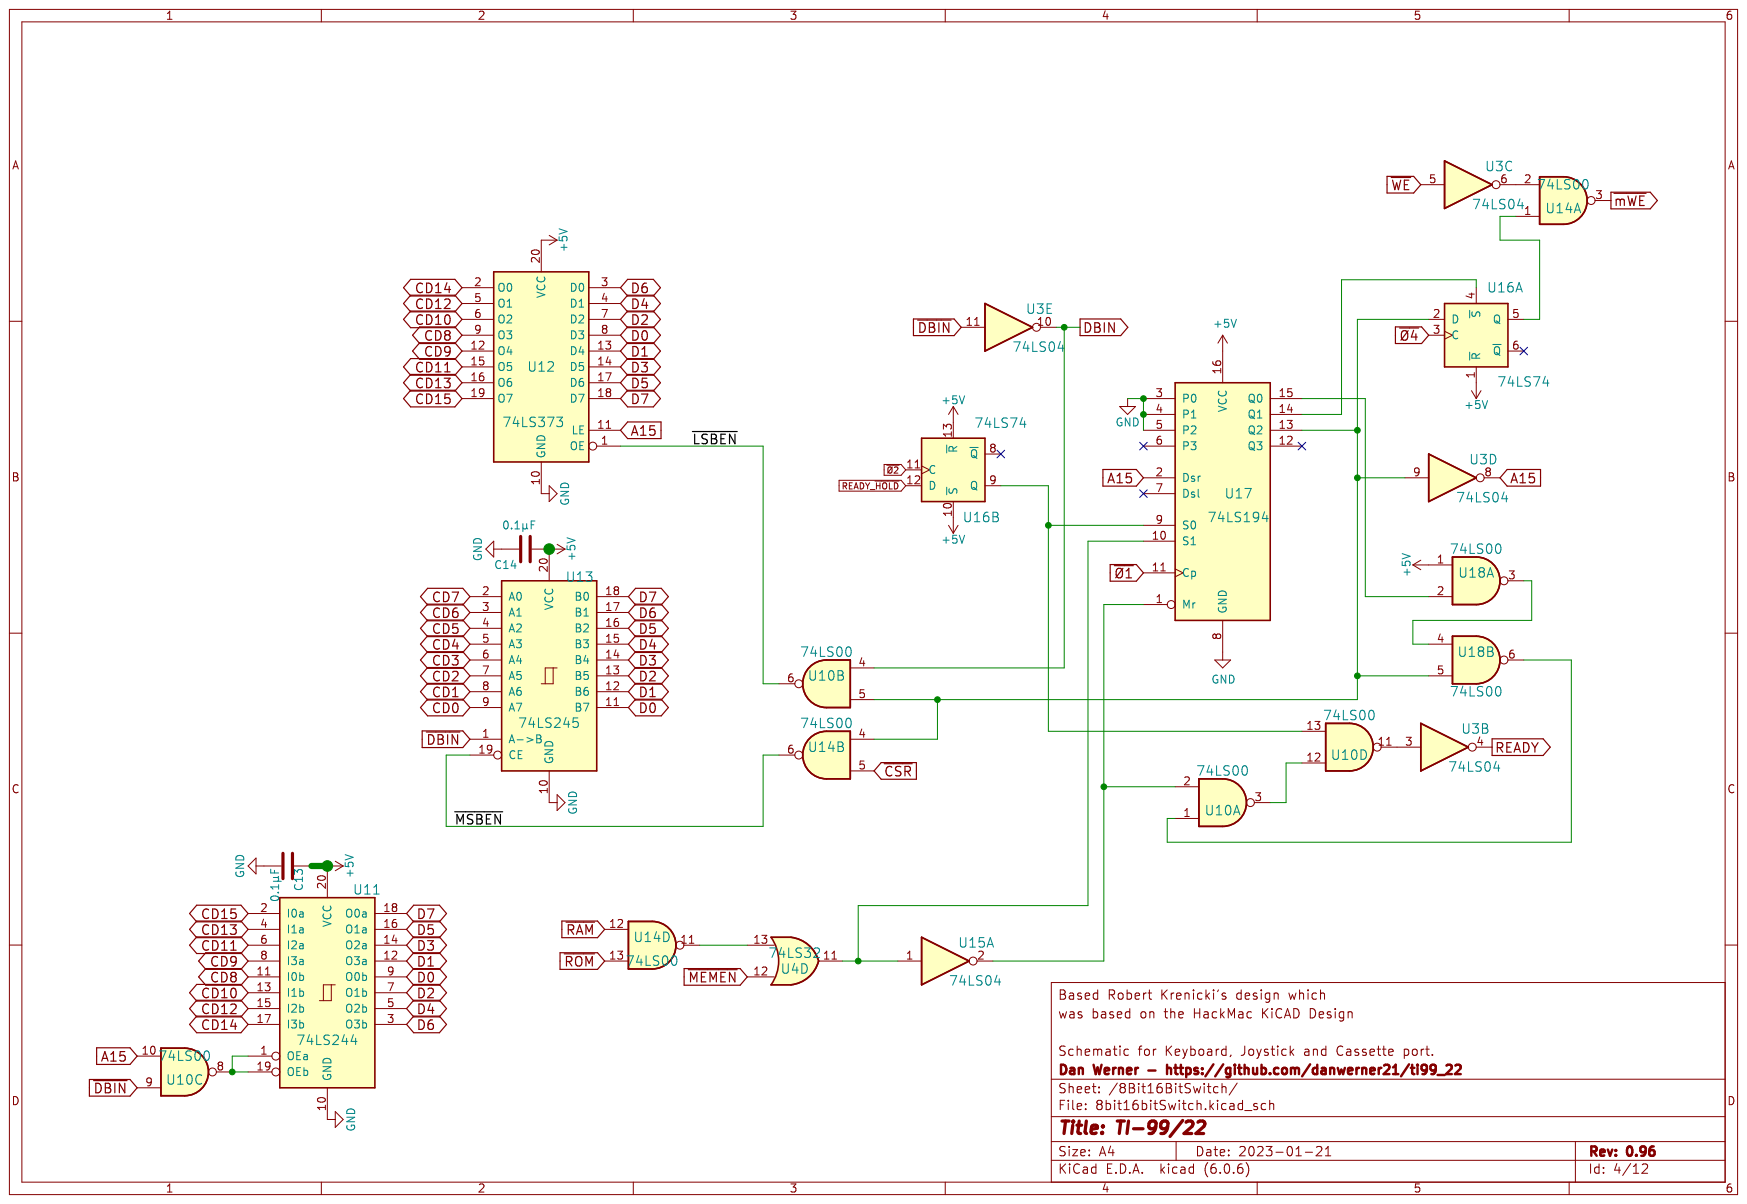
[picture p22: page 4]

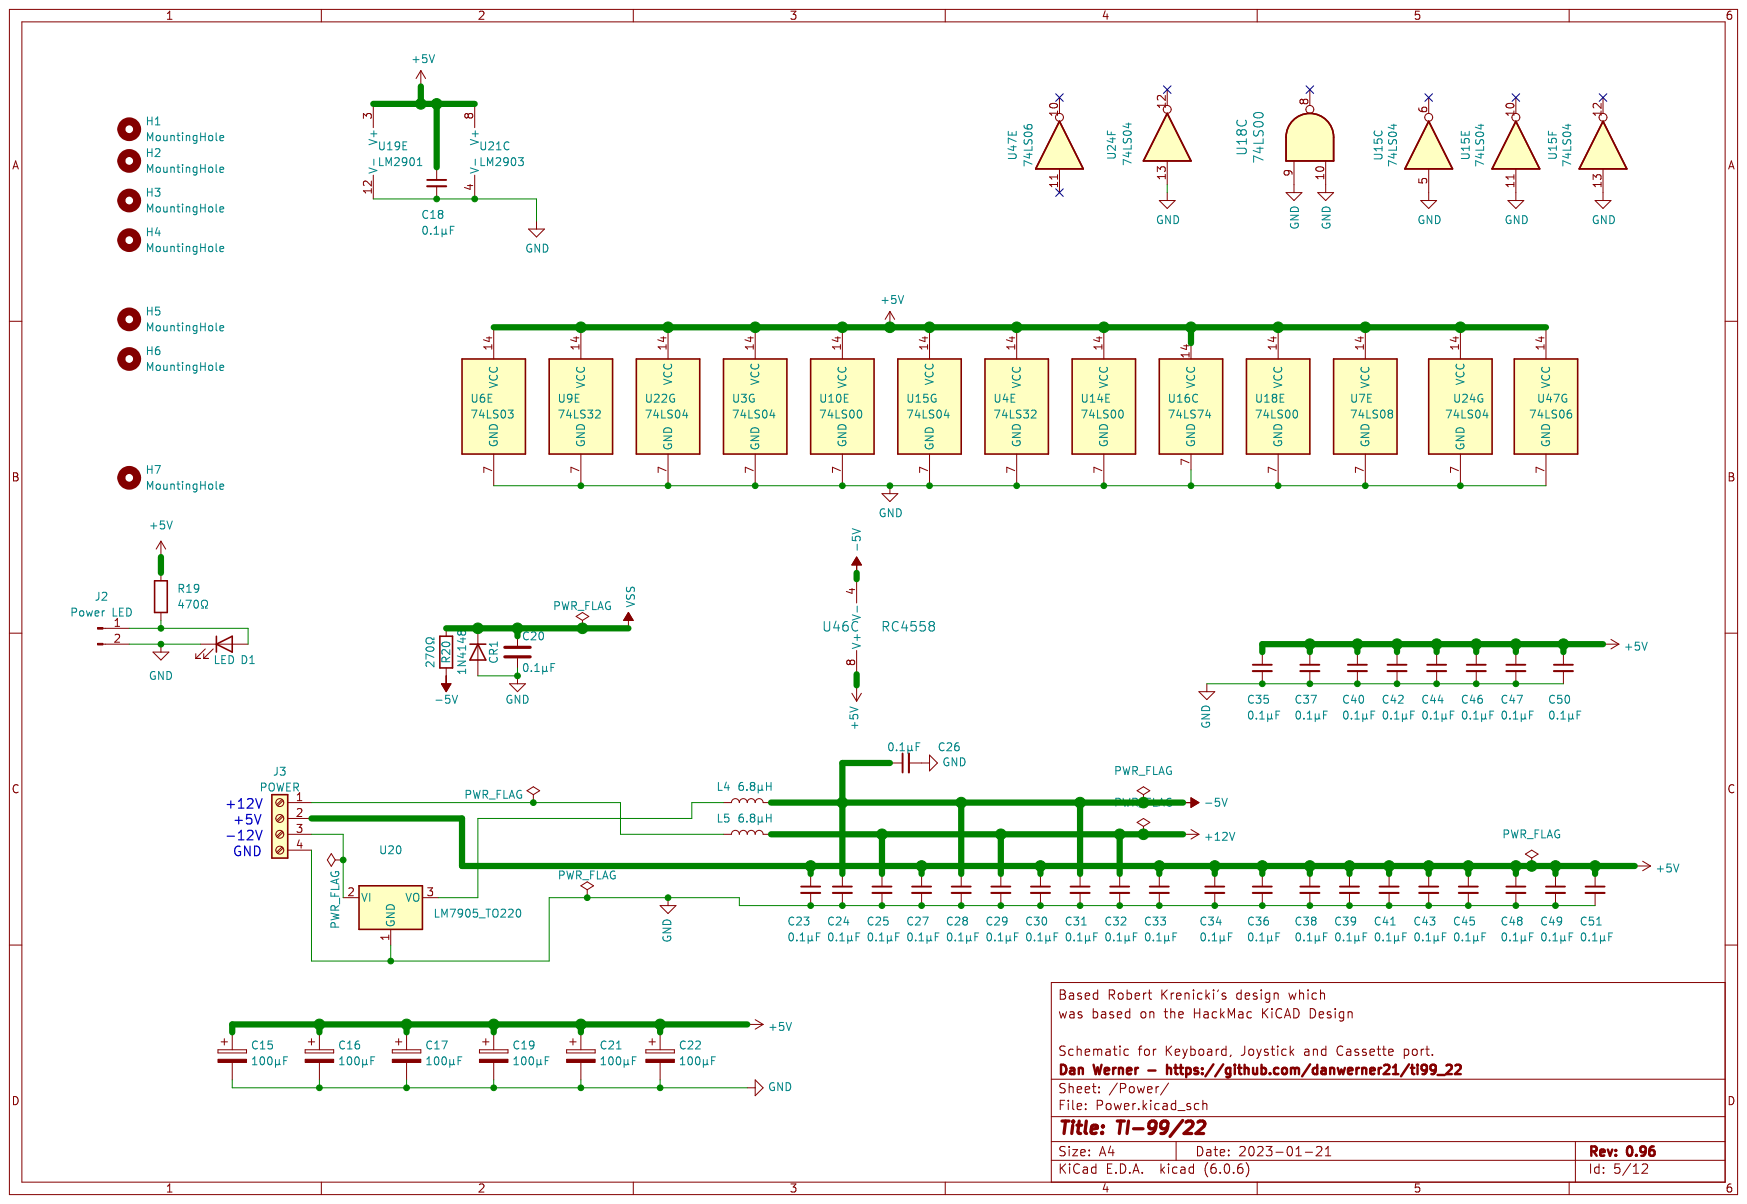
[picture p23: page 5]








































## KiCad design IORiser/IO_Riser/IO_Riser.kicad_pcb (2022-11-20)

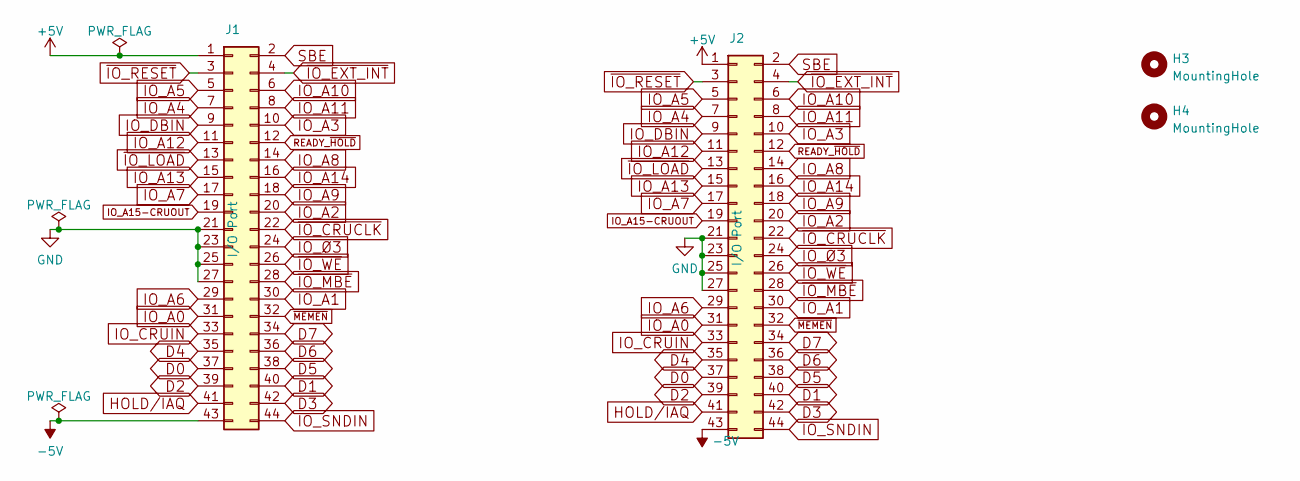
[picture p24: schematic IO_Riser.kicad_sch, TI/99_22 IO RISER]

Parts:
H3, H4: MountingHole; MountingHole_3.2mm_M3
J1: I/O Port; PinHeader_2x22_P2.54mm_Vertical
J2: I/O Port; 44 Pin Card Edge

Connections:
+5V: J1.1, J2.1
-5V: J1.43, J2.43
D0: J1.37, J2.37
D1: J1.40, J2.40
D2: J1.39, J2.39
D3: J1.42, J2.42
D4: J1.35, J2.35
D5: J1.38, J2.38
D6: J1.36, J2.36
D7: J1.34, J2.34
GND: J1.21, J1.23, J1.25, J1.27, J2.21, J2.23, J2.25, J2.27
HOLD/IAQ: J1.41, J2.41
IO_A0: J1.31, J2.31
IO_A1: J1.30, J2.30
IO_A2: J1.20, J2.20
IO_A3: J1.10, J2.10
IO_A4: J1.7, J2.7
IO_A5: J1.5, J2.5
IO_A6: J1.29, J2.29
IO_A7: J1.17, J2.17
IO_A8: J1.14, J2.14
IO_A9: J1.18, J2.18
IO_A10: J1.6, J2.6
IO_A11: J1.8, J2.8
IO_A12: J1.11, J2.11
IO_A13: J1.15, J2.15
IO_A14: J1.16, J2.16
IO_A15-CRUOUT: J1.19, J2.19
IO_CRUIN: J1.33, J2.33
IO_DBIN: J1.9, J2.9
IO_SNDIN: J1.44, J2.44
IO_Ø3: J1.24, J2.24
READY_~HOLD: J1.12, J2.12
SBE: J1.2, J2.2
~IO_CRUCLK: J1.22, J2.22
~IO_EXT_INT: J1.4, J2.4
~IO_LOAD: J1.13, J2.13
~IO_MBE: J1.28, J2.28
~IO_RESET: J1.3, J2.3
~IO_WE: J1.26, J2.26
~MEMEN: J1.32, J2.32

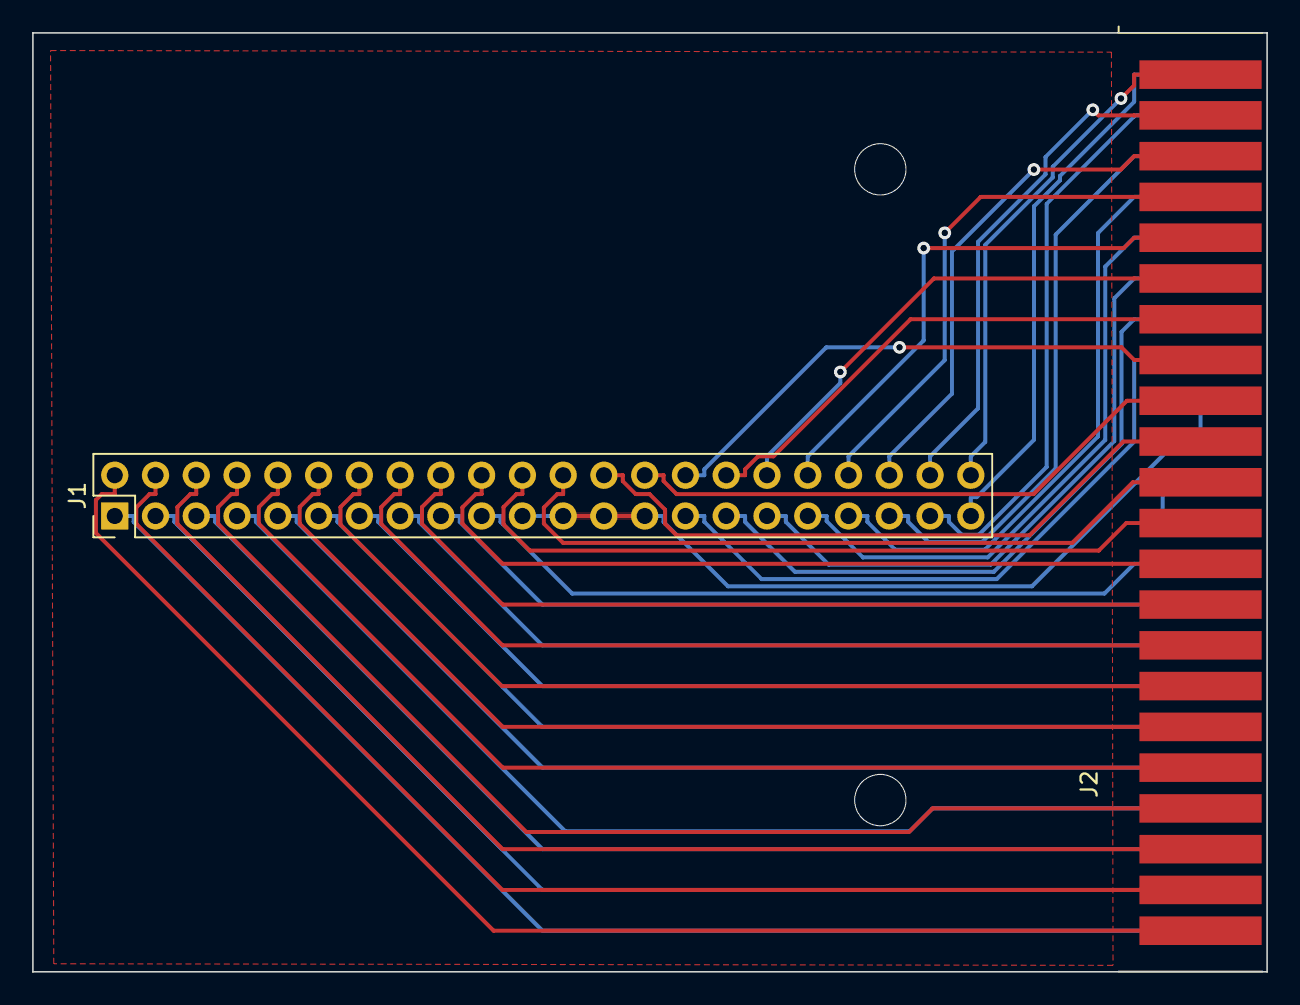
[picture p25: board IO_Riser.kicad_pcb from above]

Board: 2 copper layers, 76.9 x 58.5 mm, 4 parts (0 on the bottom side), 41 nets.

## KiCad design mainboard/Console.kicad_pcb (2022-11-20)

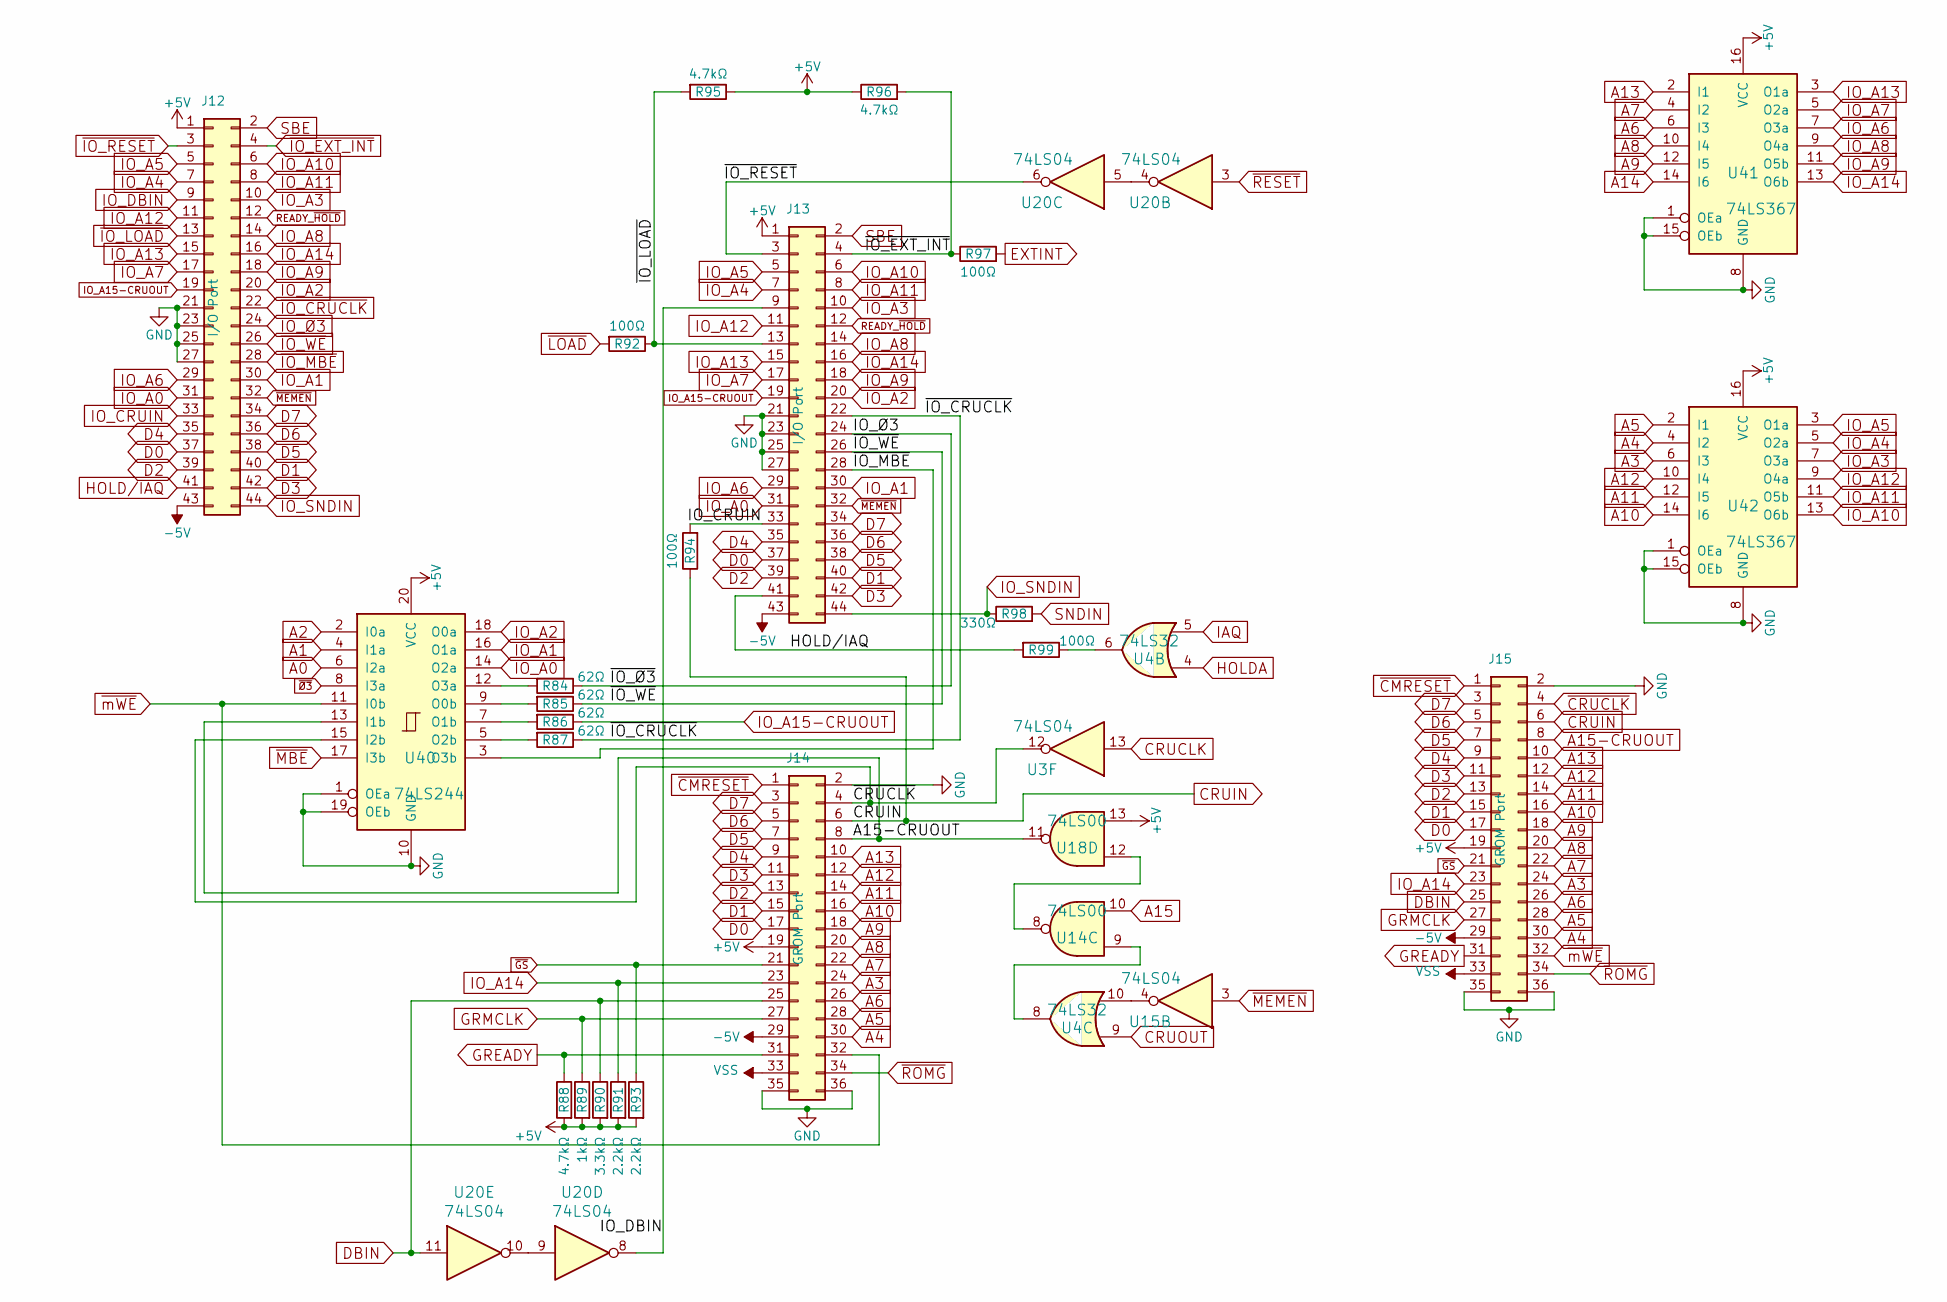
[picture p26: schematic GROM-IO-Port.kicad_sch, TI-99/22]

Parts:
J12: I/O Port; PinHeader_2x22_P2.54mm_Vertical
J13: I/O Port; 44 Pin Card Edge
J14: GROM Port; CardEdge_34Pin_2.54mm_Vertical
J15: GROM Port; PinHeader_2x18_P2.54mm_Vertical
R84, R85, R86, R87: 62Ω; R_Axial_DIN0207_L6.3mm_D2.5mm_P7.62mm_Horizontal
R88, R95, R96: 4.7kΩ; R_Axial_DIN0207_L6.3mm_D2.5mm_P7.62mm_Horizontal
R89: 1kΩ; R_Axial_DIN0207_L6.3mm_D2.5mm_P7.62mm_Horizontal
R90: 3.3kΩ; R_Axial_DIN0207_L6.3mm_D2.5mm_P7.62mm_Horizontal
R91, R93: 2.2kΩ; R_Axial_DIN0207_L6.3mm_D2.5mm_P7.62mm_Horizontal
R92, R94, R97, R99: 100Ω; R_Axial_DIN0207_L6.3mm_D2.5mm_P7.62mm_Horizontal
R98: 330Ω; R_Axial_DIN0207_L6.3mm_D2.5mm_P7.62mm_Horizontal
U3, U15, U20: 74LS04; DIP-14_W7.62mm_Socket_LongPads
U4: 74LS32; DIP-14_W7.62mm_Socket_LongPads
U14, U18: 74LS00; DIP-14_W7.62mm_Socket_LongPads
U40: 74LS244; DIP-20_W7.62mm_Socket_LongPads
U41, U42: 74LS367; DIP-16_W7.62mm_Socket_LongPads

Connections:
+5V: J12.1, J13.1, J14.19, J15.19, R88.2, R89.2, R90.2, R91.2, R93.2, R95.1, R96.1, U18.13, U40.20 (VCC), U41.16 (VCC), U42.16 (VCC); also elsewhere on the board
-5V: J12.43, J13.43, J14.29, J15.29; also elsewhere on the board
A0: U40.6 (I2a); also elsewhere on the board
A1: U40.4 (I1a); also elsewhere on the board
A2: U40.2 (I0a); also elsewhere on the board
A3: J14.24, J15.24, U42.6 (I3); also elsewhere on the board
A4: J14.30, J15.30, U42.4 (I2); also elsewhere on the board
A5: J14.28, J15.28, U42.2 (I1); also elsewhere on the board
A6: J14.26, J15.26, U41.6 (I3); also elsewhere on the board
A7: J14.22, J15.22, U41.4 (I2); also elsewhere on the board
A8: J14.20, J15.20, U41.10 (I4); also elsewhere on the board
A9: J14.18, J15.18, U41.12 (I5); also elsewhere on the board
A10: J14.16, J15.16, U42.14 (I6); also elsewhere on the board
A11: J14.14, J15.14, U42.12 (I5); also elsewhere on the board
A12: J14.12, J15.12, U42.10 (I4); also elsewhere on the board
A13: J14.10, J15.10, U41.2 (I1); also elsewhere on the board
A14: U41.14 (I6); also elsewhere on the board
A15: U14.10; also elsewhere on the board
A15-CRUOUT: J14.8, J15.8, U18.11, U40.13 (I1b); also elsewhere on the board
CRUCLK: U3.13; also elsewhere on the board
CRUIN: J14.6, J15.6, R94.1; also elsewhere on the board
CRUOUT: U4.9; also elsewhere on the board
D0: J12.37, J13.37, J14.17, J15.17; also elsewhere on the board
D1: J12.40, J13.40, J14.15, J15.15; also elsewhere on the board
D2: J12.39, J13.39, J14.13, J15.13; also elsewhere on the board
D3: J12.42, J13.42, J14.11, J15.11; also elsewhere on the board
D4: J12.35, J13.35, J14.9, J15.9; also elsewhere on the board
D5: J12.38, J13.38, J14.7, J15.7; also elsewhere on the board
D6: J12.36, J13.36, J14.5, J15.5; also elsewhere on the board
D7: J12.34, J13.34, J14.3, J15.3; also elsewhere on the board
DBIN: J14.25, J15.25, R90.1, U20.11; also elsewhere on the board
EXTINT: R97.2; also elsewhere on the board
GREADY: J14.31, J15.31, R88.1; also elsewhere on the board
GRMCLK: J14.27, J15.27, R89.1; also elsewhere on the board
HOLDA: U4.4; also elsewhere on the board
IAQ: U4.5; also elsewhere on the board
IO_A0: J12.31, J13.31, U40.14 (O2a)
IO_A1: J12.30, J13.30, U40.16 (O1a)
IO_A2: J12.20, J13.20, U40.18 (O0a)
IO_A3: J12.10, J13.10, U42.7 (O3a); also elsewhere on the board
IO_A4: J12.7, J13.7, U42.5 (O2a); also elsewhere on the board
IO_A5: J12.5, J13.5, U42.3 (O1a); also elsewhere on the board
IO_A6: J12.29, J13.29, U41.7 (O3a)
IO_A7: J12.17, J13.17, U41.5 (O2a)
IO_A8: J12.14, J13.14, U41.9 (O4a)
IO_A9: J12.18, J13.18, U41.11 (O5b)
IO_A10: J12.6, J13.6, U42.13 (O6b)
IO_A11: J12.8, J13.8, U42.11 (O5b)
IO_A12: J12.11, J13.11, U42.9 (O4a)
IO_A13: J12.15, J13.15, U41.3 (O1a)
IO_A14: J12.16, J13.16, J14.23, J15.23, R91.1, U41.13 (O6b); also elsewhere on the board
IO_A15-CRUOUT: J12.19, J13.19, R86.1
IO_CRUIN: J12.33, J13.33, R94.2
IO_DBIN: J12.9, J13.9, U20.8
IO_SNDIN: J12.44, J13.44, R98.1
IO_Ø3: J12.24, J13.24, R84.1
unnamed: R84.2, U40.12 (O3a)
unnamed: R85.2, U40.9 (O0b)
unnamed: R86.2, U40.7 (O1b)
unnamed: R87.2, U40.5 (O2b)
unnamed: R99.1, U4.6
unnamed: U14.8, U18.12
unnamed: U4.8, U14.9
unnamed: U4.10, U15.4
unnamed: U20.4, U20.5
unnamed: U20.9, U20.10
READY_~HOLD: J12.12, J13.12; also elsewhere on the board
SBE: J12.2, J13.2; also elsewhere on the board
SNDIN: R98.2; also elsewhere on the board
VRAM_BANK: J12.21, J12.23, J12.25, J12.27, J13.21, J13.23, J13.25, J13.27, J14.2, J14.35, J14.36, J15.2, J15.35, J15.36, U40.1 (OEa), U40.10 (GND), U40.19 (OEb), U41.1 (OEa), U41.8 (GND), U41.15 (OEb), U42.1 (OEa), U42.8 (GND), U42.15 (OEb); also elsewhere on the board
VSS: J14.33, J15.33; also elsewhere on the board
~CMRESET: J14.1, J15.1; also elsewhere on the board
~CRUCLK: J14.4, J15.4, U3.12, U40.15 (I2b)
~GS: J14.21, J15.21, R93.1; also elsewhere on the board
~IO_CRUCLK: J12.22, J13.22, R87.1
~IO_EXT_INT: J12.4, J13.4, R96.2, R97.1
~IO_LOAD: J12.13, J13.13, R92.1, R95.2
~IO_MBE: J12.28, J13.28, U40.3 (O3b)
~IO_RESET: J12.3, J13.3, U20.6
~IO_WE: J12.26, J13.26, R85.1
~LOAD: R92.2; also elsewhere on the board
~MBE: U40.17 (I3b); also elsewhere on the board
~MEMEN: J12.32, J13.32, U15.3; also elsewhere on the board
~RESET: U20.3; also elsewhere on the board
~ROMG: J14.34, J15.34; also elsewhere on the board
~mWE: J14.32, J15.32, U40.11 (I0b); also elsewhere on the board
~Ø3: U40.8 (I3a); also elsewhere on the board

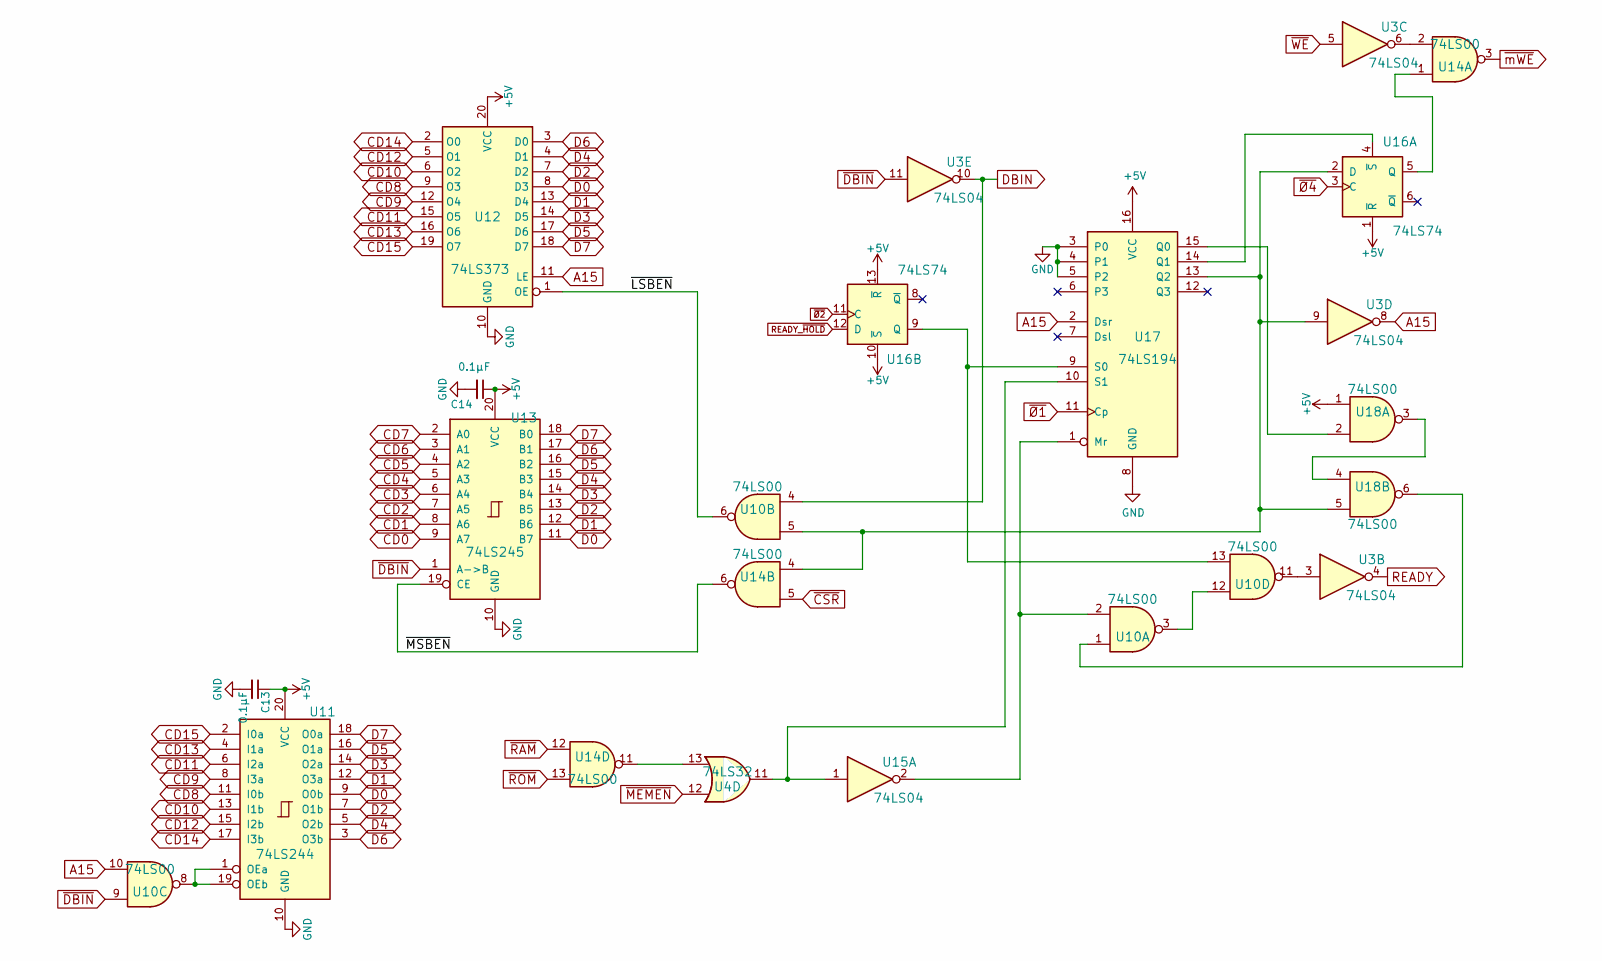
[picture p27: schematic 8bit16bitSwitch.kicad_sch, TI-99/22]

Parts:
C13, C14: 0.1µF; C_Rect_L7.0mm_W2.0mm_P5.00mm
U3, U15: 74LS04; DIP-14_W7.62mm_Socket_LongPads
U4: 74LS32; DIP-14_W7.62mm_Socket_LongPads
U10, U14, U18: 74LS00; DIP-14_W7.62mm_Socket_LongPads
U11: 74LS244; DIP-20_W7.62mm_Socket_LongPads
U12: 74LS373; DIP-20_W7.62mm_Socket_LongPads
U13: 74LS245; DIP-20_W7.62mm_Socket_LongPads
U16: 74LS74; DIP-14_W7.62mm_Socket_LongPads
U17: 74LS194; DIP-16_W7.62mm_Socket_LongPads

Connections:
+5V: C13.1, C14.1, U11.20 (VCC), U12.20 (VCC), U13.20 (VCC), U16.1 (~R), U16.10 (~S), U16.13 (~R), U17.16 (VCC), U18.1; also elsewhere on the board
/8Bit16BitSwitch/~LSBEN: U10.6, U12.1 (OE)
/8Bit16BitSwitch/~MSBEN: U13.19 (CE), U14.6
A15: U3.8, U10.10, U12.11 (LE), U17.2 (Dsr); also elsewhere on the board
CD0: U13.9 (A7); also elsewhere on the board
CD1: U13.8 (A6); also elsewhere on the board
CD2: U13.7 (A5); also elsewhere on the board
CD3: U13.6 (A4); also elsewhere on the board
CD4: U13.5 (A3); also elsewhere on the board
CD5: U13.4 (A2); also elsewhere on the board
CD6: U13.3 (A1); also elsewhere on the board
CD7: U13.2 (A0); also elsewhere on the board
CD8: U11.11 (I0b), U12.9 (O3); also elsewhere on the board
CD9: U11.8 (I3a), U12.12 (O4); also elsewhere on the board
CD10: U11.13 (I1b), U12.6 (O2); also elsewhere on the board
CD11: U11.6 (I2a), U12.15 (O5); also elsewhere on the board
CD12: U11.15 (I2b), U12.5 (O1); also elsewhere on the board
CD13: U11.4 (I1a), U12.16 (O6); also elsewhere on the board
CD14: U11.17 (I3b), U12.2 (O0); also elsewhere on the board
CD15: U11.2 (I0a), U12.19 (O7); also elsewhere on the board
D0: U11.9 (O0b), U12.8 (D3), U13.11 (B7); also elsewhere on the board
D1: U11.12 (O3a), U12.13 (D4), U13.12 (B6); also elsewhere on the board
D2: U11.7 (O1b), U12.7 (D2), U13.13 (B5); also elsewhere on the board
D3: U11.14 (O2a), U12.14 (D5), U13.14 (B4); also elsewhere on the board
D4: U11.5 (O2b), U12.4 (D1), U13.15 (B3); also elsewhere on the board
D5: U11.16 (O1a), U12.17 (D6), U13.16 (B2); also elsewhere on the board
D6: U11.3 (O3b), U12.3 (D0), U13.17 (B1); also elsewhere on the board
D7: U11.18 (O0a), U12.18 (D7), U13.18 (B0); also elsewhere on the board
DBIN: U3.10, U10.4; also elsewhere on the board
unnamed: U10.1, U18.6
unnamed: U10.2, U15.2, U17.1 (Mr)
unnamed: U3.9, U10.5, U14.4, U16.2 (D), U17.13 (Q2), U18.5
unnamed: U10.8, U11.1 (OEa), U11.19 (OEb)
unnamed: U3.3, U10.11
unnamed: U10.3, U10.12
unnamed: U10.13, U16.9 (Q), U17.9 (S0)
unnamed: U14.1, U16.5 (Q)
unnamed: U3.6, U14.2
unnamed: U4.13, U14.11
unnamed: U4.11, U15.1, U17.10 (S1)
unnamed: U16.4 (~S), U17.14 (Q1)
unnamed: U17.15 (Q0), U18.2
unnamed: U18.3, U18.4
READY: U3.4; also elsewhere on the board
READY_~HOLD: U16.12 (D); also elsewhere on the board
VRAM_BANK: C13.2, C14.2, U11.10 (GND), U12.10 (GND), U13.10 (GND), U17.3 (P0), U17.4 (P1), U17.5 (P2), U17.8 (GND); also elsewhere on the board
~CSR: U14.5; also elsewhere on the board
~DBIN: U3.11, U10.9, U13.1 (A->B); also elsewhere on the board
~MEMEN: U4.12; also elsewhere on the board
~RAM: U14.12; also elsewhere on the board
~ROM: U14.13; also elsewhere on the board
~WE: U3.5; also elsewhere on the board
~mWE: U14.3; also elsewhere on the board
~Ø1: U17.11 (Cp); also elsewhere on the board
~Ø2: U16.11 (C); also elsewhere on the board
~Ø4: U16.3 (C); also elsewhere on the board

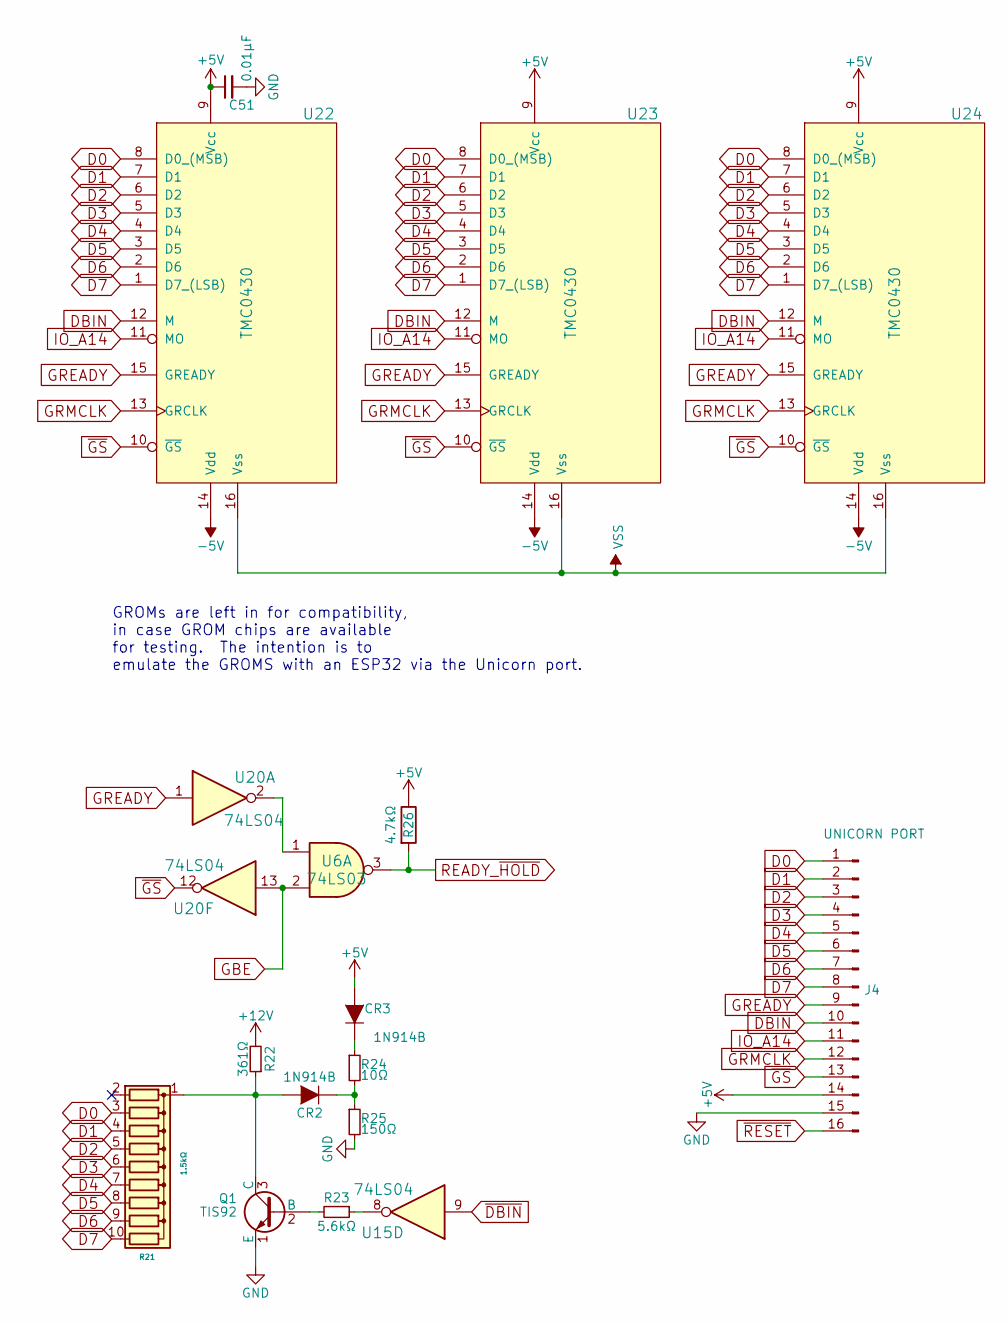
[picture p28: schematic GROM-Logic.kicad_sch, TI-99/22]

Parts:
C51: 0.01µF; C_Rect_L7.0mm_W2.0mm_P5.00mm
CR2, CR3: 1N914B; D_A-405_P7.62mm_Horizontal
J4: UNICORN PORT; PinHeader_1x16_P2.54mm_Vertical
Q1: TIS92; TO-92_HandSolder
R21: 1.5kΩ; R_Array_SIP10
R22: 361Ω; R_Axial_DIN0207_L6.3mm_D2.5mm_P7.62mm_Horizontal
R23: 5.6kΩ; R_Axial_DIN0207_L6.3mm_D2.5mm_P7.62mm_Horizontal
R24: 10Ω; R_Axial_DIN0207_L6.3mm_D2.5mm_P7.62mm_Horizontal
R25: 150Ω; R_Axial_DIN0207_L6.3mm_D2.5mm_P7.62mm_Horizontal
R26: 4.7kΩ; R_Axial_DIN0207_L6.3mm_D2.5mm_P7.62mm_Horizontal
U6: 74LS03; DIP-14_W7.62mm_Socket_LongPads
U15, U20: 74LS04; DIP-14_W7.62mm_Socket_LongPads
U22, U23, U24: TMC0430; DIP-16_W7.62mm_Socket_LongPads

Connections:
+5V: C51.1, CR3.2 (A), J4.14, R26.1, U22.9 (Vcc), U23.9 (Vcc), U24.9 (Vcc); also elsewhere on the board
+12V: R22.2; also elsewhere on the board
-5V: U22.14 (Vdd), U23.14 (Vdd), U24.14 (Vdd); also elsewhere on the board
D0: J4.1, R21.3 (R2), U22.8 (D0_(MSB)), U23.8 (D0_(MSB)), U24.8 (D0_(MSB)); also elsewhere on the board
D1: J4.2, R21.4 (R3), U22.7 (D1), U23.7 (D1), U24.7 (D1); also elsewhere on the board
D2: J4.3, R21.5 (R4), U22.6 (D2), U23.6 (D2), U24.6 (D2); also elsewhere on the board
D3: J4.4, R21.6 (R5), U22.5 (D3), U23.5 (D3), U24.5 (D3); also elsewhere on the board
D4: J4.5, R21.7 (R6), U22.4 (D4), U23.4 (D4), U24.4 (D4); also elsewhere on the board
D5: J4.6, R21.8 (R7), U22.3 (D5), U23.3 (D5), U24.3 (D5); also elsewhere on the board
D6: J4.7, R21.9 (R8), U22.2 (D6), U23.2 (D6), U24.2 (D6); also elsewhere on the board
D7: J4.8, R21.10 (R9), U22.1 (D7_(LSB)), U23.1 (D7_(LSB)), U24.1 (D7_(LSB)); also elsewhere on the board
DBIN: J4.10, U22.12 (M), U23.12 (M), U24.12 (M); also elsewhere on the board
GBE: U6.2, U20.13; also elsewhere on the board
GREADY: J4.9, U20.1, U22.15 (GREADY), U23.15 (GREADY), U24.15 (GREADY); also elsewhere on the board
GRMCLK: J4.12, U22.13 (GRCLK), U23.13 (GRCLK), U24.13 (GRCLK); also elsewhere on the board
IO_A14: J4.11, U22.11 (MO), U23.11 (MO), U24.11 (MO); also elsewhere on the board
unnamed: CR2.1 (K), R24.2, R25.1
unnamed: CR2.2 (A), Q1.3 (C), R21.1 (common), R22.1
unnamed: CR3.1 (K), R24.1
unnamed: Q1.2 (B), R23.2
unnamed: R23.1, U15.8
unnamed: U6.1, U20.2
READY_~HOLD: R26.2, U6.3; also elsewhere on the board
VRAM_BANK: C51.2, J4.15, Q1.1 (E), R25.2; also elsewhere on the board
VSS: U22.16 (Vss), U23.16 (Vss), U24.16 (Vss); also elsewhere on the board
~DBIN: U15.9; also elsewhere on the board
~GS: J4.13, U20.12, U22.10 (~GS), U23.10 (~GS), U24.10 (~GS); also elsewhere on the board
~RESET: J4.16; also elsewhere on the board

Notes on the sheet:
GROMs are left in for compatibility, in case GROM chips are available for testing. The intention is to emulate the GROMS with an ESP32 via the Unicorn port.

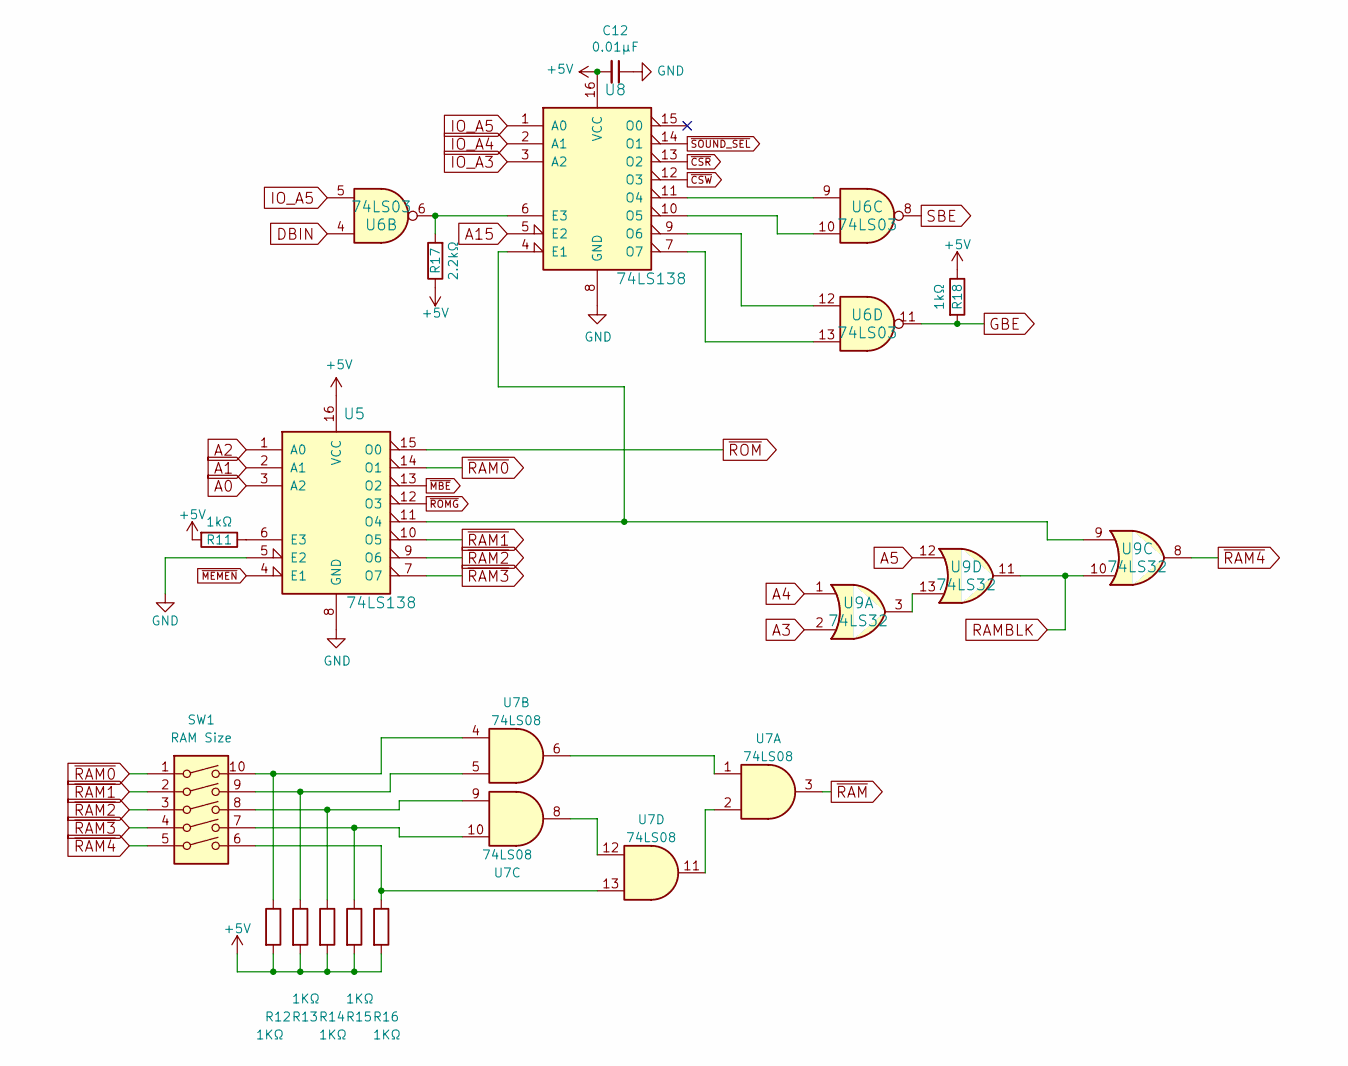
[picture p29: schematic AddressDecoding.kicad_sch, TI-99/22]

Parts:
C12: 0.01µF; C_Rect_L7.0mm_W2.0mm_P5.00mm
R11, R18: 1kΩ; R_Axial_DIN0207_L6.3mm_D2.5mm_P7.62mm_Horizontal
R12, R13, R14, R15, R16: 1KΩ; R_Axial_DIN0207_L6.3mm_D2.5mm_P7.62mm_Horizontal
R17: 2.2kΩ; R_Axial_DIN0207_L6.3mm_D2.5mm_P7.62mm_Horizontal
SW1: RAM Size; DIP-10_W7.62mm_Socket_LongPads
U5, U8: 74LS138; DIP-16_W7.62mm_Socket_LongPads
U6: 74LS03; DIP-14_W7.62mm_Socket_LongPads
U7: 74LS08; DIP-14_W7.62mm_Socket_LongPads
U9: 74LS32; DIP-14_W7.62mm_Socket_LongPads

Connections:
+5V: C12.2, R11.2, R12.2, R13.2, R14.2, R15.2, R16.2, R17.1, R18.1, U5.16 (VCC), U8.16 (VCC); also elsewhere on the board
A0: U5.3 (A2); also elsewhere on the board
A1: U5.2 (A1); also elsewhere on the board
A2: U5.1 (A0); also elsewhere on the board
A3: U9.2; also elsewhere on the board
A4: U9.1; also elsewhere on the board
A5: U9.12; also elsewhere on the board
A15: U8.5 (E2); also elsewhere on the board
DBIN: U6.4; also elsewhere on the board
GBE: R18.2, U6.11; also elsewhere on the board
IO_A3: U8.3 (A2); also elsewhere on the board
IO_A4: U8.2 (A1); also elsewhere on the board
IO_A5: U6.5, U8.1 (A0); also elsewhere on the board
unnamed: R11.1, U5.6 (E3)
unnamed: R12.1, SW1.10, U7.4
unnamed: R13.1, SW1.9, U7.5
unnamed: R14.1, SW1.8, U7.9
unnamed: R15.1, SW1.7, U7.10
unnamed: R16.1, SW1.6, U7.13
unnamed: R17.2, U6.6, U8.6 (E3)
unnamed: U5.11 (O4), U8.4 (E1), U9.9
unnamed: U6.9, U8.11 (O4)
unnamed: U6.10, U8.10 (O5)
unnamed: U6.12, U8.9 (O6)
unnamed: U6.13, U8.7 (O7)
unnamed: U7.1, U7.6
unnamed: U7.2, U7.11
unnamed: U7.8, U7.12
unnamed: U9.3, U9.13
RAMBLK: U9.10, U9.11; also elsewhere on the board
SBE: U6.8; also elsewhere on the board
VRAM_BANK: C12.1, U5.5 (E2), U5.8 (GND), U8.8 (GND); also elsewhere on the board
~CSR: U8.13 (O2); also elsewhere on the board
~CSW: U8.12 (O3); also elsewhere on the board
~MBE: U5.13 (O2); also elsewhere on the board
~MEMEN: U5.4 (E1); also elsewhere on the board
~RAM0: SW1.1, U5.14 (O1)
~RAM1: SW1.2, U5.10 (O5)
~RAM2: SW1.3, U5.9 (O6)
~RAM3: SW1.4, U5.7 (O7)
~RAM4: SW1.5, U9.8
~RAM: U7.3; also elsewhere on the board
~ROMG: U5.12 (O3); also elsewhere on the board
~ROM: U5.15 (O0); also elsewhere on the board
~SOUND_SEL: U8.14 (O1); also elsewhere on the board

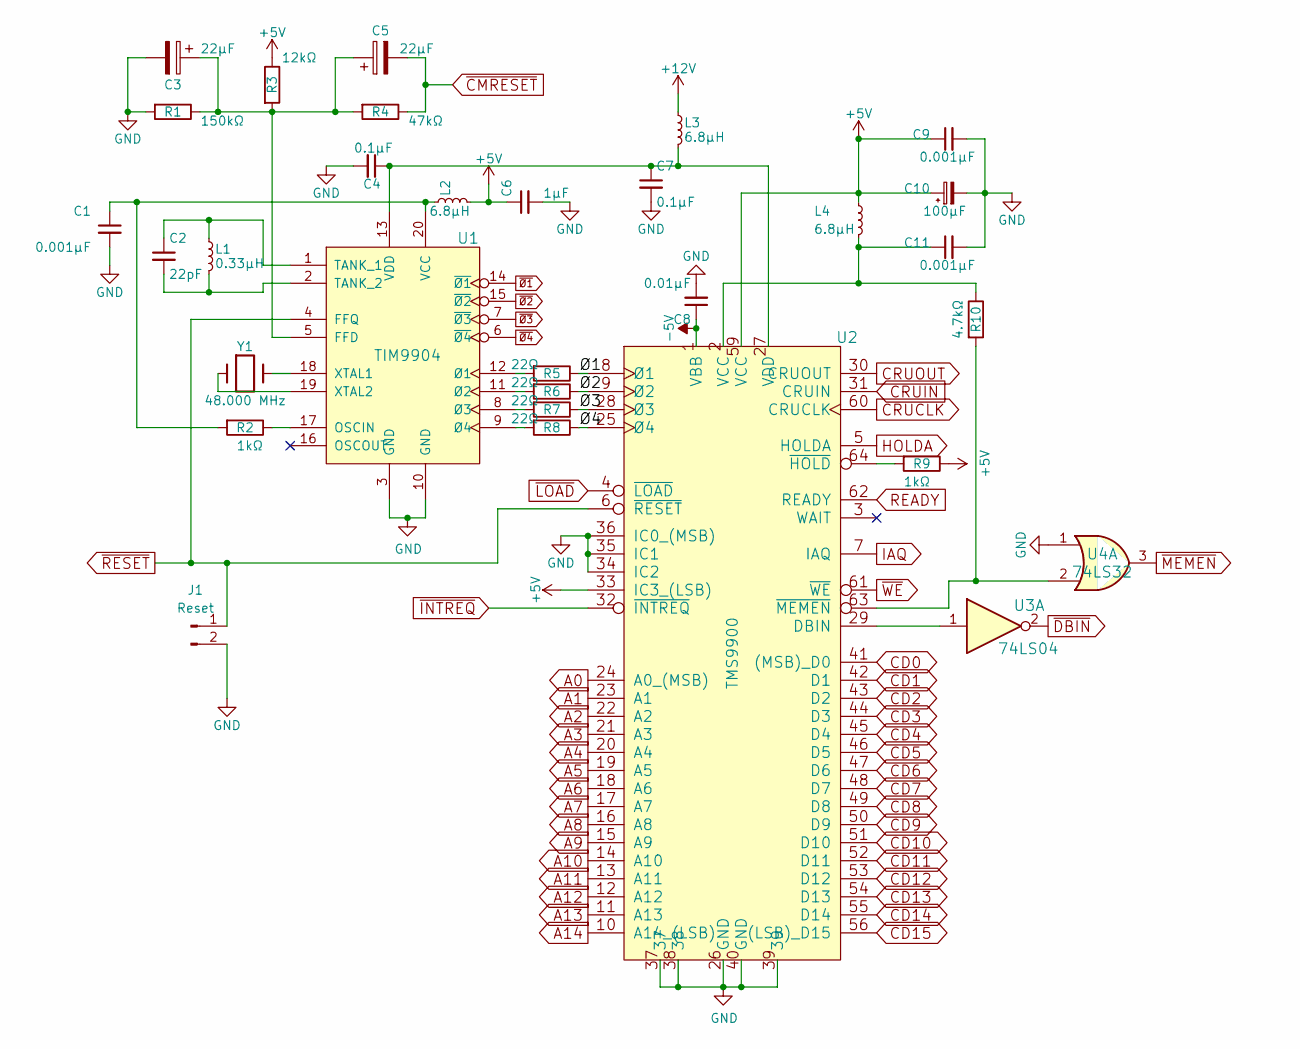
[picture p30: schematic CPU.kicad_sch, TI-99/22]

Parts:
C1, C9, C11: 0.001µF; C_Rect_L7.0mm_W2.0mm_P5.00mm
C2: 22pF; C_Rect_L7.0mm_W2.0mm_P5.00mm
C3, C5: 22µF; CP_Radial_D7.5mm_P2.50mm
C4, C7: 0.1µF; C_Rect_L7.0mm_W2.0mm_P5.00mm
C6: 1µF; C_Rect_L7.0mm_W2.0mm_P5.00mm
C8: 0.01µF; C_Rect_L7.0mm_W2.0mm_P5.00mm
C10: 100µF; CP_Radial_D7.5mm_P2.50mm
J1: Reset; PinHeader_1x02_P2.54mm_Vertical
L1: 0.33µH; R_Axial_DIN0207_L6.3mm_D2.5mm_P7.62mm_Horizontal
L2, L3, L4: 6.8µH; R_Axial_DIN0207_L6.3mm_D2.5mm_P7.62mm_Horizontal
R1: 150kΩ; R_Axial_DIN0207_L6.3mm_D2.5mm_P7.62mm_Horizontal
R2, R9: 1kΩ; R_Axial_DIN0207_L6.3mm_D2.5mm_P7.62mm_Horizontal
R3: 12kΩ; R_Axial_DIN0207_L6.3mm_D2.5mm_P7.62mm_Horizontal
R4: 47kΩ; R_Axial_DIN0207_L6.3mm_D2.5mm_P7.62mm_Horizontal
R5, R6, R7, R8: 22Ω; R_Axial_DIN0207_L6.3mm_D2.5mm_P7.62mm_Horizontal
R10: 4.7kΩ; R_Axial_DIN0207_L6.3mm_D2.5mm_P7.62mm_Horizontal
U1: TIM9904; DIP-20_W7.62mm_Socket_LongPads
U2: TMS9900; DIP-64_W22.86mm_Socket_LongPads
U3: 74LS04; DIP-14_W7.62mm_Socket_LongPads
U4: 74LS32; DIP-14_W7.62mm_Socket_LongPads
Y1: 48.000 MHz; Crystal_HC49-U_Vertical

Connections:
+5V: C6.1, C9.1, C10.1, L2.2, L4.1, R3.1, R9.1, U2.33 (IC3_(LSB)), U2.59 (VCC); also elsewhere on the board
+12V: L3.1; also elsewhere on the board
-5V: C8.1, U2.1 (VBB); also elsewhere on the board
/CPU/Ø1: R5.1, U2.8 (Ø1)
/CPU/Ø2: R6.1, U2.9 (Ø2)
/CPU/Ø3: R7.1, U2.28 (Ø3)
/CPU/Ø4: R8.1, U2.25 (Ø4)
A0: U2.24 (A0_(MSB)); also elsewhere on the board
A1: U2.23 (A1); also elsewhere on the board
A2: U2.22 (A2); also elsewhere on the board
A3: U2.21 (A3); also elsewhere on the board
A4: U2.20 (A4); also elsewhere on the board
A5: U2.19 (A5); also elsewhere on the board
A6: U2.18 (A6); also elsewhere on the board
A7: U2.17 (A7); also elsewhere on the board
A8: U2.16 (A8); also elsewhere on the board
A9: U2.15 (A9); also elsewhere on the board
A10: U2.14 (A10); also elsewhere on the board
A11: U2.13 (A11); also elsewhere on the board
A12: U2.12 (A12); also elsewhere on the board
A13: U2.11 (A13); also elsewhere on the board
A14: U2.10 (A14_(LSB)); also elsewhere on the board
CD0: U2.41 ((MSB)_D0); also elsewhere on the board
CD1: U2.42 (D1); also elsewhere on the board
CD2: U2.43 (D2); also elsewhere on the board
CD3: U2.44 (D3); also elsewhere on the board
CD4: U2.45 (D4); also elsewhere on the board
CD5: U2.46 (D5); also elsewhere on the board
CD6: U2.47 (D6); also elsewhere on the board
CD7: U2.48 (D7); also elsewhere on the board
CD8: U2.49 (D8); also elsewhere on the board
CD9: U2.50 (D9); also elsewhere on the board
CD10: U2.51 (D10); also elsewhere on the board
CD11: U2.52 (D11); also elsewhere on the board
CD12: U2.53 (D12); also elsewhere on the board
CD13: U2.54 (D13); also elsewhere on the board
CD14: U2.55 (D14); also elsewhere on the board
CD15: U2.56 ((LSB)_D15); also elsewhere on the board
CRUCLK: U2.60 (CRUCLK); also elsewhere on the board
CRUIN: U2.31 (CRUIN); also elsewhere on the board
CRUOUT: U2.30 (CRUOUT); also elsewhere on the board
HOLDA: U2.5 (HOLDA); also elsewhere on the board
IAQ: U2.7 (IAQ); also elsewhere on the board
unnamed: C1.1, L2.1, R2.2, U1.20 (VCC)
unnamed: C2.1, L1.1, U1.1 (TANK_1)
unnamed: C2.2, L1.2, U1.2 (TANK_2)
unnamed: C3.1, C5.1, R1.1, R3.2, R4.2, U1.5 (FFD)
unnamed: C4.1, C7.1, L3.2, U1.13 (VDD), U2.27 (VDD)
unnamed: C11.1, L4.2, R10.1, U2.2 (VCC)
unnamed: R2.1, U1.17 (OSCIN)
unnamed: R5.2, U1.12 (Ø1)
unnamed: R6.2, U1.11 (Ø2)
unnamed: R7.2, U1.8 (Ø3)
unnamed: R8.2, U1.9 (Ø4)
unnamed: R9.2, U2.64 (~HOLD)
unnamed: R10.2, U2.63 (~MEMEN), U4.2
unnamed: U1.18 (XTAL1), Y1.2
unnamed: U1.19 (XTAL2), Y1.1
unnamed: U2.29 (DBIN), U3.1
READY: U2.62 (READY); also elsewhere on the board
VRAM_BANK: C1.2, C3.2, C4.2, C6.2, C7.2, C8.2, C9.2, C10.2, C11.2, J1.2, R1.2, U1.3 (GND), U1.10 (GND), U2.26 (GND), U2.34 (IC2), U2.35 (IC1), U2.36 (IC0_(MSB)), U2.37, U2.38, U2.39, U2.40 (GND), U4.1; also elsewhere on the board
~CMRESET: C5.2, R4.1; also elsewhere on the board
~DBIN: U3.2; also elsewhere on the board
~INTREQ: U2.32 (~INTREQ); also elsewhere on the board
~LOAD: U2.4 (~LOAD); also elsewhere on the board
~MEMEN: U4.3; also elsewhere on the board
~RESET: J1.1, U1.4 (FFQ), U2.6 (~RESET); also elsewhere on the board
~WE: U2.61 (~WE); also elsewhere on the board
~Ø1: U1.14 (~Ø1); also elsewhere on the board
~Ø2: U1.15 (~Ø2); also elsewhere on the board
~Ø3: U1.7 (~Ø3); also elsewhere on the board
~Ø4: U1.6 (~Ø4); also elsewhere on the board

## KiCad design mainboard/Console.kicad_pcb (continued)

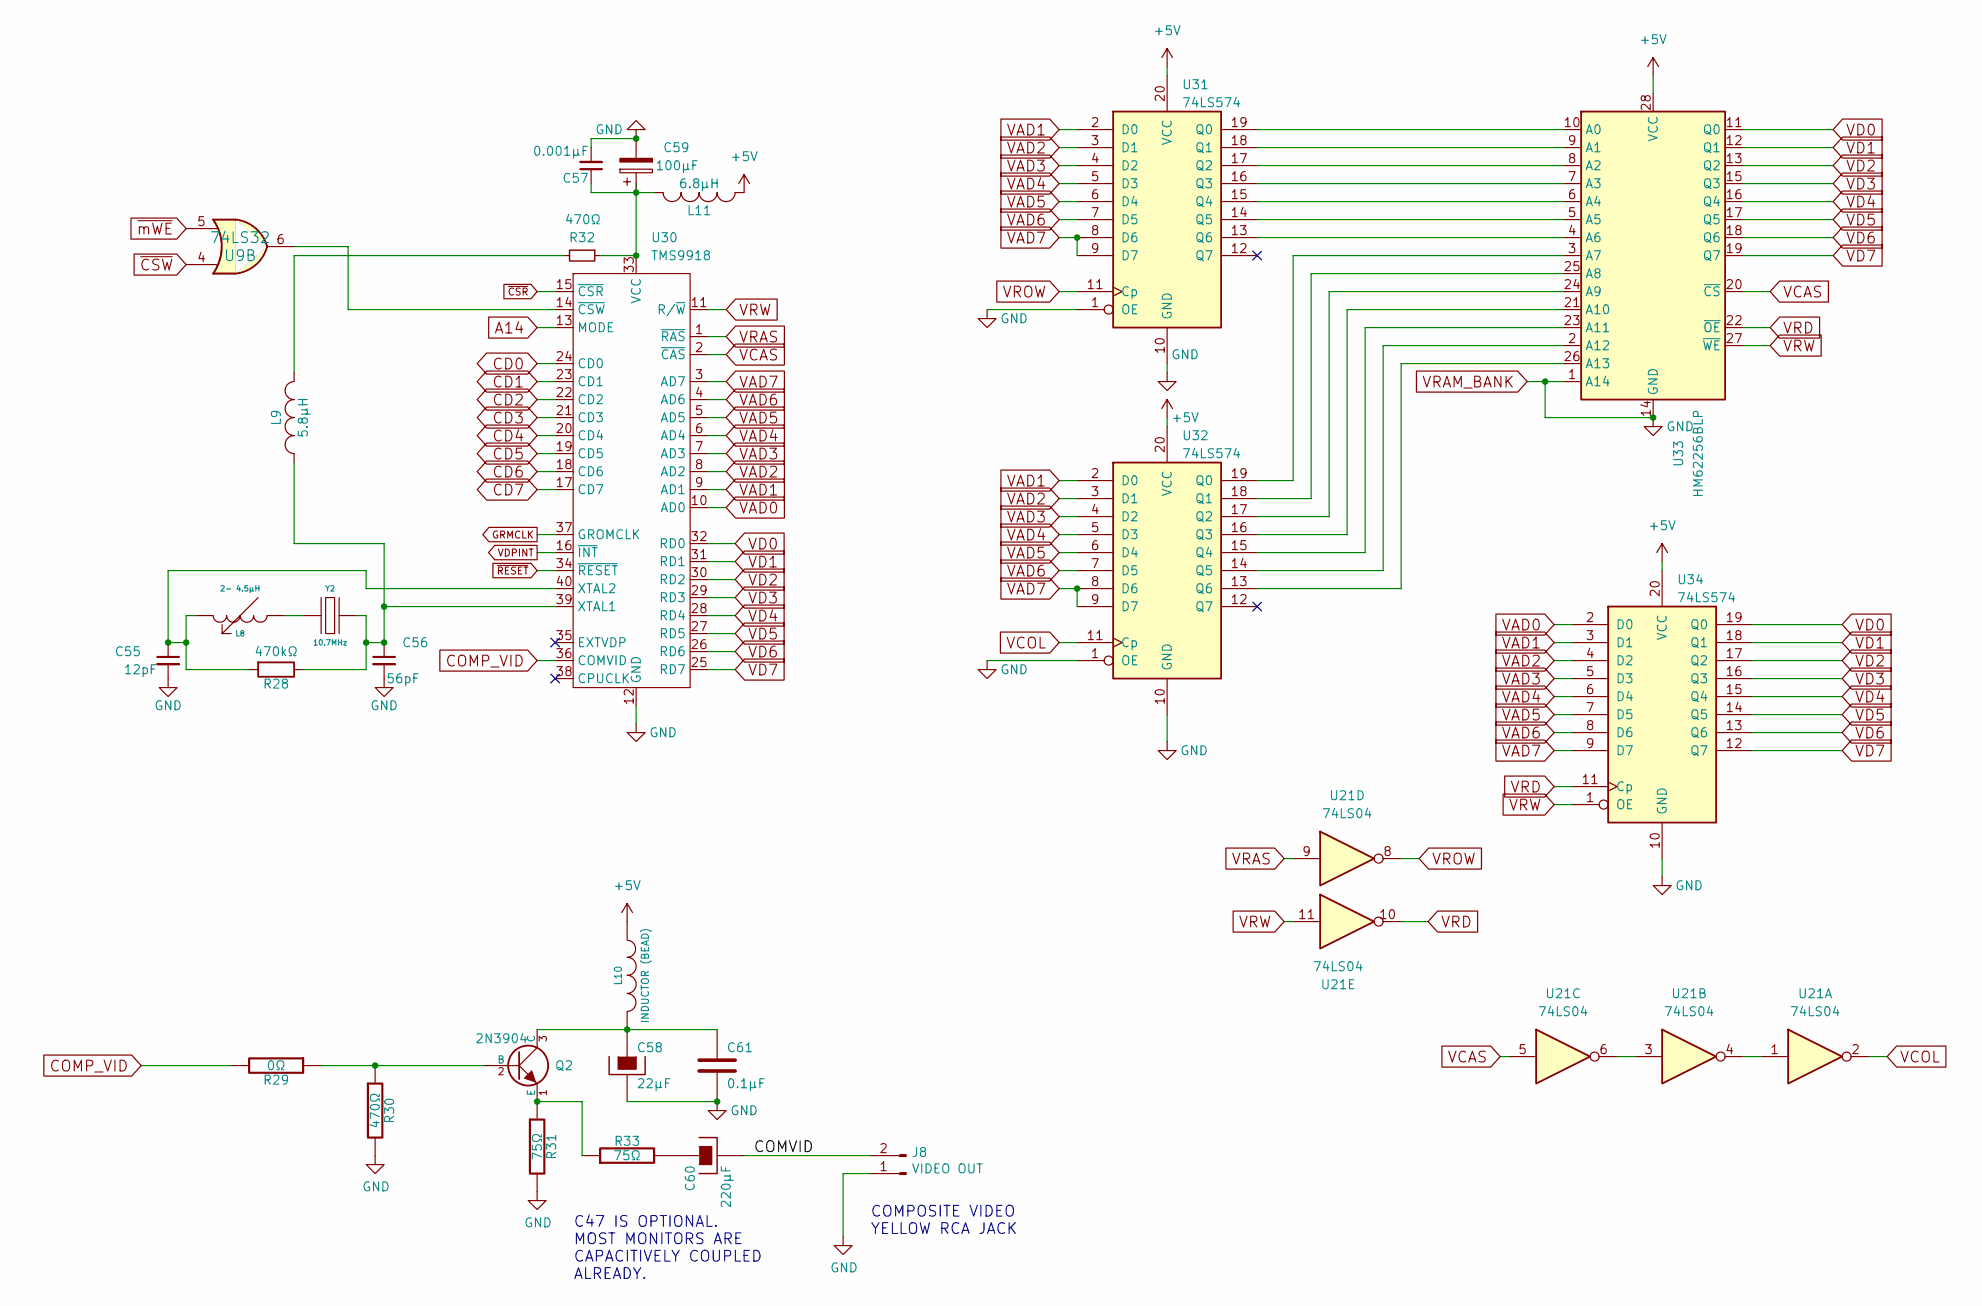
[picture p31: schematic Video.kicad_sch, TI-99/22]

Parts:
C55: 12pF; C_Rect_L7.0mm_W2.0mm_P5.00mm
C56: 56pF; C_Rect_L7.0mm_W2.0mm_P5.00mm
C57: 0.001µF; C_Rect_L7.0mm_W2.0mm_P5.00mm
C58: 22µF; CP_Radial_D7.5mm_P2.50mm
C59: 100µF; CP_Radial_D7.5mm_P2.50mm
C60: 220µF; CP_Radial_D7.5mm_P2.50mm
C61: 0.1µF; C_Rect_L7.0mm_W2.0mm_P5.00mm
J8: VIDEO OUT; PinHeader_1x02_P2.54mm_Vertical
L8: 2- 4.5µH; R_Axial_DIN0207_L6.3mm_D2.5mm_P7.62mm_Horizontal
L9: 5.8µH; R_Axial_DIN0207_L6.3mm_D2.5mm_P7.62mm_Horizontal
L10: INDUCTOR (BEAD); R_Axial_DIN0207_L6.3mm_D2.5mm_P10.16mm_Horizontal
L11: 6.8µH; R_Axial_DIN0207_L6.3mm_D2.5mm_P7.62mm_Horizontal
Q2: 2N3904; TO-92L_HandSolder
R28: 470kΩ; R_Axial_DIN0207_L6.3mm_D2.5mm_P7.62mm_Horizontal
R29: 0Ω; R_Axial_DIN0207_L6.3mm_D2.5mm_P7.62mm_Horizontal
R30, R32: 470Ω; R_Axial_DIN0207_L6.3mm_D2.5mm_P7.62mm_Horizontal
R31, R33: 75Ω; R_Axial_DIN0207_L6.3mm_D2.5mm_P7.62mm_Horizontal
U9: 74LS32; DIP-14_W7.62mm_Socket_LongPads
U21: 74LS04; DIP-14_W7.62mm_Socket_LongPads
U30: TMS9918; DIP-40_W15.24mm_Socket_LongPads
U31, U32, U34: 74LS574; DIP-20_W7.62mm_Socket_LongPads
U33: HM62256BLP; DIP-28_W15.24mm_Socket_LongPads
Y2: 10.7MHz; Crystal_HC49-U_Vertical

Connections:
+5V: L10.1, L11.2, U31.20 (VCC), U32.20 (VCC), U33.28 (VCC), U34.20 (VCC); also elsewhere on the board
/Video/COMVID: C60.2, J8.2
A14: U30.13 (MODE); also elsewhere on the board
CD0: U30.24 (CD0); also elsewhere on the board
CD1: U30.23 (CD1); also elsewhere on the board
CD2: U30.22 (CD2); also elsewhere on the board
CD3: U30.21 (CD3); also elsewhere on the board
CD4: U30.20 (CD4); also elsewhere on the board
CD5: U30.19 (CD5); also elsewhere on the board
CD6: U30.18 (CD6); also elsewhere on the board
CD7: U30.17 (CD7); also elsewhere on the board
COMP_VID: R29.2, U30.36 (COMVID)
GRMCLK: U30.37 (GROMCLK); also elsewhere on the board
unnamed: C55.1, L8.2, R28.2, U30.40 (XTAL2)
unnamed: C56.1, L9.1, R28.1, U30.39 (XTAL1), Y2.2
unnamed: C57.1, C59.1, L11.1, R32.1, U30.33 (VCC)
unnamed: C58.1, C61.1, L10.2, Q2.3 (C)
unnamed: C60.1, R33.2
unnamed: L8.1, Y2.1
unnamed: L9.2, R32.2
unnamed: Q2.1 (E), R31.1, R33.1
unnamed: Q2.2 (B), R29.1, R30.1
unnamed: U21.1, U21.4
unnamed: U21.3, U21.6
unnamed: U9.6, U30.14 (~CSW)
unnamed: U31.13 (Q6), U33.4 (A6)
unnamed: U31.14 (Q5), U33.5 (A5)
unnamed: U31.15 (Q4), U33.6 (A4)
unnamed: U31.16 (Q3), U33.7 (A3)
unnamed: U31.17 (Q2), U33.8 (A2)
unnamed: U31.18 (Q1), U33.9 (A1)
unnamed: U31.19 (Q0), U33.10 (A0)
unnamed: U32.13 (Q6), U33.26 (A13)
unnamed: U32.14 (Q5), U33.2 (A12)
unnamed: U32.15 (Q4), U33.23 (A11)
unnamed: U32.16 (Q3), U33.21 (A10)
unnamed: U32.17 (Q2), U33.24 (A9)
unnamed: U32.18 (Q1), U33.25 (A8)
unnamed: U32.19 (Q0), U33.3 (A7)
VAD0: U30.10 (AD0), U34.2 (D0)
VAD1: U30.9 (AD1), U31.2 (D0), U32.2 (D0), U34.3 (D1)
VAD2: U30.8 (AD2), U31.3 (D1), U32.3 (D1), U34.4 (D2)
VAD3: U30.7 (AD3), U31.4 (D2), U32.4 (D2), U34.5 (D3)
VAD4: U30.6 (AD4), U31.5 (D3), U32.5 (D3), U34.6 (D4)
VAD5: U30.5 (AD5), U31.6 (D4), U32.6 (D4), U34.7 (D5)
VAD6: U30.4 (AD6), U31.7 (D5), U32.7 (D5), U34.8 (D6)
VAD7: U30.3 (AD7), U31.8 (D6), U31.9 (D7), U32.8 (D6), U32.9 (D7), U34.9 (D7)
VCAS: U21.5, U30.2 (~CAS), U33.20 (~CS)
VCOL: U21.2, U32.11 (Cp)
VD0: U30.32 (RD0), U33.11 (Q0), U34.19 (Q0)
VD1: U30.31 (RD1), U33.12 (Q1), U34.18 (Q1)
VD2: U30.30 (RD2), U33.13 (Q2), U34.17 (Q2)
VD3: U30.29 (RD3), U33.15 (Q3), U34.16 (Q3)
VD4: U30.28 (RD4), U33.16 (Q4), U34.15 (Q4)
VD5: U30.27 (RD5), U33.17 (Q5), U34.14 (Q5)
VD6: U30.26 (RD6), U33.18 (Q6), U34.13 (Q6)
VD7: U30.25 (RD7), U33.19 (Q7), U34.12 (Q7)
VDPINT: U30.16 (~INT); also elsewhere on the board
VRAM_BANK: C55.2, C56.2, C57.2, C58.2, C59.2, C61.2, J8.1, R30.2, R31.2, U30.12 (GND), U31.1 (OE), U31.10 (GND), U32.1 (OE), U32.10 (GND), U33.1 (A14), U33.14 (GND), U34.10 (GND); also elsewhere on the board
VRAS: U21.9, U30.1 (~RAS)
VRD: U21.10, U33.22 (~OE), U34.11 (Cp)
VROW: U21.8, U31.11 (Cp)
VRW: U21.11, U30.11 (R/~W), U33.27 (~WE), U34.1 (OE)
~CSR: U30.15 (~CSR); also elsewhere on the board
~CSW: U9.4; also elsewhere on the board
~RESET: U30.34 (~RESET); also elsewhere on the board
~mWE: U9.5; also elsewhere on the board

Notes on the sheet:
COMPOSITE VIDEO YELLOW RCA JACK
C47 IS OPTIONAL. MOST MONITORS ARE CAPACITIVELY COUPLED ALREADY.

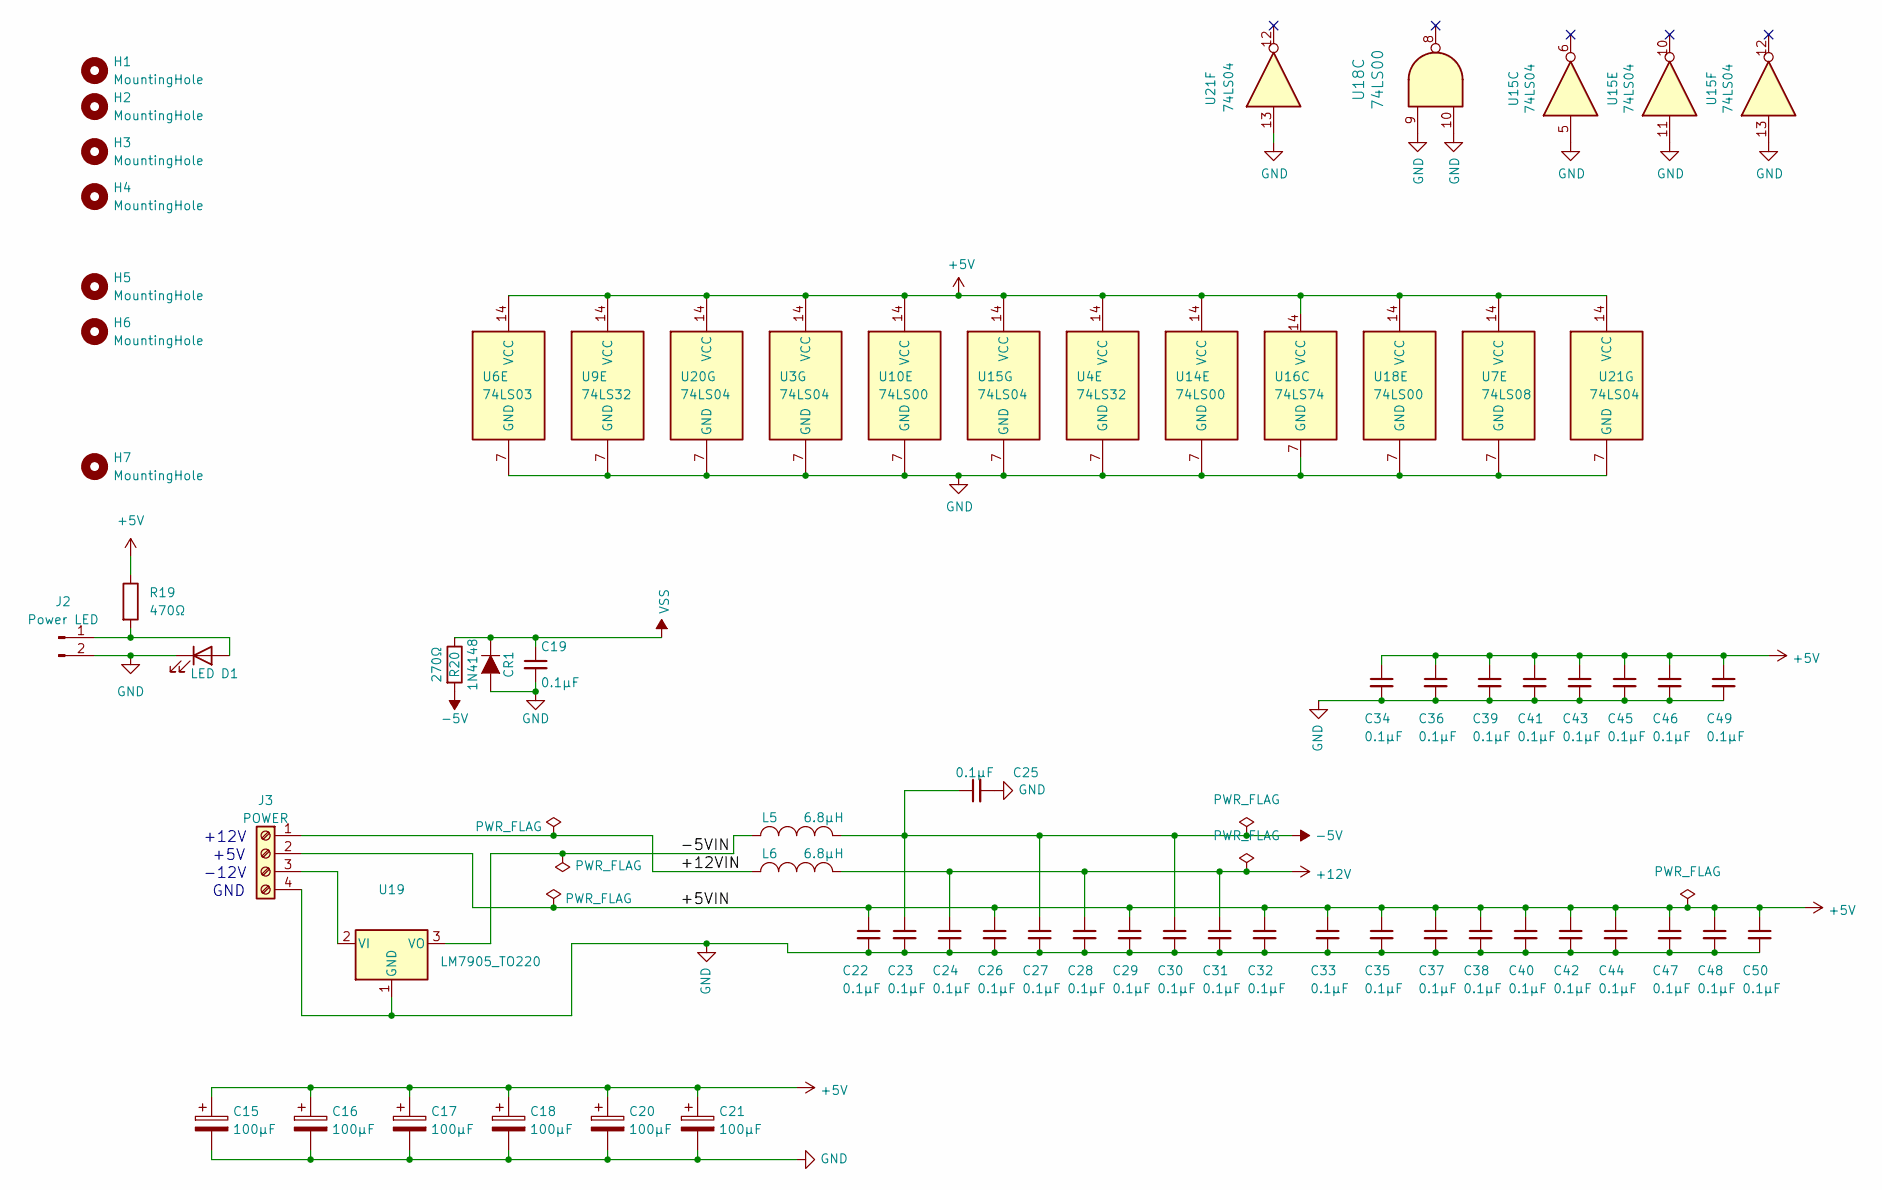
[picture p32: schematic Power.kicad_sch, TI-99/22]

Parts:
C15, C16, C17, C18, C20, C21: 100µF; CP_Radial_D7.5mm_P2.50mm
C19, C22, C23, C24, C25, C26, C27, C28, C29, C30, C31, C32, C33, C34, C35, C36, C37, C38, C39, C40, C41, C42, C43, C44, C45, C46, C47, C48, C49, C50: 0.1µF; C_Rect_L7.0mm_W2.0mm_P5.00mm
CR1: 1N4148; D_A-405_P7.62mm_Horizontal
D1: LED; LED_D5.0mm
H1, H2, H3, H4, H5, H6, H7: MountingHole; MountingHole_3.2mm_M3
J2: Power LED; PinHeader_1x02_P2.54mm_Vertical
J3: POWER; TerminalBlock_RND_205-00278_1x04_P5.00mm_Vertical
L5, L6: 6.8µH; R_Axial_DIN0207_L6.3mm_D2.5mm_P7.62mm_Horizontal
R19: 470Ω; R_Axial_DIN0207_L6.3mm_D2.5mm_P7.62mm_Horizontal
R20: 270Ω; R_Axial_DIN0207_L6.3mm_D2.5mm_P7.62mm_Horizontal
U3, U15, U20, U21: 74LS04; DIP-14_W7.62mm_Socket_LongPads
U4, U9: 74LS32; DIP-14_W7.62mm_Socket_LongPads
U6: 74LS03; DIP-14_W7.62mm_Socket_LongPads
U7: 74LS08; DIP-14_W7.62mm_Socket_LongPads
U10, U14, U18: 74LS00; DIP-14_W7.62mm_Socket_LongPads
U16: 74LS74; DIP-14_W7.62mm_Socket_LongPads
U19: LM7905_TO220; TO-220-3_Vertical

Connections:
+5V: C15.1, C16.1, C17.1, C18.1, C20.1, C21.1, C22.1, C26.1, C29.1, C32.1, C33.1, C34.1, C35.1, C36.1, C37.1, C38.1, C39.1, C40.1, C41.1, C42.1, C43.1, C44.1, C45.1, C46.1, C47.1, C48.1, C49.1, C50.1, J3.2, R19.1, U3.14 (VCC), U4.14 (VCC), U6.14 (VCC), U7.14 (VCC), U9.14 (VCC), U10.14 (VCC), U14.14 (VCC), U15.14 (VCC), U16.14 (VCC), U18.14 (VCC), U20.14 (VCC), U21.14 (VCC); also elsewhere on the board
+12V: C24.1, C28.1, C31.1, L6.1; also elsewhere on the board
-5V: C23.1, C25.1, C27.1, C30.1, L5.1, R20.2; also elsewhere on the board
/Power/+12VIN: J3.1, L6.2
/Power/-5VIN: L5.2, U19.3 (VO)
unnamed: D1.2 (A), J2.1, R19.2
unnamed: J3.3, U19.2 (VI)
VRAM_BANK: C15.2, C16.2, C17.2, C18.2, C19.2, C20.2, C21.2, C22.2, C23.2, C24.2, C25.2, C26.2, C27.2, C28.2, C29.2, C30.2, C31.2, C32.2, C33.2, C34.2, C35.2, C36.2, C37.2, C38.2, C39.2, C40.2, C41.2, C42.2, C43.2, C44.2, C45.2, C46.2, C47.2, C48.2, C49.2, C50.2, CR1.2 (A), D1.1 (K), J2.2, J3.4, U3.7 (GND), U4.7 (GND), U6.7 (GND), U7.7 (GND), U9.7 (GND), U10.7 (GND), U14.7 (GND), U15.5, U15.7 (GND), U15.11, U15.13, U16.7 (GND), U18.7 (GND), U18.9, U18.10, U19.1 (GND), U20.7 (GND), U21.7 (GND), U21.13; also elsewhere on the board
VSS: C19.1, CR1.1 (K), R20.1; also elsewhere on the board

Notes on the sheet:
-12V
+5V
GND
+12V

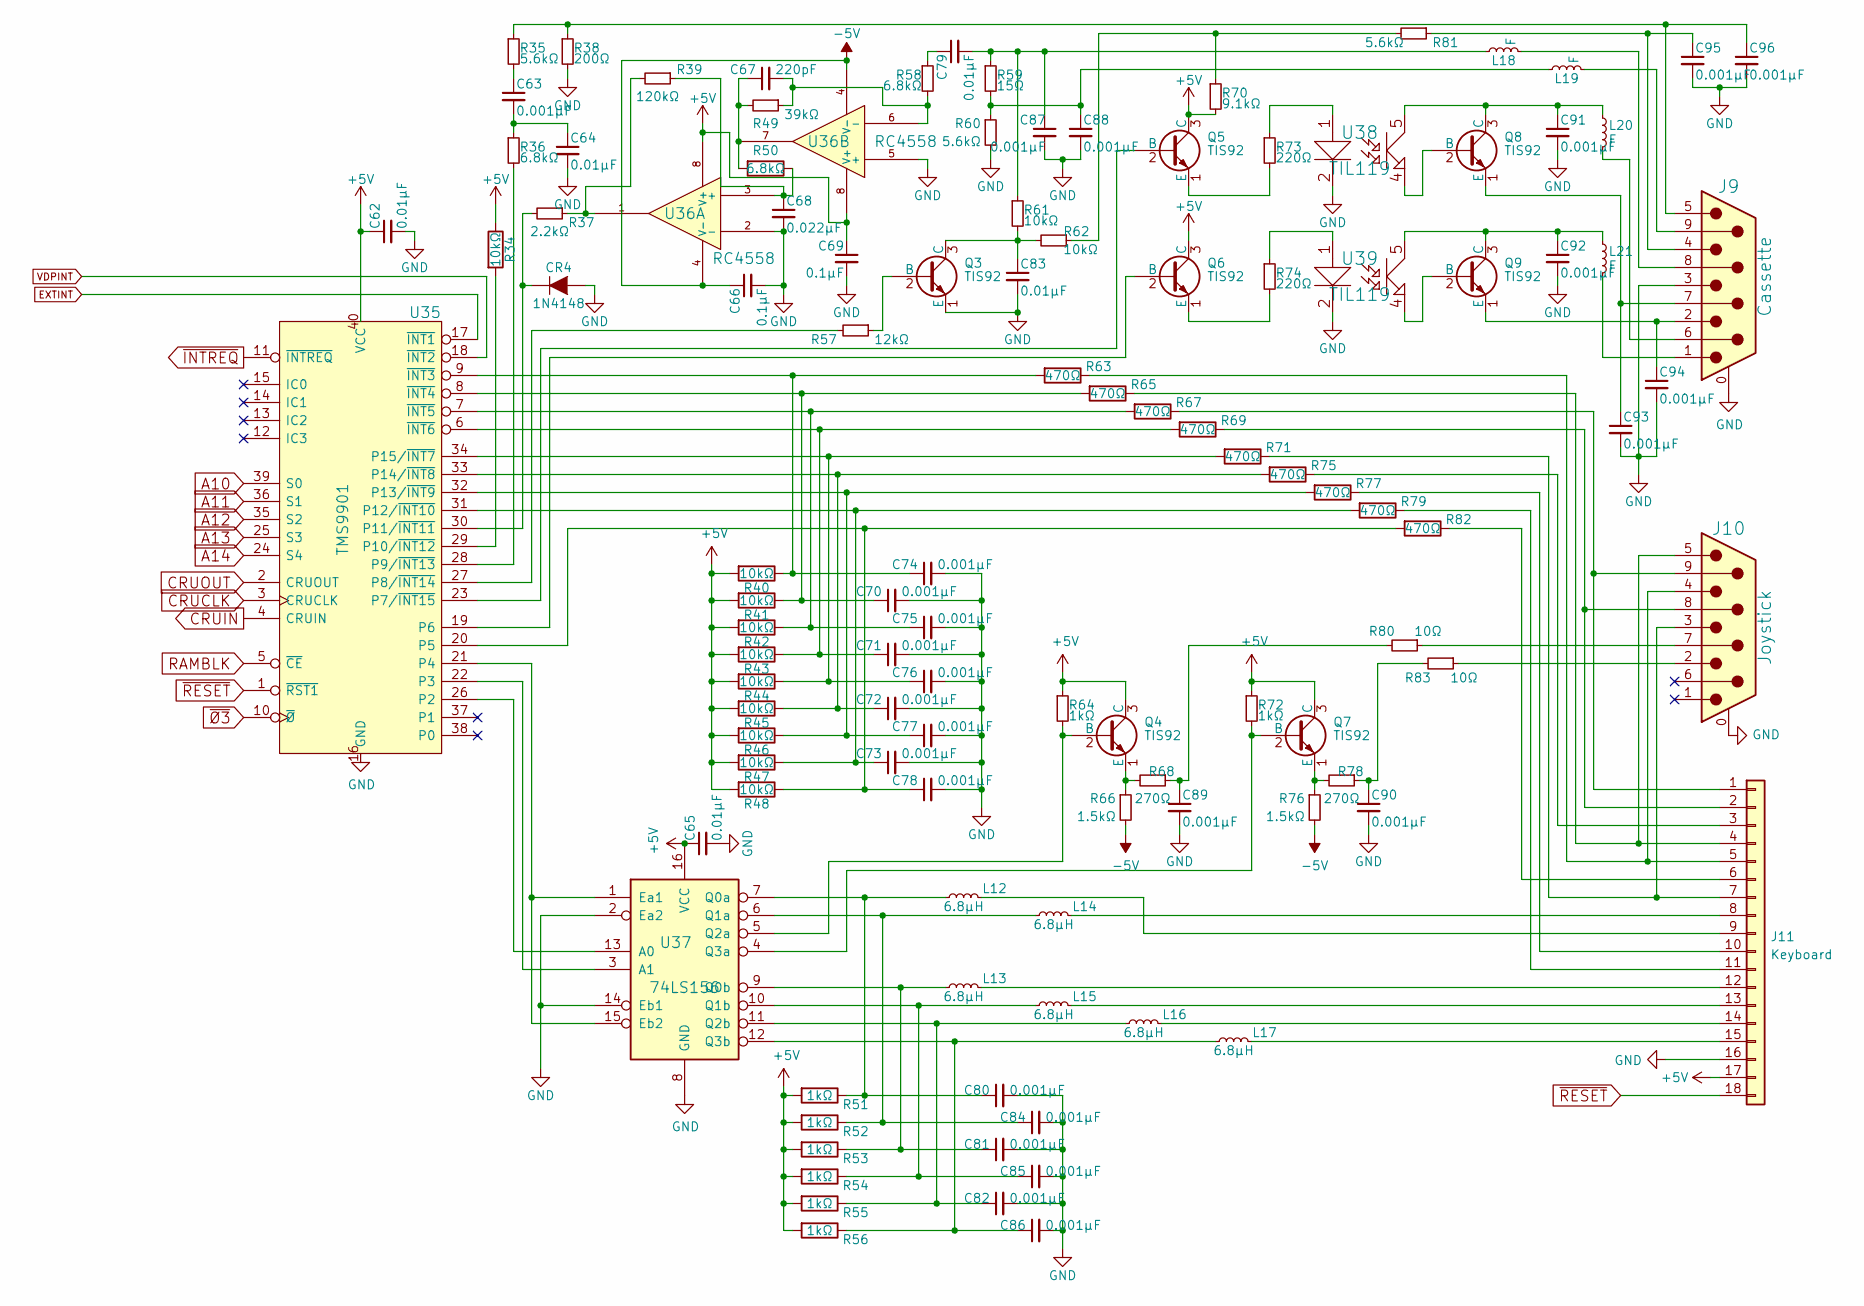
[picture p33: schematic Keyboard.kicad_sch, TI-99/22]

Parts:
C62, C64, C65, C79, C83: 0.01µF; C_Rect_L7.0mm_W2.0mm_P5.00mm
C63, C70, C71, C72, C73, C74, C75, C76, C77, C78, C80, C81, C82, C84, C85, C86, C87, C88, C89, C90, C91, C92, C93, C94, C95, C96: 0.001µF; C_Rect_L7.0mm_W2.0mm_P5.00mm
C66, C69: 0.1µF; C_Rect_L7.0mm_W2.0mm_P5.00mm
C67: 220pF; C_Rect_L7.0mm_W2.0mm_P5.00mm
C68: 0.022µF; C_Rect_L7.0mm_W2.0mm_P5.00mm
CR4: 1N4148; D_A-405_P7.62mm_Horizontal
J9: Cassette; DSUB-9_Female_Horizontal_P2.77x2.84mm_EdgePinOffset4.94mm_H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
J10: Joystick; DSUB-9_Female_Horizontal_P2.77x2.84mm_EdgePinOffset4.94mm_H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
J11: Keyboard; PinHeader_1x18_P2.54mm_Vertical
L12, L13, L14, L15, L16, L17: 6.8µH; R_Axial_DIN0207_L6.3mm_D2.5mm_P7.62mm_Horizontal
L18, L19, L20, L21: F; R_Axial_DIN0207_L6.3mm_D2.5mm_P7.62mm_Horizontal
Q3, Q4, Q5, Q6, Q7, Q8, Q9: TIS92; TO-92_HandSolder
R34, R40, R41, R42, R43, R44, R45, R46, R47, R48, R61, R62: 10kΩ; R_Axial_DIN0207_L6.3mm_D2.5mm_P7.62mm_Horizontal
R35, R60, R81: 5.6kΩ; R_Axial_DIN0207_L6.3mm_D2.5mm_P7.62mm_Horizontal
R36, R50, R58: 6.8kΩ; R_Axial_DIN0207_L6.3mm_D2.5mm_P7.62mm_Horizontal
R37: 2.2kΩ; R_Axial_DIN0207_L6.3mm_D2.5mm_P7.62mm_Horizontal
R38: 200Ω; R_Axial_DIN0207_L6.3mm_D2.5mm_P7.62mm_Horizontal
R39: 120kΩ; R_Axial_DIN0207_L6.3mm_D2.5mm_P7.62mm_Horizontal
R49: 39kΩ; R_Axial_DIN0207_L6.3mm_D2.5mm_P7.62mm_Horizontal
R51, R52, R53, R54, R55, R56, R64, R72: 1kΩ; R_Axial_DIN0207_L6.3mm_D2.5mm_P7.62mm_Horizontal
R57: 12kΩ; R_Axial_DIN0207_L6.3mm_D2.5mm_P7.62mm_Horizontal
R59: 15Ω; R_Axial_DIN0207_L6.3mm_D2.5mm_P7.62mm_Horizontal
R63, R65, R67, R69, R71, R75, R77, R79, R82: 470Ω; R_Axial_DIN0207_L6.3mm_D2.5mm_P7.62mm_Horizontal
R66, R76: 1.5kΩ; R_Axial_DIN0207_L6.3mm_D2.5mm_P7.62mm_Horizontal
R68, R78: 270Ω; R_Axial_DIN0207_L6.3mm_D2.5mm_P7.62mm_Horizontal
R70: 9.1kΩ; R_Axial_DIN0207_L6.3mm_D2.5mm_P7.62mm_Horizontal
R73, R74: 220Ω; R_Axial_DIN0207_L6.3mm_D2.5mm_P7.62mm_Horizontal
R80, R83: 10Ω; R_Axial_DIN0207_L6.3mm_D2.5mm_P7.62mm_Horizontal
U35: TMS9901; DIP-40_W15.24mm_Socket_LongPads
U36: RC4558; DIP-8_W7.62mm_Socket_LongPads
U37: 74LS156; DIP-16_W7.62mm_Socket_LongPads
U38, U39: TIL119; DIP-6_W7.62mm_Socket_LongPads

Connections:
+5V: C62.1, C65.1, C69.1, J11.17, Q4.3 (C), Q5.3 (C), Q6.3 (C), Q7.3 (C), R34.1, R40.2, R41.2, R42.2, R43.2, R44.2, R45.2, R46.2, R47.2, R48.2, R51.2, R52.2, R53.2, R54.2, R55.2, R56.2, R64.1, R70.2, R72.1, U35.40 (VCC), U36.8 (V+), U37.16 (VCC); also elsewhere on the board
-5V: C66.1, R66.2, R76.2, U36.4 (V-); also elsewhere on the board
A10: U35.39 (S0); also elsewhere on the board
A11: U35.36 (S1); also elsewhere on the board
A12: U35.35 (S2); also elsewhere on the board
A13: U35.25 (S3); also elsewhere on the board
A14: U35.24 (S4); also elsewhere on the board
CRUCLK: U35.3 (CRUCLK); also elsewhere on the board
CRUIN: U35.4 (CRUIN); also elsewhere on the board
CRUOUT: U35.2 (CRUOUT); also elsewhere on the board
EXTINT: U35.17 (~INT1); also elsewhere on the board
unnamed: C63.1, R35.2
unnamed: C63.2, C64.1, R36.1
unnamed: C67.1, R49.2, R50.2, U36.7
unnamed: C67.2, R49.1, R58.2, U36.6 (-)
unnamed: C68.1, R39.1, R50.1, U36.3 (+)
unnamed: C70.1, R41.1, R65.2, U35.8 (~INT4)
unnamed: C71.1, R43.1, R69.2, U35.6 (~INT6)
unnamed: C72.1, R45.1, R75.2, U35.33 (P14/~INT8)
unnamed: C73.1, R47.1, R79.2, U35.31 (P12/~INT10)
unnamed: C74.1, R40.1, R63.2, U35.9 (~INT3)
unnamed: C75.1, R42.1, R67.2, U35.7 (~INT5)
unnamed: C76.1, R44.1, R71.2, U35.34 (P15/~INT7)
unnamed: C77.1, R46.1, R77.2, U35.32 (P13/~INT9)
unnamed: C78.1, R48.1, R82.2, U35.20 (P5)
unnamed: C79.1, R58.1
unnamed: C79.2, C87.1, L18.1, R59.1, R61.1
unnamed: C80.1, L12.1, R51.1, U37.7 (Q0a)
unnamed: C81.1, L13.1, R53.1, U37.9 (Q0b)
unnamed: C82.1, L16.1, R55.1, U37.11 (Q2b)
unnamed: C83.1, Q3.3 (C), R61.2, R62.2
unnamed: C84.1, L14.1, R52.1, U37.6 (Q1a)
unnamed: C85.1, L15.1, R54.1, U37.10 (Q1b)
unnamed: C86.1, L17.1, R56.1, U37.12 (Q3b)
unnamed: C88.1, L19.1, R59.2, R60.1
unnamed: C89.1, R68.1, R80.2
unnamed: C90.1, R78.1, R83.2
unnamed: C91.1, L20.1, Q8.3 (C), U38.5
unnamed: C92.1, L21.1, Q9.3 (C), U39.5
unnamed: C93.1, J9.7, Q8.1 (E)
unnamed: C94.1, J9.2, Q9.1 (E)
unnamed: C95.1, J9.4, R81.1
unnamed: C96.1, J9.5, R35.1, R38.1
unnamed: CR4.1 (K), R37.2, U35.30 (P11/~INT11)
unnamed: J9.1, L21.2
unnamed: J9.6, L20.2
unnamed: J9.8, L18.2
unnamed: J9.9, L19.2
unnamed: J10.2, R83.1
unnamed: J10.3, J11.7, R71.1
unnamed: J10.4, J11.5, R63.1
unnamed: J10.5, J11.4, R65.1
unnamed: J10.7, R80.1
unnamed: J10.8, J11.2, R69.1
unnamed: J10.9, J11.1, R67.1
unnamed: J11.3, R75.1
unnamed: J11.6, R82.1
unnamed: J11.8, L14.2
unnamed: J11.9, L12.2
unnamed: J11.10, R77.1
unnamed: J11.11, R79.1
unnamed: J11.12, L13.2
unnamed: J11.13, L15.2
unnamed: J11.14, L16.2
unnamed: J11.15, L17.2
unnamed: Q3.2 (B), R57.1
unnamed: Q4.1 (E), R66.1, R68.2
unnamed: Q4.2 (B), R64.2, U37.5 (Q2a)
unnamed: Q5.1 (E), R73.2
unnamed: Q5.2 (B), U35.23 (P7/~INT15)
unnamed: Q6.1 (E), R74.2
unnamed: Q6.2 (B), U35.19 (P6)
unnamed: Q7.1 (E), R76.1, R78.2
unnamed: Q7.2 (B), R72.2, U37.4 (Q3a)
unnamed: Q8.2 (B), U38.4 (KK)
unnamed: Q9.2 (B), U39.4 (KK)
unnamed: R34.2, U35.29 (P10/~INT12)
unnamed: R36.2, U35.28 (P9/~INT13)
unnamed: R37.1, R39.2, U36.1
unnamed: R57.2, U35.27 (P8/~INT14)
unnamed: R62.1, R70.1, R81.2
unnamed: R73.1, U38.1 (A)
unnamed: R74.1, U39.1 (A)
unnamed: U35.21 (P4), U37.1 (Ea1), U37.15 (Eb2)
unnamed: U35.22 (P3), U37.3 (A1)
unnamed: U35.26 (P2), U37.13 (A0)
RAMBLK: U35.5 (~CE); also elsewhere on the board
VDPINT: U35.18 (~INT2); also elsewhere on the board
VRAM_BANK: C62.2, C64.2, C65.2, C66.2, C68.2, C69.2, C70.2, C71.2, C72.2, C73.2, C74.2, C75.2, C76.2, C77.2, C78.2, C80.2, C81.2, C82.2, C83.2, C84.2, C85.2, C86.2, C87.2, C88.2, C89.2, C90.2, C91.2, C92.2, C93.2, C94.2, C95.2, C96.2, CR4.2 (A), J9.0 (PAD), J9.3, J10.0 (PAD), J11.16, Q3.1 (E), R38.2, R60.2, U35.16 (GND), U36.2 (-), U36.5 (+), U37.2 (Ea2), U37.8 (GND), U37.14 (Eb1), U38.2 (K), U39.2 (K); also elsewhere on the board
~INTREQ: U35.11 (~INTREQ); also elsewhere on the board
~RESET: J11.18, U35.1 (~RST1); also elsewhere on the board
~Ø3: U35.10 (~Ø); also elsewhere on the board

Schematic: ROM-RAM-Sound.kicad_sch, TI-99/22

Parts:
C52: 100µF; CP_Radial_D5.0mm_P2.00mm
C53, C54: 0.1µF; C_Rect_L7.0mm_W2.0mm_P5.00mm
J5, J6: ROM Select; PinHeader_1x03_P2.54mm_Vertical
J7: AUDIO OUT; PinHeader_1x02_P2.54mm_Vertical
L7: 6.8µH; R_Axial_DIN0207_L6.3mm_D2.5mm_P7.62mm_Horizontal
R27: 10Ω; R_Axial_DIN0207_L6.3mm_D2.5mm_P7.62mm_Horizontal
U25, U26: HM62256BLP; DIP-28_W15.24mm_Socket_LongPads
U27, U28: 27C64; DIP-28_W15.24mm_Socket_LongPads
U29: SN76489; DIP-16_W7.62mm_Socket_LongPads

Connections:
+5V: J5.1, J6.1, L7.1, U25.28 (VCC), U26.28 (VCC), U27.27 (~PGM), U27.28 (VCC), U28.27 (~PGM), U28.28 (VCC); also elsewhere on the board
A0: U25.10 (A0), U26.10 (A0); also elsewhere on the board
A1: U25.9 (A1), U26.9 (A1); also elsewhere on the board
A2: U25.8 (A2), U26.8 (A2); also elsewhere on the board
A3: U25.7 (A3), U26.7 (A3), U27.23 (A11), U28.23 (A11); also elsewhere on the board
A4: U25.6 (A4), U26.6 (A4), U27.21 (A10), U28.21 (A10); also elsewhere on the board
A5: U25.5 (A5), U26.5 (A5), U27.24 (A9), U28.24 (A9); also elsewhere on the board
A6: U25.4 (A6), U26.4 (A6), U27.25 (A8), U28.25 (A8); also elsewhere on the board
A7: U25.3 (A7), U26.3 (A7), U27.3 (A7), U28.3 (A7); also elsewhere on the board
A8: U25.25 (A8), U26.25 (A8), U27.4 (A6), U28.4 (A6); also elsewhere on the board
A9: U25.24 (A9), U26.24 (A9), U27.5 (A5), U28.5 (A5); also elsewhere on the board
A10: U25.21 (A10), U26.21 (A10), U27.6 (A4), U28.6 (A4); also elsewhere on the board
A11: U25.23 (A11), U26.23 (A11), U27.7 (A3), U28.7 (A3); also elsewhere on the board
A12: U25.2 (A12), U26.2 (A12), U27.8 (A2), U28.8 (A2); also elsewhere on the board
A13: U25.26 (A13), U26.26 (A13), U27.9 (A1), U28.9 (A1); also elsewhere on the board
A14: U25.1 (A14), U26.1 (A14), U27.10 (A0), U28.10 (A0); also elsewhere on the board
CD0: U25.11 (Q0), U27.19 (D7); also elsewhere on the board
CD1: U25.12 (Q1), U27.18 (D6); also elsewhere on the board
CD2: U25.18 (Q6), U27.17 (D5); also elsewhere on the board
CD3: U25.16 (Q4), U27.16 (D4); also elsewhere on the board
CD4: U25.17 (Q5), U27.15 (D3); also elsewhere on the board
CD5: U25.15 (Q3), U27.13 (D2); also elsewhere on the board
CD6: U25.13 (Q2), U27.12 (D1); also elsewhere on the board
CD7: U25.19 (Q7), U27.11 (D0); also elsewhere on the board
CD8: U26.15 (Q3), U28.19 (D7); also elsewhere on the board
CD9: U26.13 (Q2), U28.18 (D6); also elsewhere on the board
CD10: U26.12 (Q1), U28.17 (D5); also elsewhere on the board
CD11: U26.11 (Q0), U28.16 (D4); also elsewhere on the board
CD12: U26.19 (Q7), U28.15 (D3); also elsewhere on the board
CD13: U26.18 (Q6), U28.13 (D2); also elsewhere on the board
CD14: U26.17 (Q5), U28.12 (D1); also elsewhere on the board
CD15: U26.16 (Q4), U28.11 (D0); also elsewhere on the board
D0: U29.3 (D0); also elsewhere on the board
D1: U29.2 (D1); also elsewhere on the board
D2: U29.1 (D2); also elsewhere on the board
D3: U29.15 (D3); also elsewhere on the board
D4: U29.13 (D4); also elsewhere on the board
D5: U29.12 (D5); also elsewhere on the board
D6: U29.11 (D6); also elsewhere on the board
D7: U29.10 (D7); also elsewhere on the board
GRMCLK: U29.14 (CLK); also elsewhere on the board
unnamed: C52.1, C53.1, U29.7 (AOUT)
unnamed: C53.2, R27.1
unnamed: C54.2, L7.2, U29.16 (VCC)
unnamed: J5.2, U27.2 (A12)
unnamed: J6.2, U28.2 (A12)
READY_~HOLD: U29.4 (READY); also elsewhere on the board
SNDIN: U29.9 (AIN); also elsewhere on the board
SNDOUT: C52.2, J7.1
VRAM_BANK: C54.1, J5.3, J6.3, J7.2, R27.2, U25.14 (GND), U25.22 (~OE), U26.14 (GND), U26.22 (~OE), U27.14 (GND), U27.22 (~OE), U28.14 (GND), U28.22 (~OE), U29.8 (GND); also elsewhere on the board
~RAM: U25.20 (~CS), U26.20 (~CS); also elsewhere on the board
~ROM: U27.20 (~CE), U28.20 (~CE); also elsewhere on the board
~SOUND_SEL: U29.6 (~CE); also elsewhere on the board
~WE: U25.27 (~WE), U26.27 (~WE); also elsewhere on the board
~mWE: U29.5 (~WE); also elsewhere on the board

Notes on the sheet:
AUDIO RED RCA JACK

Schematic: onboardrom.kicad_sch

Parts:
J16: Rom Select 1; PinSocket_1x03_P2.54mm_Vertical
J17: Rom Select 2; PinSocket_1x03_P2.54mm_Vertical
R100: 10kΩ; R_Axial_DIN0207_L6.3mm_D2.5mm_P7.62mm_Horizontal
SW2: Internal Cart ROM Enable; PinHeader_1x02_P2.54mm_Vertical
U43: 74LS379; DIP-16_W7.62mm_Socket_LongPads
U44: 27C010-C; DIP-32_W15.24mm_Socket_LongPads

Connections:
+5V: R100.1, U43.16 (VCC), U44.30 (NC), U44.31 (~PGM), U44.32 (VCC); also elsewhere on the board
A3: U44.4 (A12); also elsewhere on the board
A4: U44.25 (A11); also elsewhere on the board
A5: U44.23 (A10); also elsewhere on the board
A6: U44.26 (A9); also elsewhere on the board
A7: U44.27 (A8); also elsewhere on the board
A8: U44.5 (A7); also elsewhere on the board
A9: U44.6 (A6); also elsewhere on the board
A10: U44.7 (A5); also elsewhere on the board
A11: U43.13 (D3), U44.8 (A4); also elsewhere on the board
A12: U43.12 (D2), U44.9 (A3); also elsewhere on the board
A13: U43.5 (D1), U44.10 (A2); also elsewhere on the board
A15-CRUOUT: U44.12 (A0); also elsewhere on the board
D0: U44.21 (D7); also elsewhere on the board
D1: U44.20 (D6); also elsewhere on the board
D2: U44.19 (D5); also elsewhere on the board
D3: U44.18 (D4); also elsewhere on the board
D4: U44.17 (D3); also elsewhere on the board
D5: U44.15 (D2); also elsewhere on the board
D6: U44.14 (D1); also elsewhere on the board
D7: U44.13 (D0); also elsewhere on the board
IO_A14: U43.4 (D0), U44.11 (A1); also elsewhere on the board
IR_A1: J17.3, U43.10 (Q2)
IR_A1_O: J17.2, U44.3 (A15)
IR_A2: J16.3, U43.7 (Q1)
IR_A2_O: J16.2, U44.29 (A14)
unnamed: U43.2 (Q0), U44.28 (A13)
unnamed: U43.15 (Q3), U44.2 (A16)
VRAM_BANK: J16.1, J17.1, U43.8 (GND), U44.1 (VPP), U44.16 (GND), U44.22 (~CE); also elsewhere on the board
~IROMG: R100.2, SW2.2, U43.1 (~E), U44.24 (~OE)
~ROMG: SW2.1; also elsewhere on the board
~mWE: U43.9 (CP); also elsewhere on the board

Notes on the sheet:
27C010 J17-2&3 J18-2&3 27C512 J17-2&3 J18-2&3 27C256 J17-1&2 J18-2&3 27C128 J17-1&2 J18-1&2 27C64 J17-1&2 J18-1&2

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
Board: 2 copper layers, 303 parts (0 on the bottom side), 325 nets, no tracks yet.

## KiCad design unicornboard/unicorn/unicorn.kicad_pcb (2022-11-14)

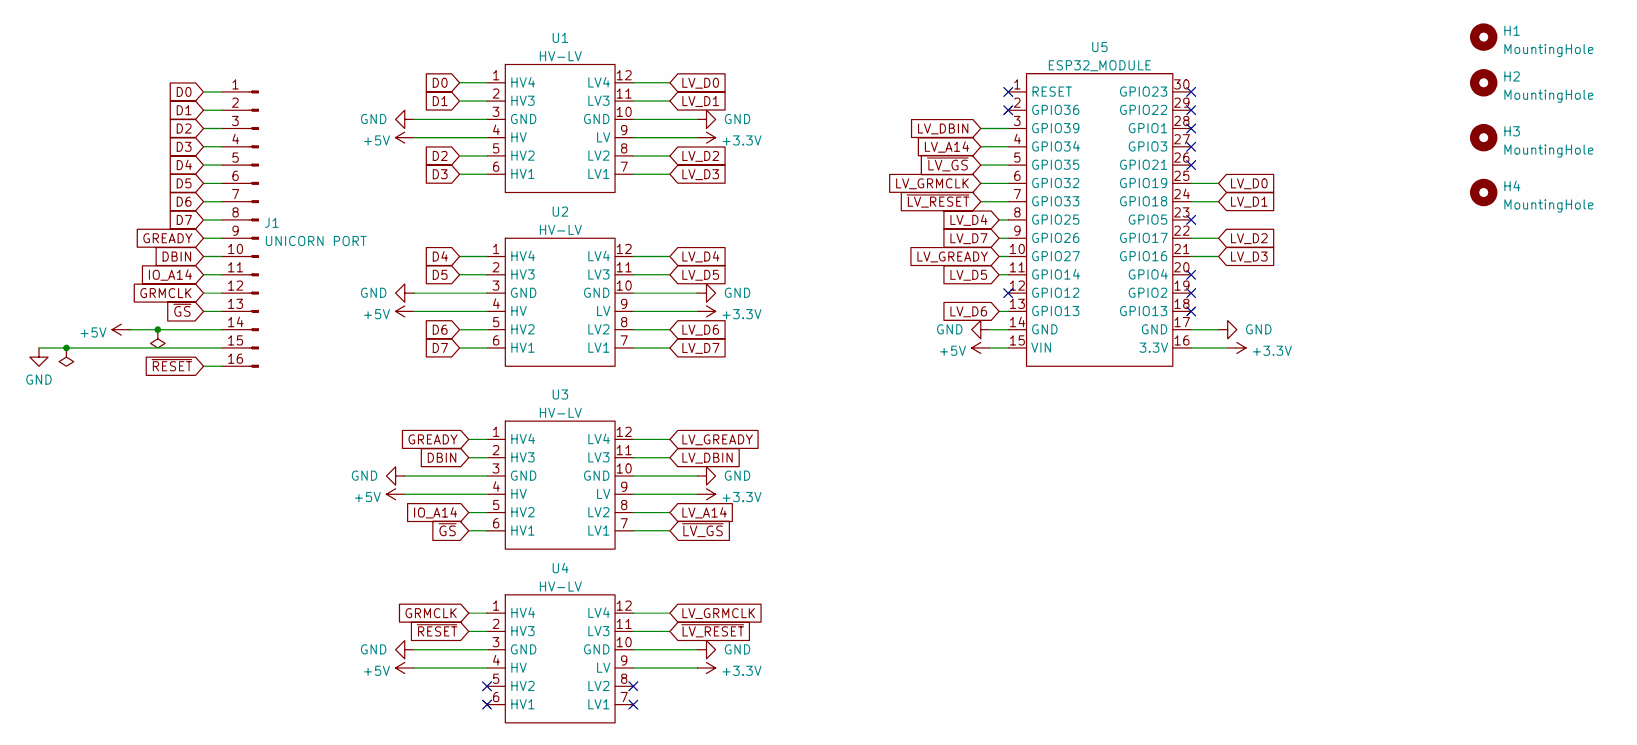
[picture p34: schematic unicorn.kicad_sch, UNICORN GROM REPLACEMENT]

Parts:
H1, H2, H3, H4: MountingHole; MountingHole_3.2mm_M3
J1: UNICORN PORT; PinHeader_1x16_P2.54mm_Vertical
U1, U2, U3, U4: HV-LV
U5: ESP32_MODULE; ESP32_DEVKIT_30

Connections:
+3.3V: U1.9 (LV), U2.9 (LV), U3.9 (LV), U4.9 (LV), U5.16 (3.3V)
+5V: J1.14, U1.4 (HV), U2.4 (HV), U3.4 (HV), U4.4 (HV), U5.15 (VIN)
D0: J1.1, U1.1 (HV4)
D1: J1.2, U1.2 (HV3)
D2: J1.3, U1.5 (HV2)
D3: J1.4, U1.6 (HV1)
D4: J1.5, U2.1 (HV4)
D5: J1.6, U2.2 (HV3)
D6: J1.7, U2.5 (HV2)
D7: J1.8, U2.6 (HV1)
DBIN: J1.10, U3.2 (HV3)
GND: J1.15, U1.3 (GND), U1.10 (GND), U2.3 (GND), U2.10 (GND), U3.3 (GND), U3.10 (GND), U4.3 (GND), U4.10 (GND), U5.14 (GND), U5.17 (GND)
GREADY: J1.9, U3.1 (HV4)
GRMCLK: J1.12, U4.1 (HV4)
IO_A14: J1.11, U3.5 (HV2)
LV_A14: U3.8 (LV2), U5.4 (GPIO34)
LV_D0: U1.12 (LV4), U5.25 (GPIO19)
LV_D1: U1.11 (LV3), U5.24 (GPIO18)
LV_D2: U1.8 (LV2), U5.22 (GPIO17)
LV_D3: U1.7 (LV1), U5.21 (GPIO16)
LV_D4: U2.12 (LV4), U5.8 (GPIO25)
LV_D5: U2.11 (LV3), U5.11 (GPIO14)
LV_D6: U2.8 (LV2), U5.13 (GPIO13)
LV_D7: U2.7 (LV1), U5.9 (GPIO26)
LV_DBIN: U3.11 (LV3), U5.3 (GPIO39)
LV_GREADY: U3.12 (LV4), U5.10 (GPIO27)
LV_GRMCLK: U4.12 (LV4), U5.6 (GPIO32)
~GS: J1.13, U3.6 (HV1)
~LV_GS: U3.7 (LV1), U5.5 (GPIO35)
~LV_RESET: U4.11 (LV3), U5.7 (GPIO33)
~RESET: J1.16, U4.2 (HV3)

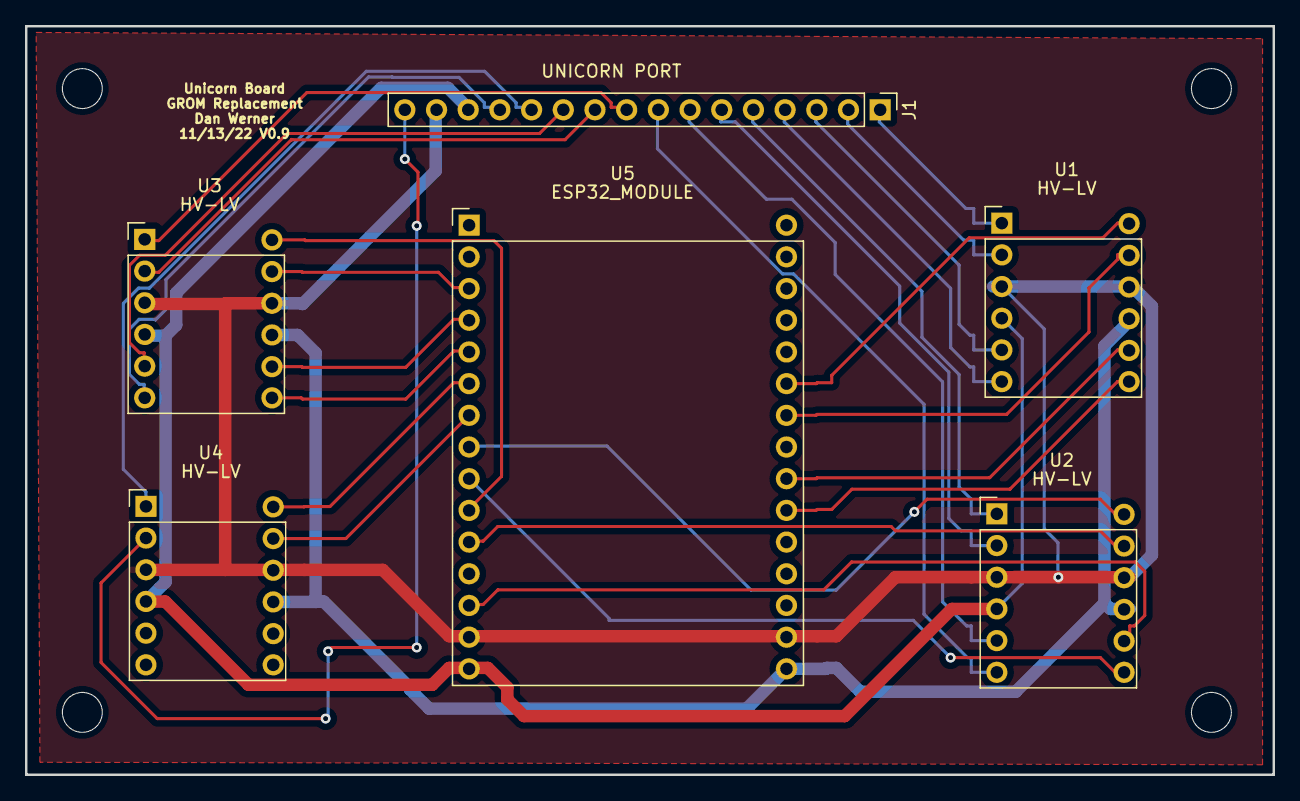
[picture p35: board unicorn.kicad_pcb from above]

Board: 2 copper layers, 100.0 x 60.0 mm, 10 parts (0 on the bottom side), 31 nets.

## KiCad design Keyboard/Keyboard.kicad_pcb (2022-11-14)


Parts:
C1: 0.1µF; C_Disc_D7.0mm_W2.5mm_P5.00mm
D1: Alpha; LED_D3.0mm
D2: Power; LED_D3.0mm
H1, H2, H3, H4, H5, H6: MountingHole; MountingHole_3.2mm_M3_Pad
J1: Computer; PinHeader_1x18_P2.54mm_Vertical
R1, R2: 470Ω; R_Axial_DIN0207_L6.3mm_D2.5mm_P7.62mm_Horizontal
R3: 1KΩ; R_Axial_DIN0207_L6.3mm_D2.5mm_P7.62mm_Horizontal
SW1: SLASH; CHERRY_PCB_100H
SW2: PERIOD; CHERRY_PCB_100H
SW3: COMMA; CHERRY_PCB_100H
SW4: M; CHERRY_PCB_100H
SW5: N; CHERRY_PCB_100H
SW6: EQUALS; CHERRY_PCB_100H
SW7: COLON; CHERRY_PCB_100H
SW8: L; CHERRY_PCB_100H
SW9: K; CHERRY_PCB_100H
SW10: J; CHERRY_PCB_100H
SW11: H; CHERRY_PCB_100H
SW12: SPACE; CHERRY_PCB_625H
SW13: P; CHERRY_PCB_100H
SW14: O; CHERRY_PCB_100H
SW15: I; CHERRY_PCB_100H
SW16: U; CHERRY_PCB_100H
SW17: Y; CHERRY_PCB_100H
SW18: ENTER; CHERRY_PCB_225H
SW19: 0; CHERRY_PCB_100H
SW20: 9; CHERRY_PCB_100H
SW21: 8; CHERRY_PCB_100H
SW22: 7; CHERRY_PCB_100H
SW23: 6; CHERRY_PCB_100H
SW24: Z; CHERRY_PCB_100H
SW25: X; CHERRY_PCB_100H
SW26: C; CHERRY_PCB_100H
SW27: V; CHERRY_PCB_100H
SW28: B; CHERRY_PCB_100H
SW29: LOCK; SW_Cherry_MX_1.75u_PCB
SW30: A; CHERRY_PCB_100H
SW31: S; CHERRY_PCB_100H
SW32: D; CHERRY_PCB_100H
SW33: F; CHERRY_PCB_100H
SW34: G; CHERRY_PCB_100H
SW35: SHIFT; CHERRY_PCB_275H
SW36: SHIFT; CHERRY_PCB_225H
SW37: Q; CHERRY_PCB_100H
SW38: W; CHERRY_PCB_100H
SW39: E; CHERRY_PCB_100H
SW40: R; CHERRY_PCB_100H
SW41: T; CHERRY_PCB_100H
SW42: CTRL; SW_Cherry_MX_1.25u_PCB
SW43: 1; CHERRY_PCB_100H
SW44: 2; CHERRY_PCB_100H
SW45: 3; CHERRY_PCB_100H
SW46: 4; CHERRY_PCB_100H
SW47: 5; CHERRY_PCB_100H
SW48: FNCT; SW_Cherry_MX_1.25u_PCB
U1: ATtiny13A-P; DIP-8_W7.62mm_LongPads
U2: 74LS125; DIP-14_W7.62mm_Socket_LongPads

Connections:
GND: C1.2, D2.1 (K), J1.16, R3.2, U1.4 (GND), U2.7 (GND)
LOCK: R3.1, SW29.2, U1.2 (PB3)
unnamed: D1.2 (A), R1.1
unnamed: D2.2 (A), R2.1
PA0: J1.8, SW1.1, SW7.1, SW13.1, SW19.1, SW24.1, SW30.1, SW37.1, SW43.1
PA1: J1.13, SW2.1, SW8.1, SW14.1, SW20.1, SW25.1, SW31.1, SW38.1, SW44.1
PA2: J1.14, SW3.1, SW9.1, SW15.1, SW21.1, SW26.1, SW32.1, SW39.1, SW45.1
PA3: J1.15, SW4.1, SW10.1, SW16.1, SW22.1, SW27.1, SW33.1, SW40.1, SW46.1
PA4: J1.9, SW5.1, SW11.1, SW17.1, SW23.1, SW28.1, SW34.1, SW41.1, SW47.1
PA5: J1.12, SW6.1, SW12.1, SW18.1, SW35.1, SW36.1, SW42.1, SW48.1
PA6: J1.6, U2.1
PB0: J1.5, SW1.2, SW2.2, SW3.2, SW4.2, SW5.2, SW6.2
PB1: J1.4, SW7.2, SW8.2, SW9.2, SW10.2, SW11.2, SW12.2
PB2: J1.1, SW13.2, SW14.2, SW15.2, SW16.2, SW17.2, SW18.2
PB3: J1.2, SW19.2, SW20.2, SW21.2, SW22.2, SW23.2
PB4: J1.11, SW24.2, SW25.2, SW26.2, SW27.2, SW28.2
PB5: J1.3, SW30.2, SW31.2, SW32.2, SW33.2, SW34.2, SW35.2, SW36.2
PB6: J1.10, SW37.2, SW38.2, SW39.2, SW40.2, SW41.2, SW42.2
PB7: J1.7, SW43.2, SW44.2, SW45.2, SW46.2, SW47.2, SW48.2, U2.3
VCC: C1.1, J1.17, R1.2, R2.2, SW29.1, U1.8 (VCC), U2.14 (VCC)
~LOCKOUT: D1.1 (K), U1.7 (PB2), U2.2
~RESET: J1.18, U1.1 (~RESET/PB5)


Board: 2 copper layers, 282.7 x 108.3 mm, 63 parts (0 on the bottom side), 22 nets.

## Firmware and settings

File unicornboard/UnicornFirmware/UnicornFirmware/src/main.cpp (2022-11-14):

#include <Arduino.h>
#include "grom.h"

#define   D0 26
#define   D1 13
#define   D2 14
#define   D3 25
#define   D4 16
#define   D5 17
#define   D6 18
#define   D7 19

#define   RESET  33
#define   GRMCLK 32
#define   MO     34
#define   GS     35
#define   GREADY 27
#define   M      39

#define   inMask 0xf9f09fff
#define   outMask 0x060f6000

volatile bool lowByte=true;
volatile bool readLowByte=true;
volatile uint16_t address=0;
volatile uint8_t dataByte;
volatile uint16_t dataWord;
volatile uint32_t output=0x060f6000;
volatile uint32_t temp;

volatile       uint8_t mo;
volatile       uint8_t m;
volatile       uint8_t outbyte;

void incrementAddress();
void outGromData();

void setup() {
  pinMode(GREADY,OUTPUT_OPEN_DRAIN );
  digitalWrite(GREADY,0);

  pinMode(RESET,OUTPUT);
  digitalWrite(RESET,0);

  pinMode(D0, INPUT);
  pinMode(D1, INPUT);
  pinMode(D2, INPUT);
  pinMode(D3, INPUT);
  pinMode(D4, INPUT);
  pinMode(D5, INPUT);
  pinMode(D6, INPUT);
  pinMode(D7, INPUT);

  pinMode(GRMCLK, INPUT);
  pinMode(MO, INPUT);
  pinMode(GS, INPUT);
  pinMode(M, INPUT);

  delay(500);
  digitalWrite(RESET,1);
  pinMode(RESET,INPUT);
}

void loop() {

  if(!(REG_READ(GPIO_IN1_REG) & 0x08))
  {
      mo=REG_READ(GPIO_IN1_REG) & 0x04;
      m=REG_READ(GPIO_IN1_REG) & 0x80;

    // SET ADDRESS
    if((mo!=0) && (m==0))
    {
      readLowByte=true;

      dataWord= (REG_READ(GPIO_IN_REG)>>12);
      dataByte=(dataWord & 0xf6) + ((dataWord>>14)&0x01) + ((dataWord>>10)&0x08);

      if(lowByte)
      {
        address=(dataByte <<8);
        lowByte=false;
      }
      else
      {
        address=address | dataByte;
        lowByte=true;
      }
    }

    // Read Address
    if((mo!=0) && (m!=0))
    {
     lowByte=true;
     if(readLowByte)
     {
        outbyte=((address+1)&0xff00)>>8;
        readLowByte=false;
     }
     else
     {
      outbyte=(address+1)&0xff;
      readLowByte=true;
     }
      temp=REG_READ(GPIO_ENABLE_REG);
      REG_WRITE(GPIO_ENABLE_REG,(temp | outMask));
      outGromData();
    }

    // write Data
    if((mo==0) && (m==0))
    {
      readLowByte=true;
      lowByte=true;
      incrementAddress();
    }

    // Read Data
    if((mo==0) && (m!=0))
    {
      readLowByte=true;
      lowByte=true;
      if(((address>=0x0000) && (address<=0x17ff)) || ((address>=0x2000) && (address<=0x37ff)) || ((address>=0x4000) && (address<=0x57ff)) ||
        ((address>=0x6000) && (address<=0x77ff)) || ((address>=0x8000) && (address<=0x97ff)) || ((address>=0xA000) && (address<=0xB7ff)) ||
        ((address>=0xC000) && (address<=0xD7ff)) || ((address>=0xE000) && (address<=0xF7ff)) )
      {
        outbyte=GROM[address];
        temp=REG_READ(GPIO_ENABLE_REG);
        REG_WRITE(GPIO_ENABLE_REG,(temp | outMask));
        outGromData();
      }
     incrementAddress();
    }


    REG_WRITE(GPIO_OUT_W1TS_REG, BIT27);
    while(!(REG_READ(GPIO_IN1_REG) & 0x08));
    REG_WRITE(GPIO_OUT_W1TC_REG, BIT27);

    temp=REG_READ(GPIO_ENABLE_REG);
    REG_WRITE(GPIO_ENABLE_REG,(temp & inMask));
  }

}


void incrementAddress()
{
   address++;
      switch(address)
      {
        case 0x1800:
            address=0x0000;
            break;
        case 0x3800:
            address=0x2000;
            break;
        case 0x5800:
            address=0x4000;
            break;
        case 0x7800:
            address=0x6000;
            break;
        case 0x9800:
            address=0x8000;
            break;
        case 0xb800:
            address=0xa000;
            break;
        case 0xd800:
            address=0xc000;
            break;
        case 0xf800:
            address=0xe000;
            break;
        }
}

void outGromData()
{
    output=0x060f6000;
    REG_WRITE(GPIO_OUT_W1TC_REG, output);
    output=((outbyte&0xf6)<<12) + ((outbyte&0x1)<<26)+ ((outbyte&0x8)<<22);
    REG_WRITE(GPIO_OUT_W1TS_REG, output);
}

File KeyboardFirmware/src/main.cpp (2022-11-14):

#include <Arduino.h>

//========================================================================
// Hardwiring the ATtiny85
//========================================================================
/*
                             ____  ____
               /RESET (PB5) -|   \/   |- (Vcc)
                 LOCK (PB3) -|        |- (PB2) CAPS LED
                   nc (PB4) -|        |- (PB1) MATRIX PA6 (OUT)
                      (GND) -|________|- (PB0) MATRIX PB7 (IN)

*/

static int capslock = 0;
static int buttonState = LOW; //this variable tracks the state of the button, low if not pressed, high if pressed
static unsigned long lastDebounceTime = 0;  // the last time the output pin was toggled
static unsigned long debounceDelay = 50;    // the debounce time; increase if the output flickers

void setup()
{
  pinMode(3, INPUT);
  pinMode(2, OUTPUT);
  digitalWrite(2, HIGH);
}

void loop() {
  buttonState = digitalRead(3);

  if ( (millis() - lastDebounceTime) > debounceDelay) {
    if ( (buttonState == HIGH) && (capslock == 0) ) {
      digitalWrite(2, LOW); //turn LED on
      capslock=1;
      lastDebounceTime = millis(); //set the current time
    }
    else if ( (buttonState == HIGH) && (capslock != 0) ) {
      digitalWrite(2, HIGH); //turn LED off
      capslock=0;
      lastDebounceTime = millis(); //set the current time
    }
  }
}

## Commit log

2022-06-30 PCB routed
    [8bit16bitSwitch.kicad_sch, AddressDecoding.kicad_sch, CPU.kicad_sch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]
2022-10-16 unicorn work
    [8bit16bitSwitch.kicad_sch, AddressDecoding.kicad_sch, CPU.kicad_sch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]
2022-10-17 Doc Updates
    [CartRiser-B_Cu.gbr, CartRiser-B_Mask.gbr, CartRiser-B_Paste.gbr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]
2022-10-23 unicorn firmware working
    [Console-B_Mask.gbr, Console-B_Paste.gbr, Console-B_Silkscreen.gbr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]
2022-10-25 PCB correction
    [Keyboard-B_Cu.gbr, Keyboard-B_Mask.gbr, Keyboard-Edge_Cuts.gbr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]
2022-10-25 trim cart riser
    [CartRiser-B_Cu.gbr, CartRiser-B_Mask.gbr, CartRiser-B_Paste.gbr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]
2022-10-25 rework IO Riser
    [IO_Riser-B_Cu.gbr, IO_Riser-B_Mask.gbr, IO_Riser-B_Paste.gbr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]
2022-11-05 Shrink PCB
    [Console.kicad_sch, GROM-IO-Port.kicad_sch, GROM-Logic.kicad_sch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]
2022-11-14 hardware updates
    [AddressDecoding.kicad_sch, Console.kicad_pcb, Console.kicad_sch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]
2022-11-20 Add BOM
    [Cart_Riser.stl, Console-bom.csv, Console-bom.xlsx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]
2022-11-20 PCB updates
    [Console-B_Cu.gbr, Console-B_Mask.gbr, Console-B_Paste.gbr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]
2022-12-13 PCB cleanup
    [8bit16bitSwitch.kicad_sch, AddressDecoding.kicad_sch, CPU.kicad_sch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]
2022-12-25 PCB power fix
    [CPU.kicad_sch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]
2022-12-27 PCB rework
    [8bit16bitSwitch.kicad_sch, AddressDecoding.kicad_sch, CPU.kicad_sch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]
2022-12-27 PCB BOM
    [Console.csv]
2023-01-09 3d models
    [TI99Case.scad, TI99Case_top.stl, unicorn.stl]
2023-01-21 PCB 0.96
    [8bit16bitSwitch.kicad_sch, AddressDecoding.kicad_sch, CPU.kicad_sch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]
2023-03-30 case work
    [TI99Case.scad, TI99Case_top.stl]
2023-07-13 Correct PCB PDF
